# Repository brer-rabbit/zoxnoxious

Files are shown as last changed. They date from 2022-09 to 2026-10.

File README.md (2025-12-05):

# Zoxnoxious Analog Synthesizer #

"Beyond Obnoxious"

Zoxnoxious is a hardware analog music synthesizer with a software interface.  The intent is to provide a platform for card/module development ("card" may be a better term than "module", as the latter is a well established term in the modular synth world).  Cards interface via a Raspberry Pi to a host controller over USB, and the host controller runs VCV Rack which provides control signals.

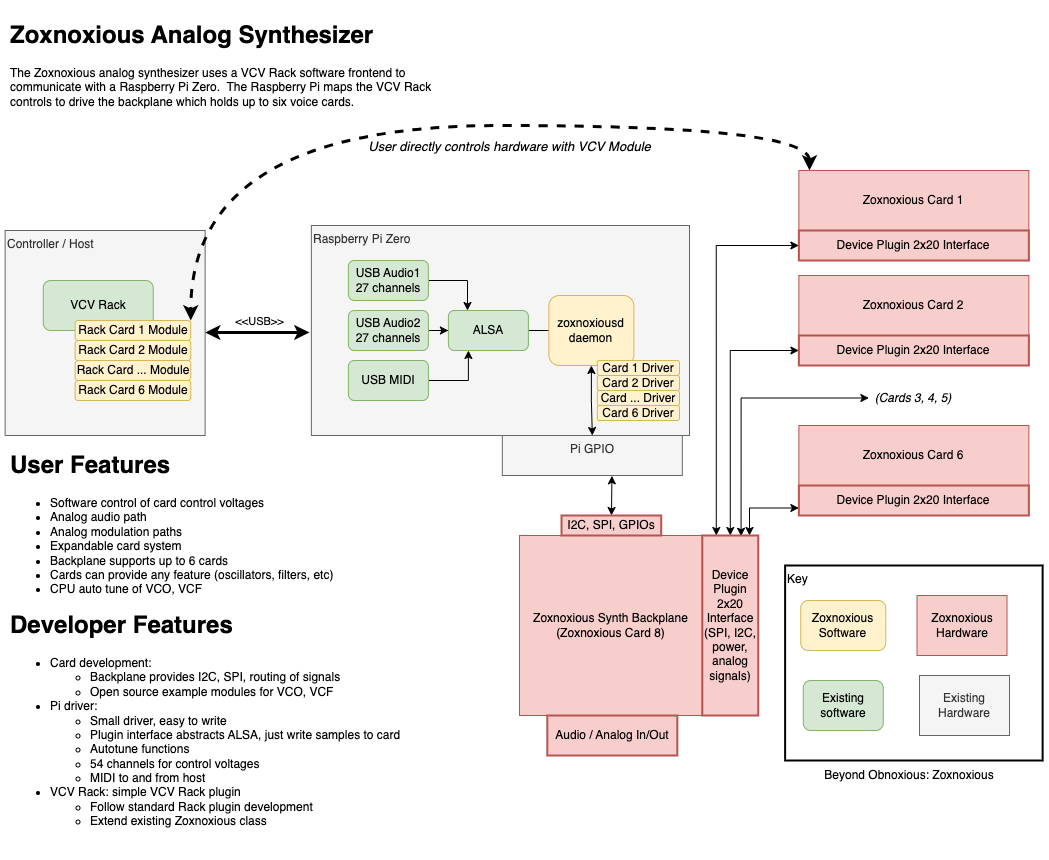
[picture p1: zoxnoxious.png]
Zonoxious Block Diagram


# Z-Cards #

Z-Cards are the voice cards that plug into the Zoxnoxious backplane.  Each card receives digital signals such as I2C and SPI along with analog signals from other Z-Cards.  Then each Z-Card drives a defined set of pins with its own analog output.

The Z-Cards are agnostic to the microcontroller; the interface being I2C and SPI most any microcontroller can be used.  While the overall Zoxnoxious project focuses on a Raspberry Pi implementation a different project can pickup the voice cards and do something different.  These cards are ripe for re-use in developing an analog synth with a microcontroller if you want to do your own thing and not use a Raspberry Pi like I have done in this project.

All Z-Cards are in the [kicad](kicad) directory.

Cards developed to date include:

* AS3340 VCO
* AS3372 Signal Processor (VCF, VCA)
* SSI2130/AS3394 Dual VCO + VCF Synth Voice
* Pole Dancer multimode filter with morphing/crossfade

The backplane design allows for up to 8 cards to be addressed with itself counting as one.  One control address goes unused as the backplane board design only has 6 physical slots.

# Raspberry Pi Host #

A Raspberry Pi Zero 2 attaches to the Zoxnoxious backplane.  To a host computer, the Pi appears as USB Audio and USB MIDI devices.  Incoming USB Audio and MIDI are dispatched to a card's driver, which may choose to send SPI or I2C messages to the card.

The application the Pi runs is contained entirely in the [raspberry_pi](raspberry_pi) directory.

# Zoxnoxious plugins for VCV Rack #

The user interacts with the synth through a VCV Rack plugin.  Zoxnoxious VCV Rack plugins map the Rack modules to audio channels and MIDI events that are sent via USB to the synthesizer.

These are all contained in the [vcv_rack](vcv_rack) directory.

# Deep Dive Videos

Deep dive 1: Project background and user interface
YouTube Zoxnoxious Deep Dive Video (https://www.youtube.com/watch?v=LsGcW3EjFYo)

Deep dive 2: Raspberry Pi and Gadget mode
YouTube Zoxnoxious Deep Dive Video (https://www.youtube.com/watch?v=pGoO3mSk7ao)

Deep dive 3: Hardware detail and autotune
YouTube Zoxnoxious Deep Dive Video (https://www.youtube.com/watch?v=C-MREijqNOM)

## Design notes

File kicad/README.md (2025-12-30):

# Zoxnoxious KiCad Files

The directories below contain KiCad files for the Zoxnoxious synthesizer.  This includes files for both schematics, PCB layout, and assembly.  Some boards also have a datasheet.

# Voice cards

* [Z2203](z2203/): Yamaha FM-based voice card with YM2203 chip
* [Pole Dancer](poledancer/): pole mixing filter utilizing an SSI2140 and SSI2190
* [Z3340](z3340/): Oscillator based around an AS3340 with four sync modes that can be combined
* [Z3372](z3372/): Lowpass filter with AS3372 filter chip.  Stereo panning, filter and resonance modulation.
* [Z5524](z5524/): dual VCO voice card.  SSI2130 oscillator for TZFM, AS3394 for second VCO and filter.  Powerful.

# Backplane

The [backplane](vca_backplane/) hosts six voice cards and a Raspberry Pi Zero2.

# Frontpanel

[Frontpanel](frontpanel/) for project.

# Template for development

The [zoxnoxiouscard](zoxnoxiouscard/) directory has a template to run from for creating voice cards.  Includes DAC, GPIO expander, and layout for the same.

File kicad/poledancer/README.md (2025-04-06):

# Pole Dancer Multimode Pole Mixing Filter

The Pole Dancer may be the most versatile analog synthesizer filter.  Built around an SSI2140 four pole filter and an SSI2190 mixer provides the pole mixing.  A number of filter modes are possible using the filter mixing.  The real fun is morphing between filter modes, which can be done with manipulating the '2190 mixer.

Multiple resonance compensation modes, in addition to uncompensated, give a wide range of character.

# Block Diagram

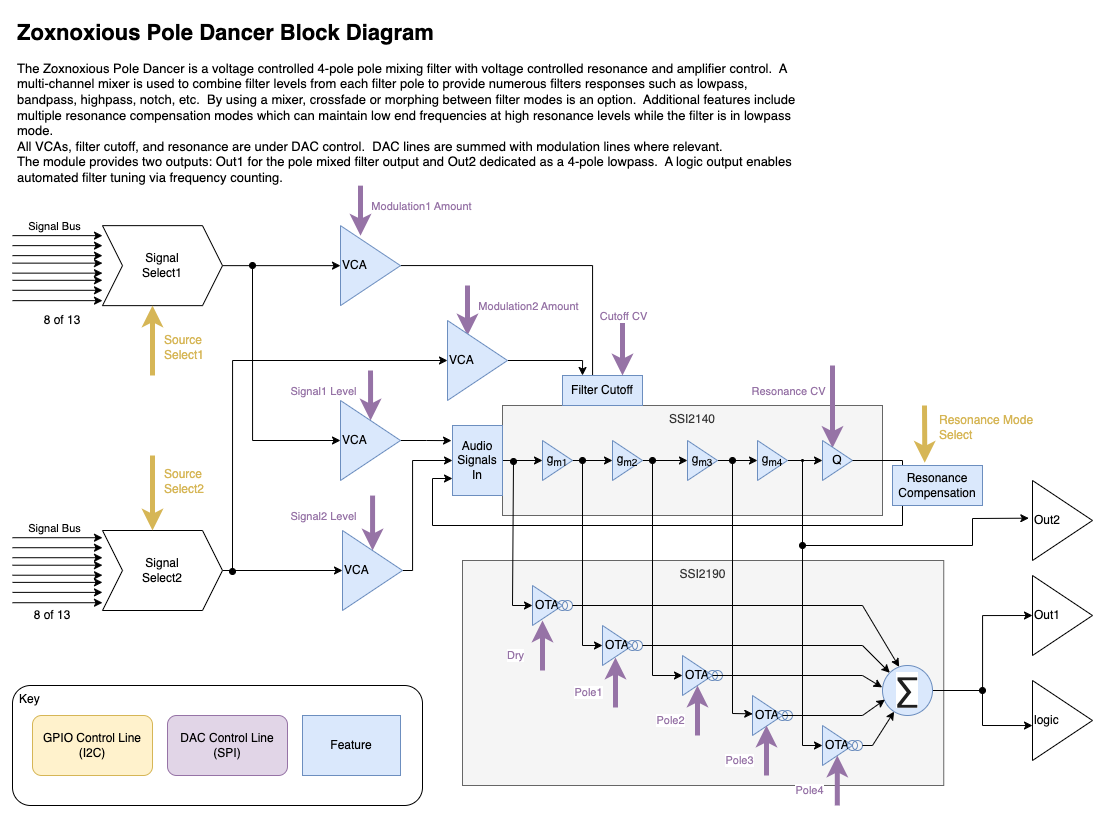
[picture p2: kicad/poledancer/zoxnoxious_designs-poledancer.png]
Pole Dancer Block Diagram


# Resources

Datasheet TBD

[KiCanvas](https://kicanvas.org/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)

# Demo

YouTube Demo

YouTube Z3340 Demo (https://www.youtube.com/watch?v=yQdGTCUl1eU)

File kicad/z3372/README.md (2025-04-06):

# Z3372 Voltage Controlled Filter & Noise Source

The Z3372 Analog Signal Processor utilized Alfa Rpar's AS3372 VCF/VCA.  It also contains a white noise source which can be run through the filter.  Some interseting modulation options are present, along with a stereo output.

# Block Diagram

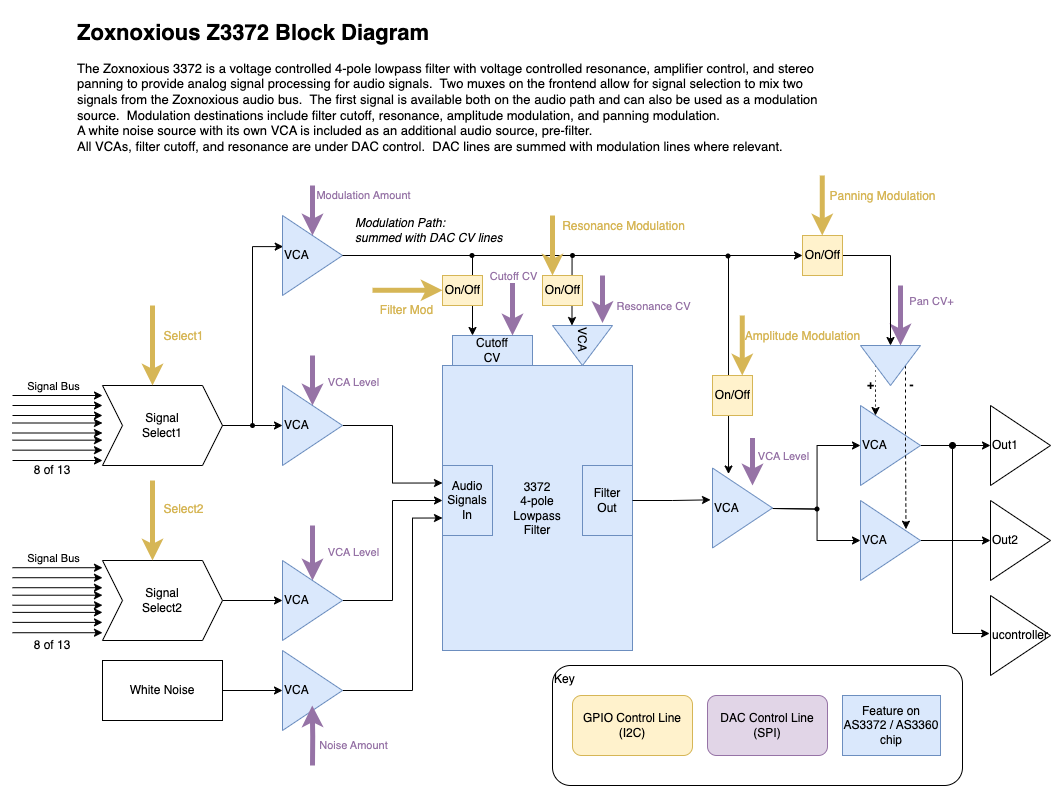
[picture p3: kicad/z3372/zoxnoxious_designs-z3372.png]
Z3372 Block Diagram


# Resources

[Datasheet](datasheet_z3372.pdf)

[KiCanvas](https://kicanvas.org/?github=https%3A%2F%2Fgithub.com%2Fbrer-rabbit%2Fzoxnoxious%2Ftree%2Fmain%2Fkicad%2Fz3372)

# Demo

(old!) YouTube Demo

YouTube Z3373 Demo (https://www.youtube.com/watch?v=ua1Tva17EMw)

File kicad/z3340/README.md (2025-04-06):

# Z3340 Voltage Controlled Oscillator

The Z3340 VCO is based around Alfa Rpar's AS3340 clone of the Curtis chip.  This design, like other Zoxnoxious designs, interfaces with the Zoxnoxious signal bus.

# Block Diagram

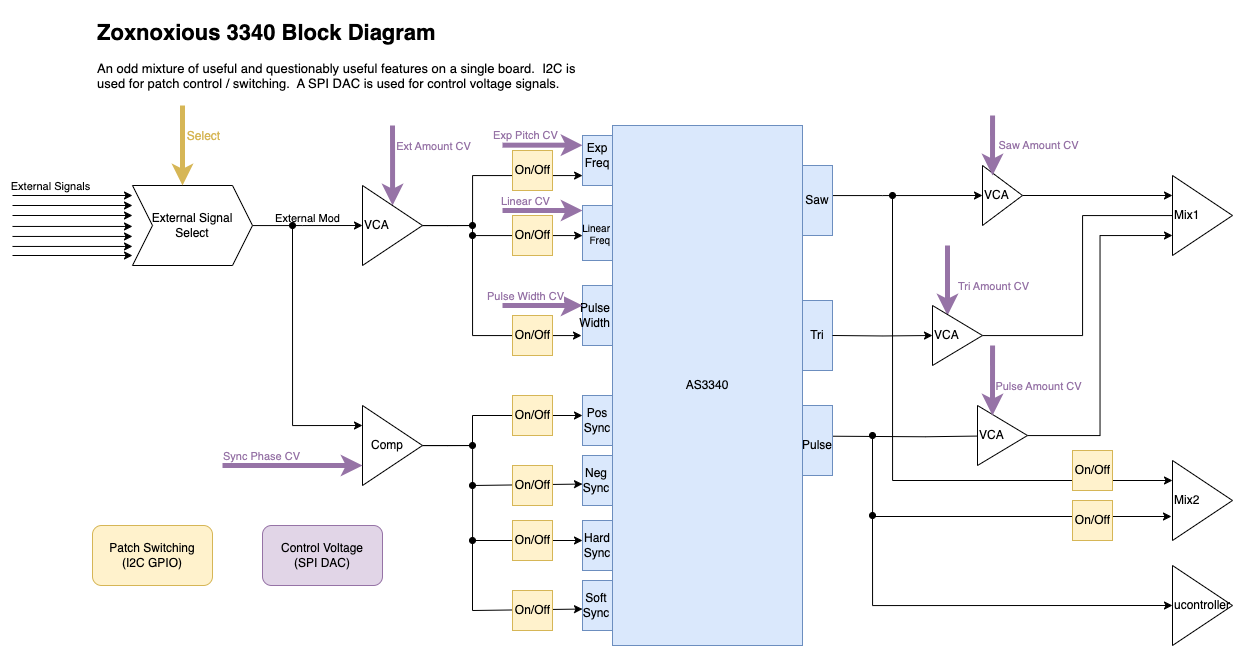
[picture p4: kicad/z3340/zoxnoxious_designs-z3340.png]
Z3340 Block Diagram


# Resources

[Datasheet](datasheet_3340.pdf)

[Kicanvas](https://kicanvas.org/?github=https%3A%2F%2Fgithub.com%2Fbrer-rabbit%2Fzoxnoxious%2Ftree%2Fmain%2Fkicad%2Fz3340)

# Demo

YouTube Demo

YouTube Z3340 Demo (https://www.youtube.com/watch?v=VoswYPXtnXY)

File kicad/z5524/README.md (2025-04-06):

# Z5524 Dual VCO Synth Voice

The Z5524 is a full dual VCO synth voice.  The first VCO is based around an SSI2130 and features thru zero frequency modulation (TZFM).  The second VCO is from the AS3394 synth-on-a-chip.  Both VCOs run through the AS3394's VCF and VCA.

Some unique options with this setup such as combining soft sync with hard subsync, modulating the AS3394's waveselect, and some interesting options for the TZFM modulator from the AS3394 VCO.

# Block Diagram

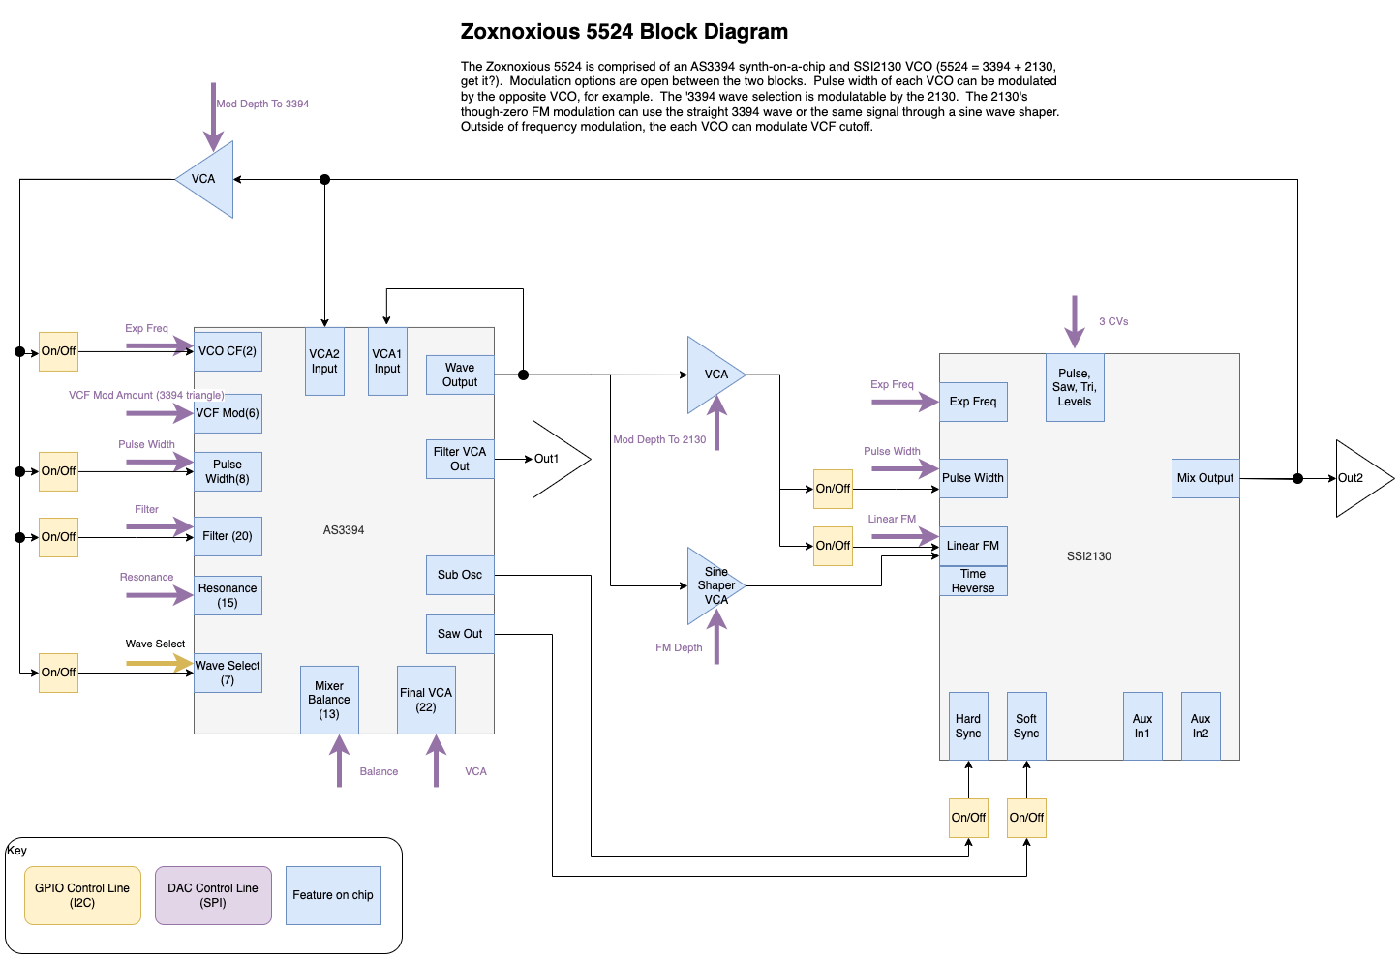
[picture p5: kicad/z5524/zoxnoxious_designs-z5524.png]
Z5524 Block Diagram


# Resources

Datasheet TBD

[KiCanvas](https://kicanvas.org/?github=https%3A%2F%2Fgithub.com%2Fbrer-rabbit%2Fzoxnoxious%2Ftree%2Fmain%2Fkicad%2Fz5524)

# Demo

YouTube Demo

YouTube Z5524 Demo (https://www.youtube.com/watch?v=vYZjghBTEKc)

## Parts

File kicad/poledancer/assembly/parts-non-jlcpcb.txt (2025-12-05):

"Conn_01x01","J1","Connector_PinHeader_2.54mm:PinHeader_1x01_P2.54mm_Vertical",""
"Conn_01x02","J2","Connector_PinHeader_2.54mm:PinHeader_1x02_P2.54mm_Vertical",""
"Conn_02x20_Odd_Even","J3","Connector_PinHeader_2.54mm:PinHeader_2x20_P2.54mm_Horizontal",""
"5k","RV1,RV2","Potentiometer_THT:Potentiometer_Bourns_3296W_Vertical",""
"TestPoint","TP1,TP2,TP3,TP4,TP5,TP6,TP7,TP8,TP9,TP10,TP11,TP12,TP13,TP14,TP15","TestPoint:TestPoint_Pad_2.0x2.0mm",""
"SSI2190","U2","Package_SO:SSOP-24_3.9x8.7mm_P0.635mm",""
"AS3364","U3","Package_SO:SOIC-16_3.9x9.9mm_P1.27mm",""
"SSI2140","U5","Package_SO:SSOP-20_4.4x6.5mm_P0.65mm",""
"1000p","C14,C16,C17,C18","Capacitor_SMD:C_0805_2012Metric",""

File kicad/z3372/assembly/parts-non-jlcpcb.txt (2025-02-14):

"2u2","C34,C38","Capacitor_THT:C_Rect_L7.2mm_W5.5mm_P5.00mm_FKS2_FKP2_MKS2_MKP2",""
"Conn_01x01","J1","Connector_PinHeader_2.54mm:PinHeader_1x01_P2.54mm_Vertical",""
"Conn_02x20_Odd_Even","J2","Connector_PinHeader_2.54mm:PinHeader_2x20_P2.54mm_Horizontal",""
"Conn_01x02","J3","Connector_PinHeader_2.54mm:PinHeader_1x02_P2.54mm_Vertical",""
"TestPoint","TP1,TP2,TP3,TP4,TP5,TP6,TP7,TP8,TP9,TP10,TP11","TestPoint:TestPoint_Pad_2.0x2.0mm",""
"AS3360-Audio","U1","Package_SO:SOIC-14_3.9x8.7mm_P1.27mm",""
"AS3372","U3","Package_SO:SOIC-24W_7.5x15.4mm_P1.27mm",""
"L79L05_TO92","U9","Package_TO_SOT_THT:TO-92_Inline_Wide",""

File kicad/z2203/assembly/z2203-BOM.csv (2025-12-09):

Comment | Designator | Footprint | LCSC
0.1u | C1,C2,C3,C4,C5,C7,C8,C9,C10 | Capacitor_SMD:C_0603_1608Metric | C14663
10u | C6 | Capacitor_SMD:C_0805_2012Metric | C15850
LED | D1,D2 | LED_SMD:LED_0603_1608Metric | C2286
4k7 | R1,R11 | Resistor_SMD:R_0603_1608Metric | C23162
5k1 | R10 | Resistor_SMD:R_0603_1608Metric | C23186
47k | R2,R4,R5,R7,R8,R9 | Resistor_SMD:R_0603_1608Metric | C25819
51 | R3,R6 | Resistor_SMD:R_0603_1608Metric | C23197
74HC00 | U3 | Package_SO:SOIC-14_3.9x8.7mm_P1.27mm | C10090
74HC595 | U4,U7 | Package_SO:TSSOP-16_4.4x5mm_P0.65mm | C273642
TL074 | U5 | Package_SO:TSSOP-14_4.4x5mm_P0.65mm | C96507
M24C02-WMN | U6 | Package_SO:SOIC-8_3.9x4.9mm_P1.27mm | C7562
SX3M3.57 | X1 | Oscillator:Oscillator_SMD_Abracon_ASE-4Pin_3.2x2.5mm | C41361373

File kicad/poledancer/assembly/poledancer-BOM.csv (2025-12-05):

Comment | Designator | Footprint | LCPCB Part #
4n7 | C13 | Capacitor_SMD:C_0603_1608Metric | C53987
2u2 | C21 | Capacitor_SMD:C_0603_1608Metric | C23630
22n | C23,C39,C40,C41 | Capacitor_SMD:C_0603_1608Metric | C21122
0.1u | C1,C2,C3,C4,C5,C8,C10,C11,C12,C15,C19,C20,C24,C26,C28,C29,C31,C32,C33,C35,C37,C38,C42,C43,C45 | Capacitor_SMD:C_0603_1608Metric | C14663
22p | C30 | Capacitor_SMD:C_0603_1608Metric | C1653
100p | C36 | Capacitor_SMD:C_0603_1608Metric | C14858
4u7 | C9,C44 | Capacitor_SMD:C_0603_1608Metric | C19666
47n | C6,C7,C22,C25,C27,C34 | Capacitor_SMD:C_0603_1608Metric | C1622
1N4148W | D1 | Diode_SMD:D_SOD-123 | C81598
LED | D2 | LED_SMD:LED_0603_1608Metric | C2286
MMBT3904 | Q1 | Package_TO_SOT_SMD:SOT-23 | C20526
20k | R1,R2,R18,R19,R24,R28,R33,R41,R56,R61,R67 | Resistor_SMD:R_0603_1608Metric | C4184
6k2 | R13,R14,R16,R17,R40,R48,R50,R51,R53,R55,R57 | Resistor_SMD:R_0603_1608Metric | C4260
3k9 | R15,R54 | Resistor_SMD:R_0603_1608Metric | C23018
15k | R23,R43,R70 | Resistor_SMD:R_0603_1608Metric | C22809
100 | R29 | Resistor_SMD:R_0603_1608Metric | C22775
220 | R3,R5,R7,R8,R20,R21,R22,R26,R27,R30,R31,R32 | Resistor_SMD:R_0603_1608Metric | C22962
12k | R38 | Resistor_SMD:R_0603_1608Metric | C22790
1k | R44 | Resistor_SMD:R_0603_1608Metric | C21190
3k | R52,R72 | Resistor_SMD:R_0603_1608Metric | C4211
100k | R4,R25,R58,R60,R63,R64 | Resistor_SMD:R_0603_1608Metric | C25803
5k1 | R59 | Resistor_SMD:R_0603_1608Metric | C23186
200 | R6,R35,R46,R47 | Resistor_SMD:R_0603_1608Metric | C8218
51 | R62,R65 | Resistor_SMD:R_0603_1608Metric | C23197
150k | R66 | Resistor_SMD:R_0603_1608Metric | C22807
33k | R68 | Resistor_SMD:R_0603_1608Metric | C4216
24k | R69 | Resistor_SMD:R_0603_1608Metric | C23352
82k | R73,R79,R80,R81 | Resistor_SMD:R_0603_1608Metric | C23254
18k | R12,R74,R76,R77,R78 | Resistor_SMD:R_0603_1608Metric | C25810
10k | R9,R10,R11,R34,R36,R37,R39,R42,R45,R49,R71,R75,R83 | Resistor_SMD:R_0603_1608Metric | C25804
4k7 | R82 | Resistor_SMD:R_0603_1608Metric | C23162
TL074 | U1,U4,U10 | Package_SO:TSSOP-14_4.4x5mm_P0.65mm | C96507
M24C02-WMN | U12 | Package_SO:SOIC-8_3.9x4.9mm_P1.27mm | C7562
PCA9555D | U13 | Package_SO:TSSOP-24_4.4x7.8mm_P0.65mm | C83265
AD5328 | U6,U14 | Package_SO:TSSOP-16_4.4x5mm_P0.65mm | C29162
DG442xY | U7 | Package_SO:SOIC-16_3.9x9.9mm_P1.27mm | C2673321
LM4040AIM3-2.5 | U8 | Package_TO_SOT_SMD:SOT-23 | C111866
PS508 | U9,U11 | Package_SO:SOIC-16_3.9x9.9mm_P1.27mm | C2673104

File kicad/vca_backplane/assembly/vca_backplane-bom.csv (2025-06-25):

Comment | Designator | Footprint | LCSC Part #
4.7u | C1 | Capacitor_SMD:C_0805_2012Metric | C1779
4.7n | C11 | Capacitor_SMD:C_0603_1608Metric | C53987
100p | C24,C25 | Capacitor_SMD:C_0603_1608Metric | C14858
0.1u | C2,C3,C4,C5,C6,C7,C8,C9,C10,C13,C14,C15,C16,C17,C18,C20,C21,C22,C23,C26,C27 | Capacitor_SMD:C_0603_1608Metric | C14663
LED | D1 | LED_SMD:LED_0603_1608Metric | C2286
DMG2305UX | Q1 | project_footprints:SOT-23-DMG2305UX | C150470
DMMT5401 | Q2 | Package_TO_SOT_SMD:SOT-23-6 | C154733
BSS138 | Q3,Q4 | Package_TO_SOT_SMD:SOT-23 | C82045
51 | R13 | Resistor_SMD:R_0603_1608Metric | C23197
4k7 | R18 | Resistor_SMD:R_0603_1608Metric | C23162
100 | R27,R28 | Resistor_SMD:R_0603_1608Metric | C22775
47k | R1,R4,R5,R9,R10,R12,R14,R17,R19,R21,R22,R23,R24,R25,R26 | Resistor_SMD:R_0603_1608Metric | C25819
10k | R2,R3,R6,R15,R16 | Resistor_SMD:R_0603_1608Metric | C25804
3k3 | R7,R8 | Resistor_SMD:R_0603_1608Metric | C22978
DG442xY | U1,U9,U12 | Package_SO:SOIC-16_3.9x9.9mm_P1.27mm | C2673321
74HCT138 | U10,U11 | Package_SO:TSSOP-16_4.4x5mm_P0.65mm | C8115
NE5532 | U13 | Package_SO:SOIC-8_3.9x4.9mm_P1.27mm | C7426
TL072 | U2 | Package_SO:SOIC-8_3.9x4.9mm_P1.27mm | C6961
MCP4822 | U3 | Package_SO:SOIC-8_3.9x4.9mm_P1.27mm | C16040
M24C02-WMN | U4 | Package_SO:SOIC-8_3.9x4.9mm_P1.27mm | C7562
74HCT245 | U6 | Package_SO:TSSOP-20_4.4x6.5mm_P0.65mm | C5980
74LVC245 | U7 | Package_SO:TSSOP-20_4.4x6.5mm_P0.65mm | C6082
PCA9555PW | U8 | Package_SO:TSSOP-24_4.4x7.8mm_P0.65mm | C83265

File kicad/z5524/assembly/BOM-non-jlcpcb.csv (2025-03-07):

Item | Qty | Reference(s) | Value | LibPart | Footprint | Datasheet | DNP | Digikey | Kemet | LCSC | Mouser | Rubycon | Sim.Device | Sim.Pins | TDK
10 | 2 | C33, C45 | 4u7 | Device:C_Polarized | Capacitor_THT:CP_Radial_D4.0mm_P2.00mm | ~ |  | 1189-4115-ND |  |  |  | 35MS54R7MEFC4X5
13 | 3 | C44, C50, C53 | 33n | Device:C | Capacitor_SMD:C_0805_2012Metric | ~ |  | 445-7523-1-ND |  |  |  |  |  |  | C2012C0G1H333J125AA
16 | 2 | C59, C63 | 1u | Device:C_Polarized | Capacitor_Tantalum_SMD:CP_EIA-3216-10_Kemet-I | ~ |  |  | T491A105K016AT |  | 80-T491A105K016
17 | 1 | C60 | 2n | Device:C | Capacitor_SMD:C_1206_3216Metric | ~ |  | C1206X202FBGAC7800
22 | 1 | J1 | Conn_01x01 | Connector_Generic:Conn_01x01 | Connector_PinHeader_2.54mm:PinHeader_1x01_P2.54mm_Vertical | ~
23 | 1 | J2 | Conn_02x20_Odd_Even | Connector_Generic:Conn_02x20_Odd_Even | Connector_PinHeader_2.54mm:PinHeader_2x20_P2.54mm_Horizontal | ~
24 | 1 | J3 | Conn_01x02 | Connector_Generic:Conn_01x02 | Connector_PinHeader_2.54mm:PinHeader_1x02_P2.54mm_Vertical | ~
59 | 2 | RV1, RV2 | 5k | Device:R_Potentiometer | Potentiometer_THT:Potentiometer_Bourns_3296W_Vertical | ~
60 | 11 | TP1, TP2, TP3, TP4, TP5, TP6, TP7, TP8, TP9, TP10, TP11 | TestPoint | Connector:TestPoint | TestPoint:TestPoint_Pad_1.5x1.5mm | ~
62 | 1 | U2 | SSI2130_no_pad | z5524:SSI2130_no_pad | project_footprints:QFN-32-1EP_4x4mm_P0.4mm_EP2.65x2.65mm_Handsolder_NoPad | https://www.soundsemiconductor.com/downloads/ssi2130datasheet.pdf
64 | 2 | U4, U18 | AD5328 | z5524:AD5328 | Package_SO:TSSOP-16_4.4x5mm_P0.65mm | https://www.analog.com/en/products/ad5308.html |  |  |  | C29162
65 | 1 | U6 | AS3364 | z5524:AS3364 | Package_SO:SOIC-16_3.9x9.9mm_P1.27mm | https://cabintechglobal.com/pdf/ALFA_RPAR_AS3364.pdf
68 | 1 | U9 | LM337L_TO92 | Regulator_Linear:LM337L_TO92 | Package_TO_SOT_THT:TO-92_Inline_Wide | http://www.ti.com/lit/ds/symlink/lm337l.pdf
71 | 1 | U15 | AS3394 | z5524:AS3394 | Package_SO:SOIC-24W_7.5x15.4mm_P1.27mm

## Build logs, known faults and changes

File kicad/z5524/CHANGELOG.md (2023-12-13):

# Changelog

	## V0.3 12/12/2023
	### Changes
	- All VCAs lowered RC filters to few hundred hertz
	- Pulse width modulation on both VCOs use summing amps, not passive
	- Remove extraneous opamps
	- Wave select modulation increased
	- Wave select bias points changed
	- 3394 VCO output increased amplification
	- 3394 VCO frequency range increased
	- 3394 VCF range adjused
	- Frequency Modulation amount greatly increased
	- 2130 Levels reduced to match 3394

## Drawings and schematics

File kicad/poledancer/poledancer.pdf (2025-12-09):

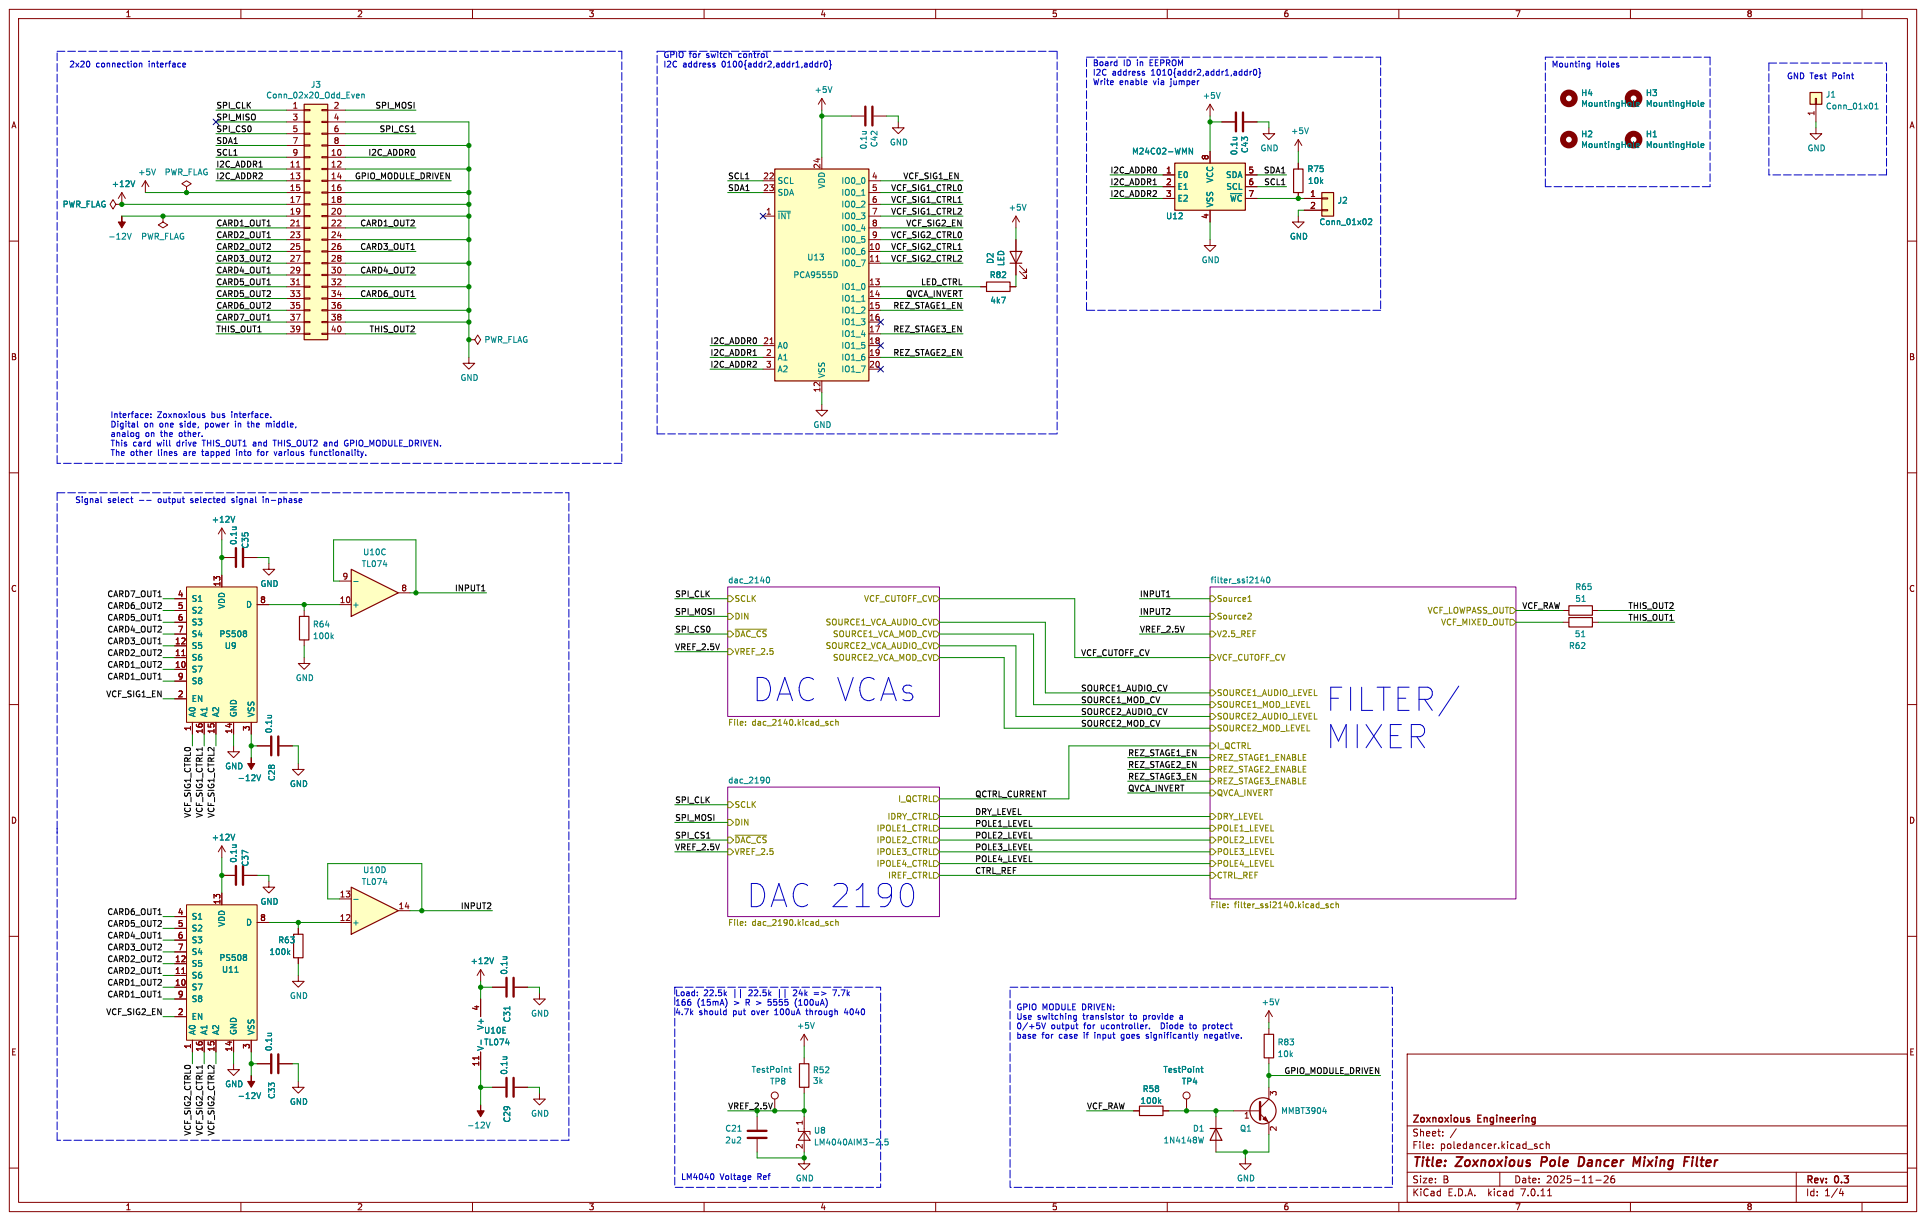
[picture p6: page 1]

GND Test Point GPIO for switch control I2C address 0100{addr2,addr1,addr0}
Mounting Holes FILTER/

Board ID in EEPROM
I2C address 1010{addr2,addr1,addr0} Write enable via jumper

4 SDA 5 SCL 6 ~{WC}7 VCC

1 S7 10 S6 11 S5 12 VDD 13 GND 14 A2 15 A1 16 EN 2 VSS

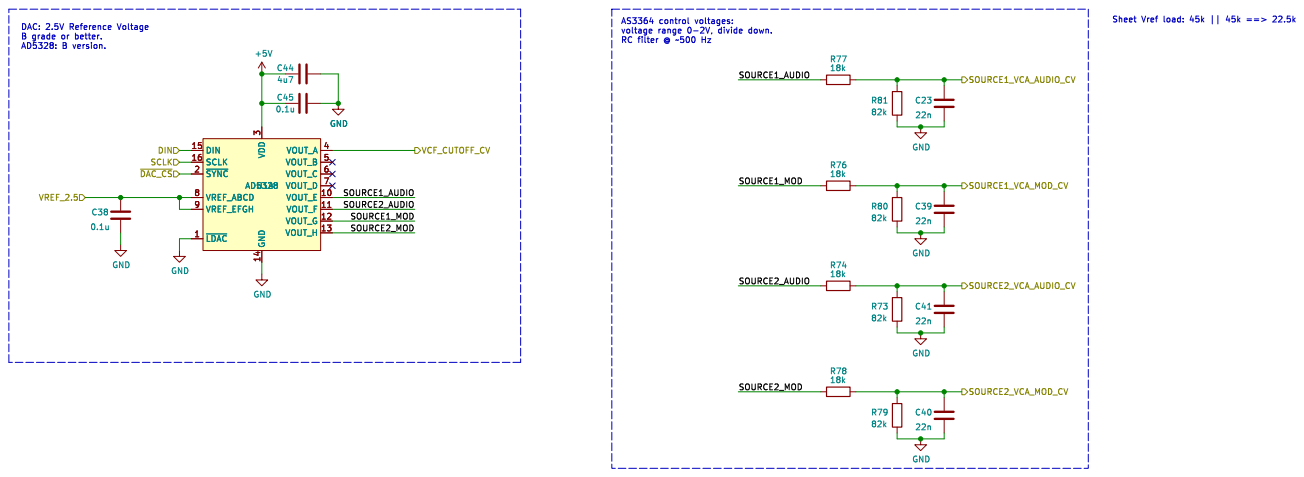
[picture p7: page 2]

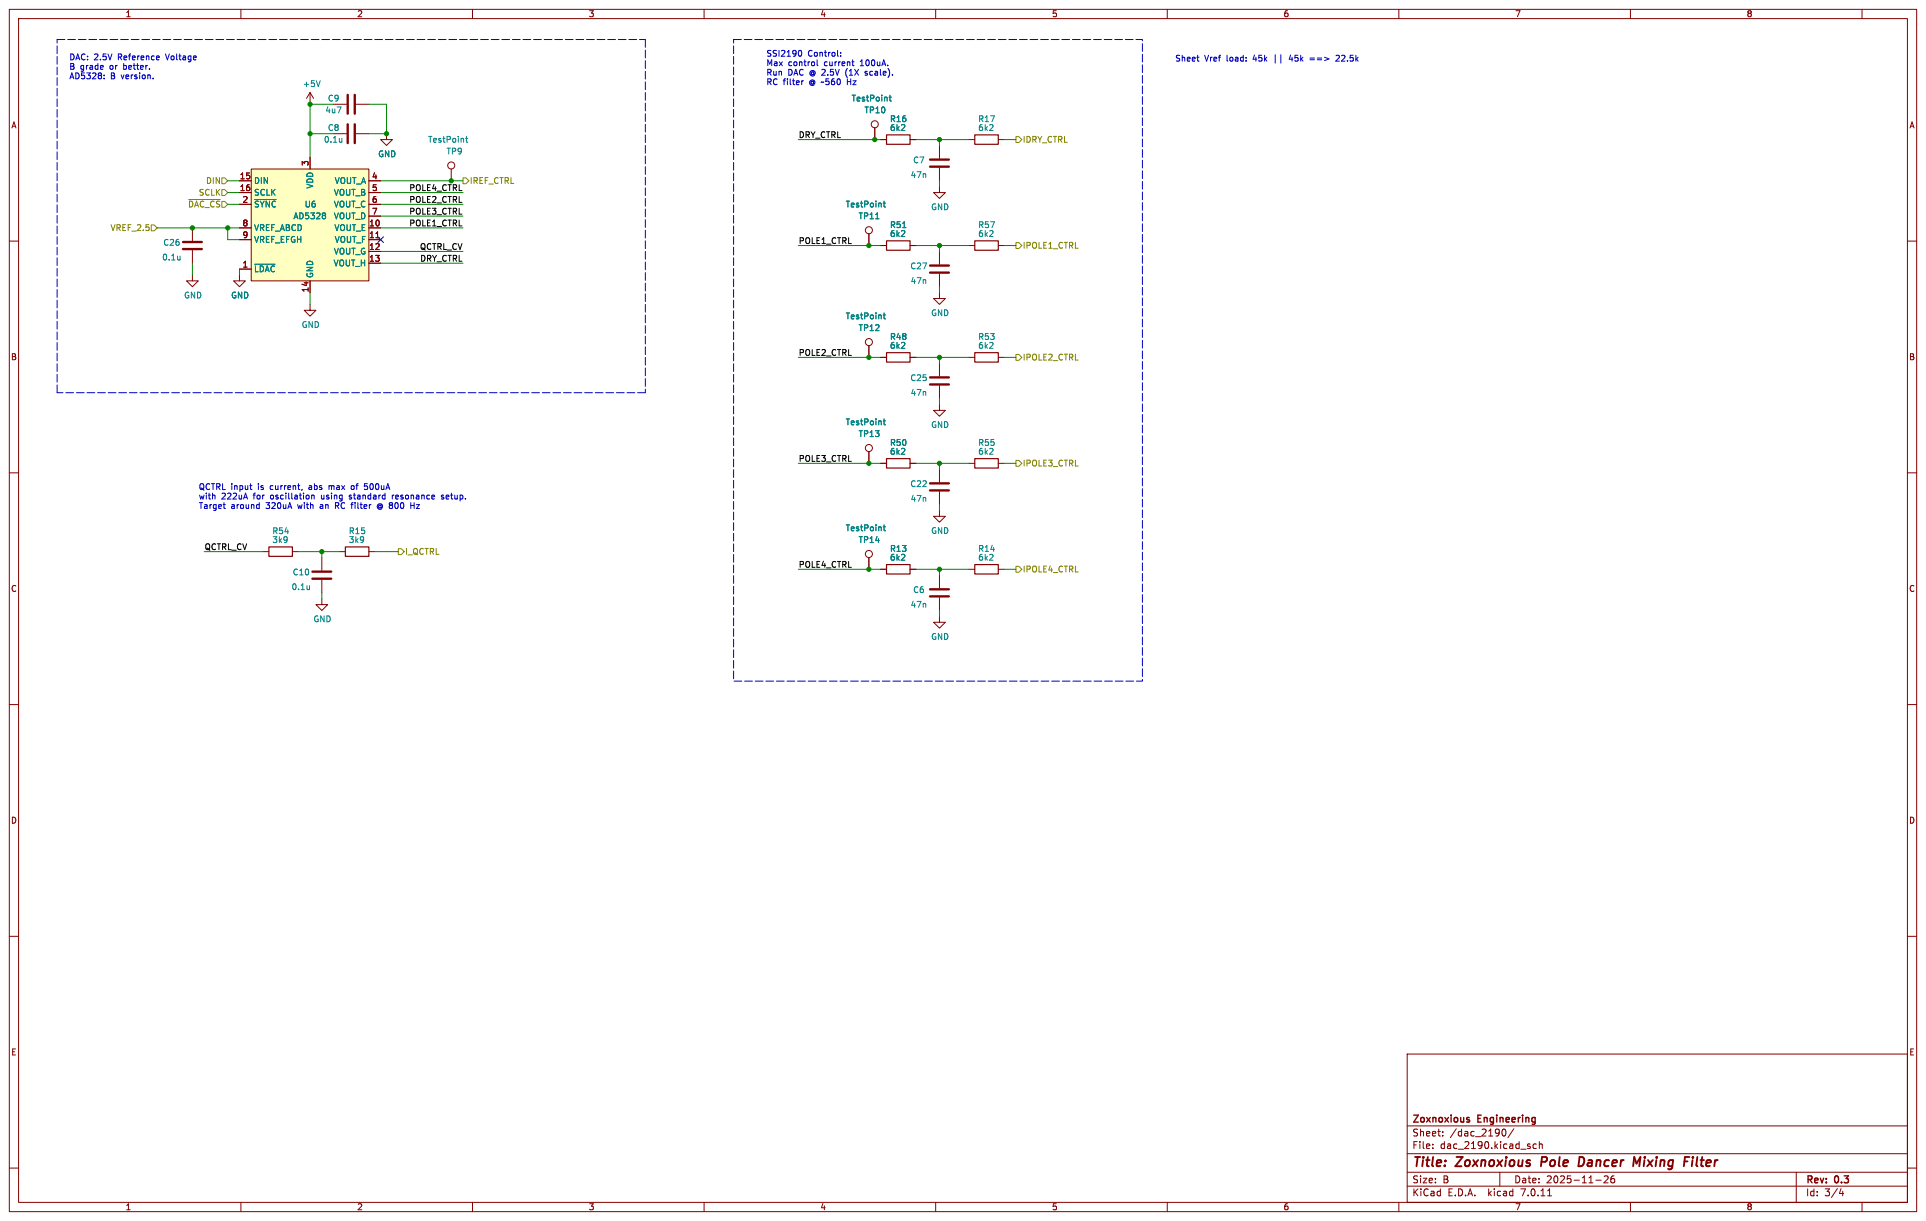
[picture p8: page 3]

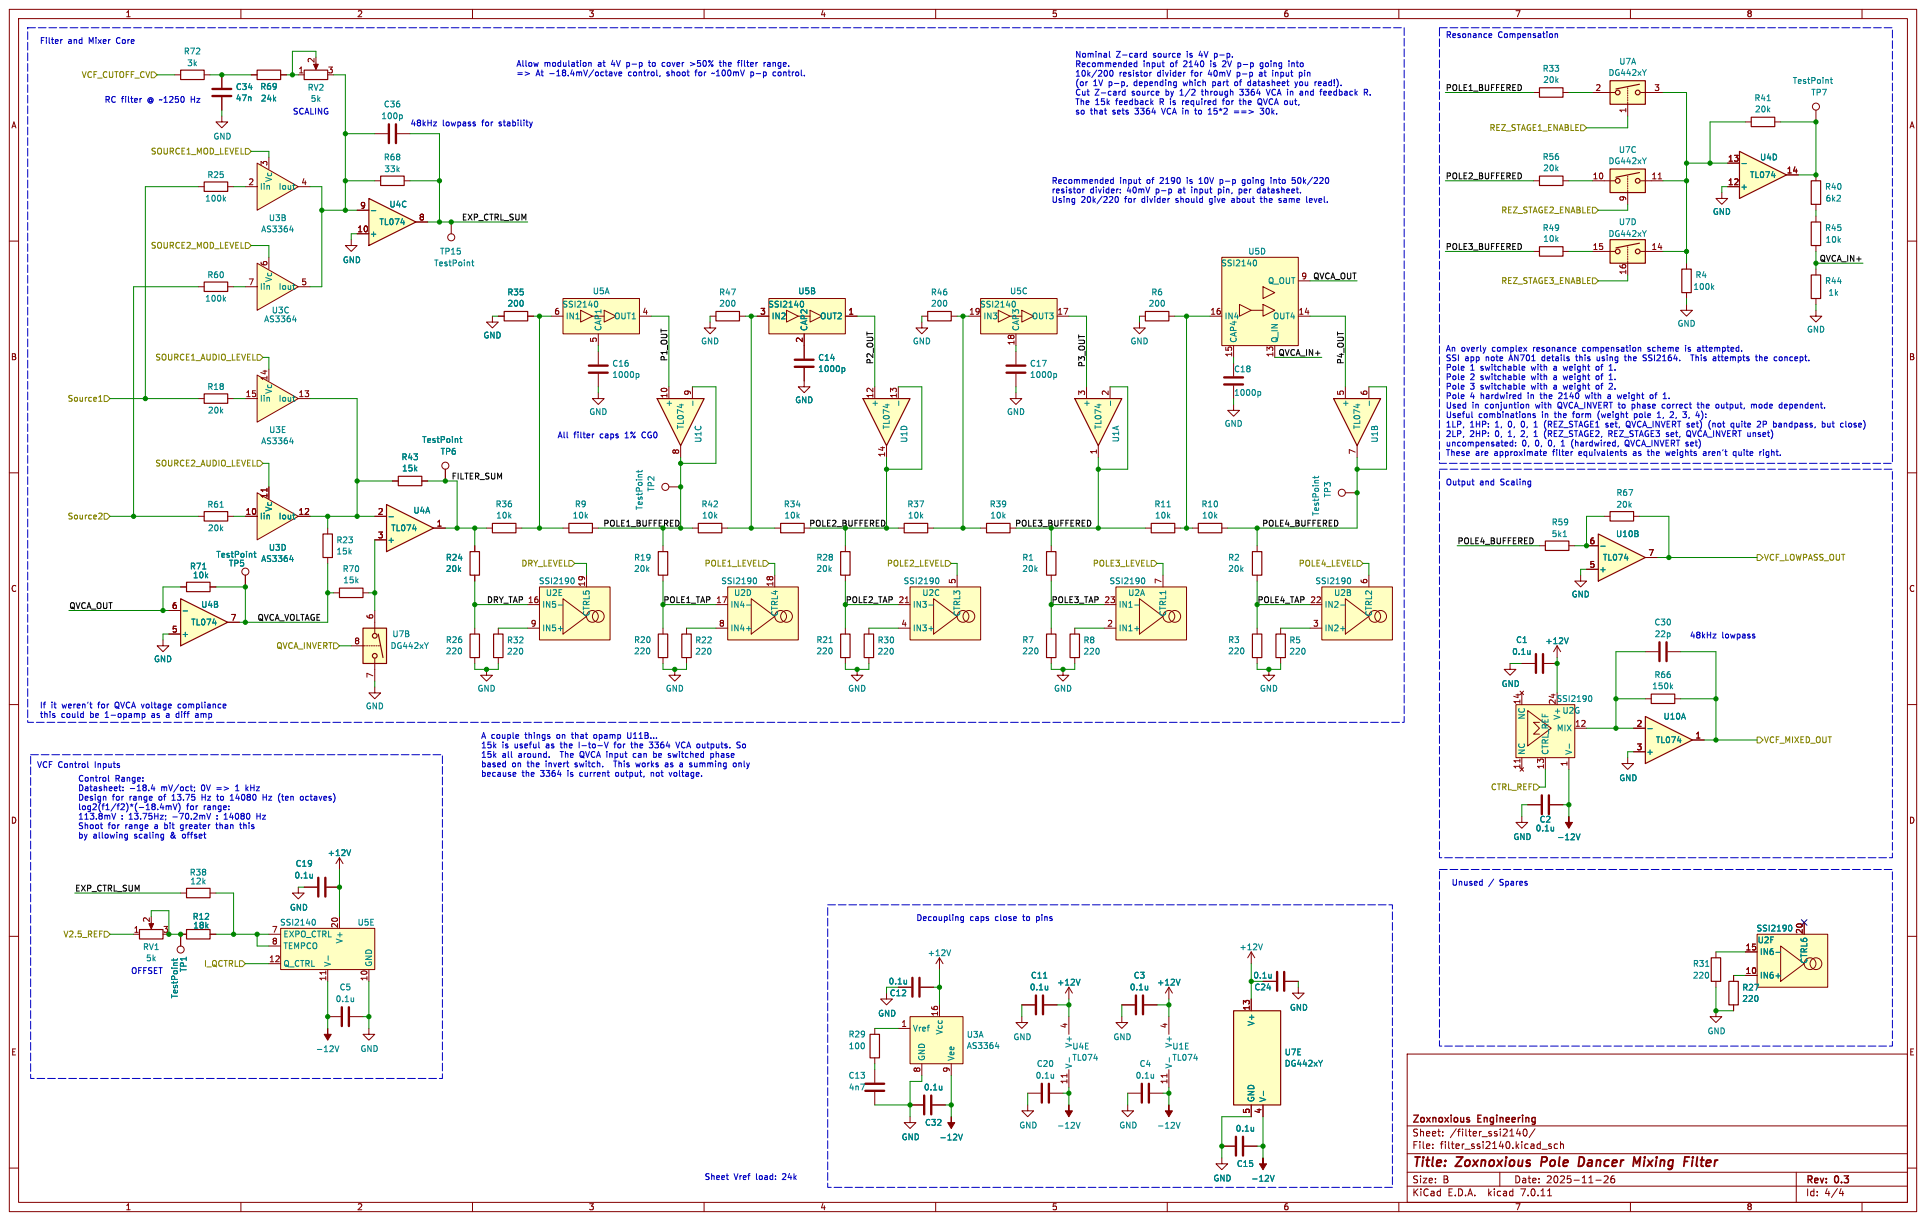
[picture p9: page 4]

Filter and Mixer Core

Output and Scaling OFFSET

If it weren't for QVCA voltage compliance

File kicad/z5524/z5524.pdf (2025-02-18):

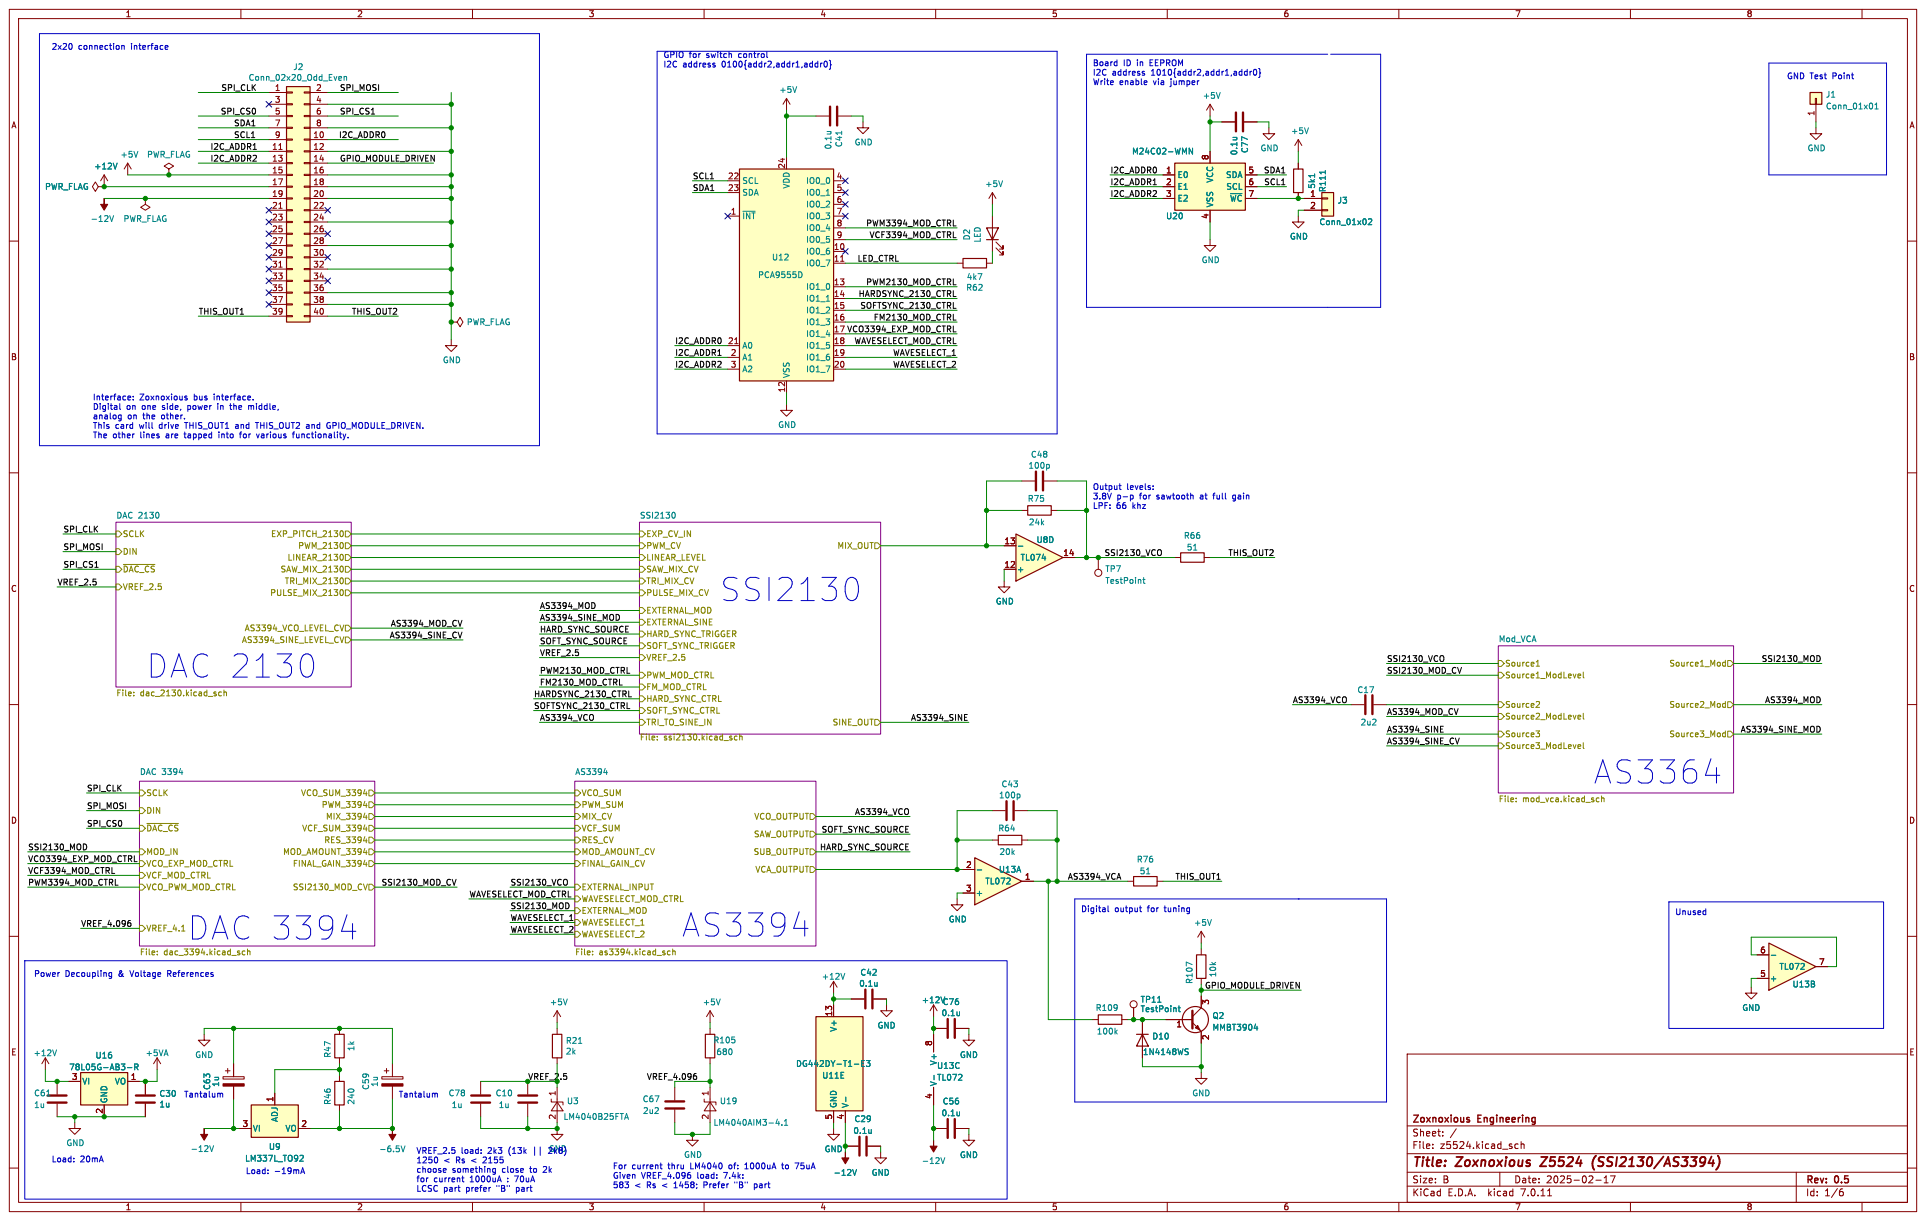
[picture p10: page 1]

GPIO for switch control I2C address 0100{addr2,addr1,addr0}

Board ID in EEPROM
I2C address 1010{addr2,addr1,addr0} Write enable via jumper

4 SDA 5 SCL 6 ~{WC}7 VCC

Digital output for tuning

for current 1000uA : 70uA
LCSC part prefer "B" part

For current thru LM4040 of: 1000uA to 75uA Given VREF_4.096 load: 7.4k: 583 < Rs < 1458; Prefer "B" part

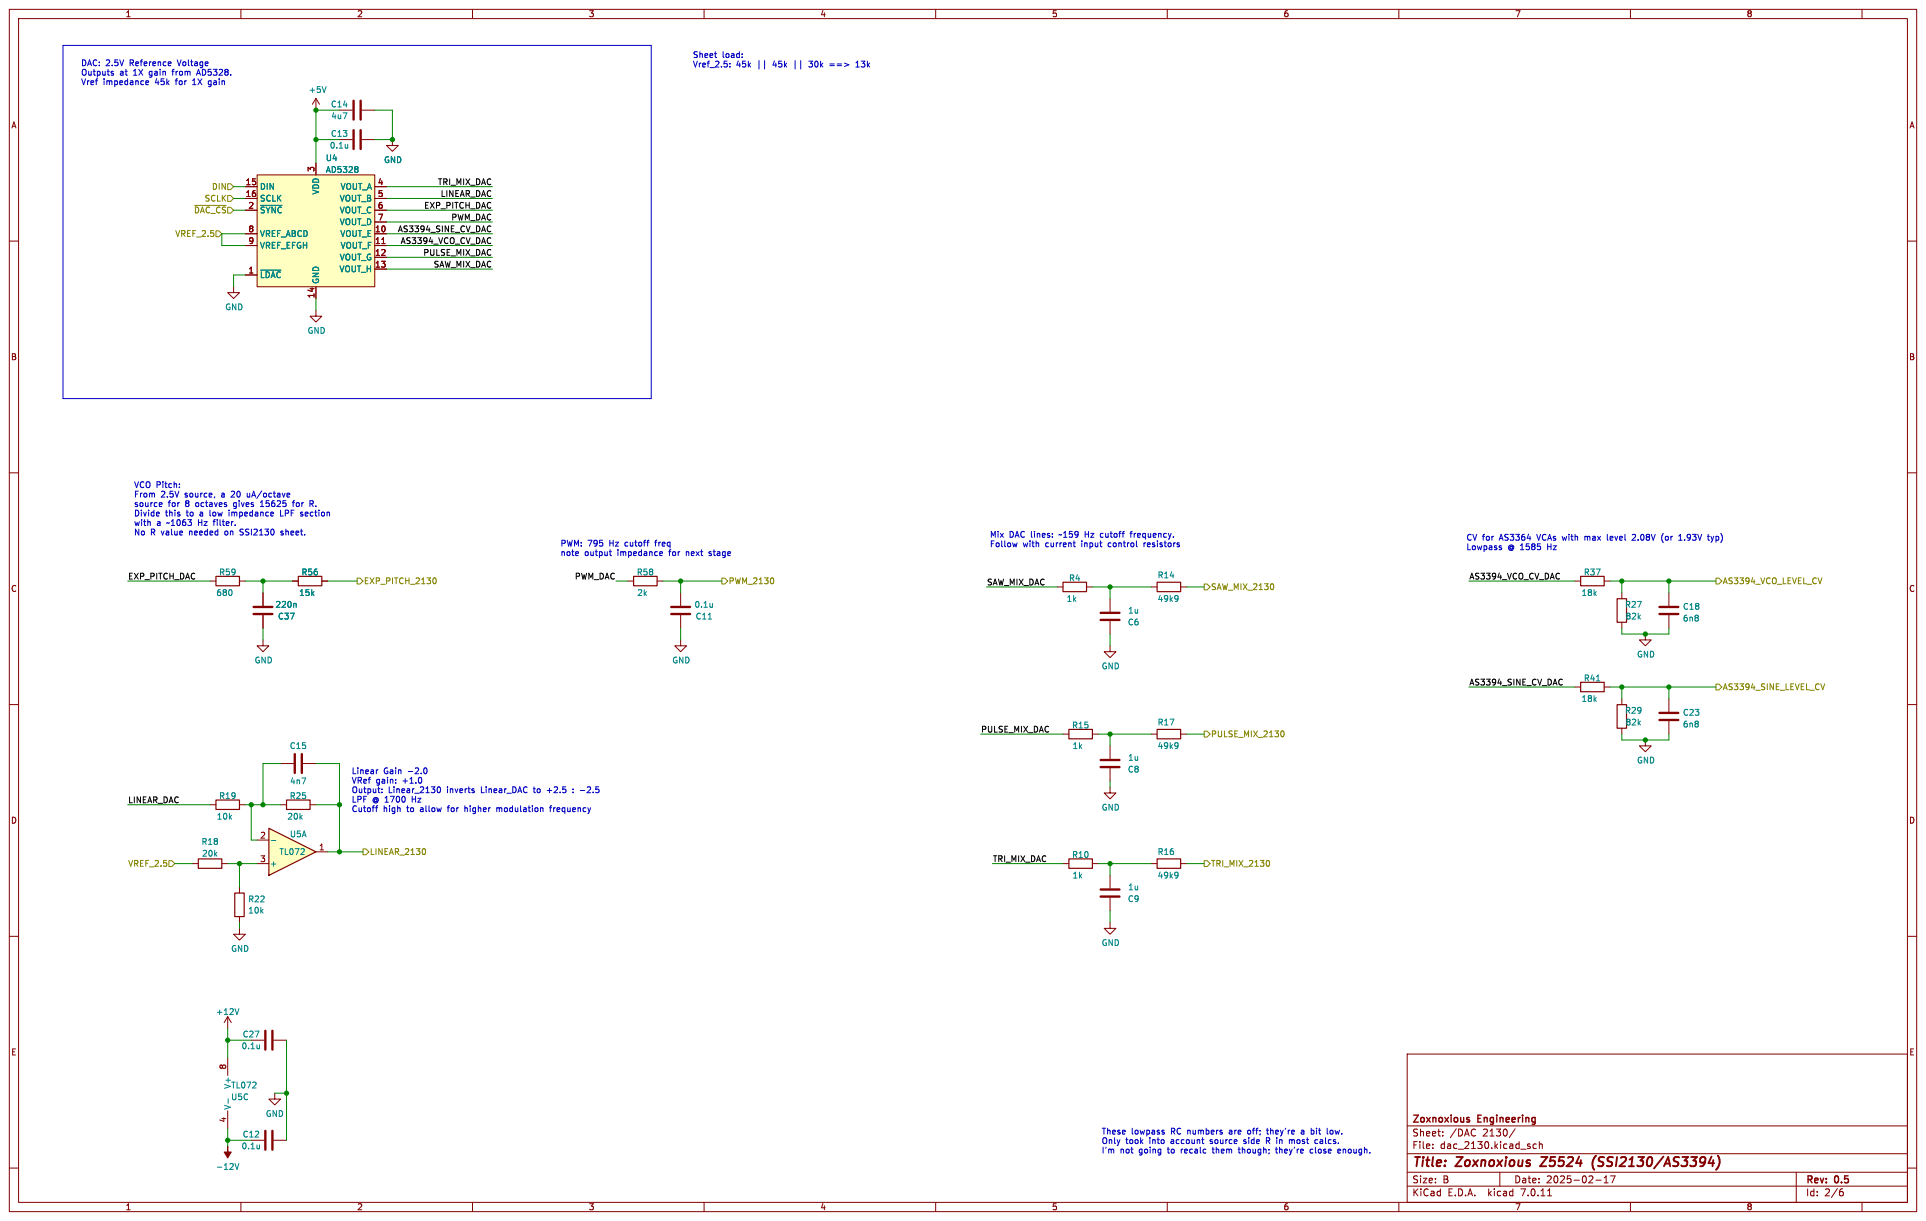
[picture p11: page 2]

These lowpass RC numbers are off; they're a bit low. Only took into account source side R in most calcs.

I'm not going to recalc them though; they're close enough.

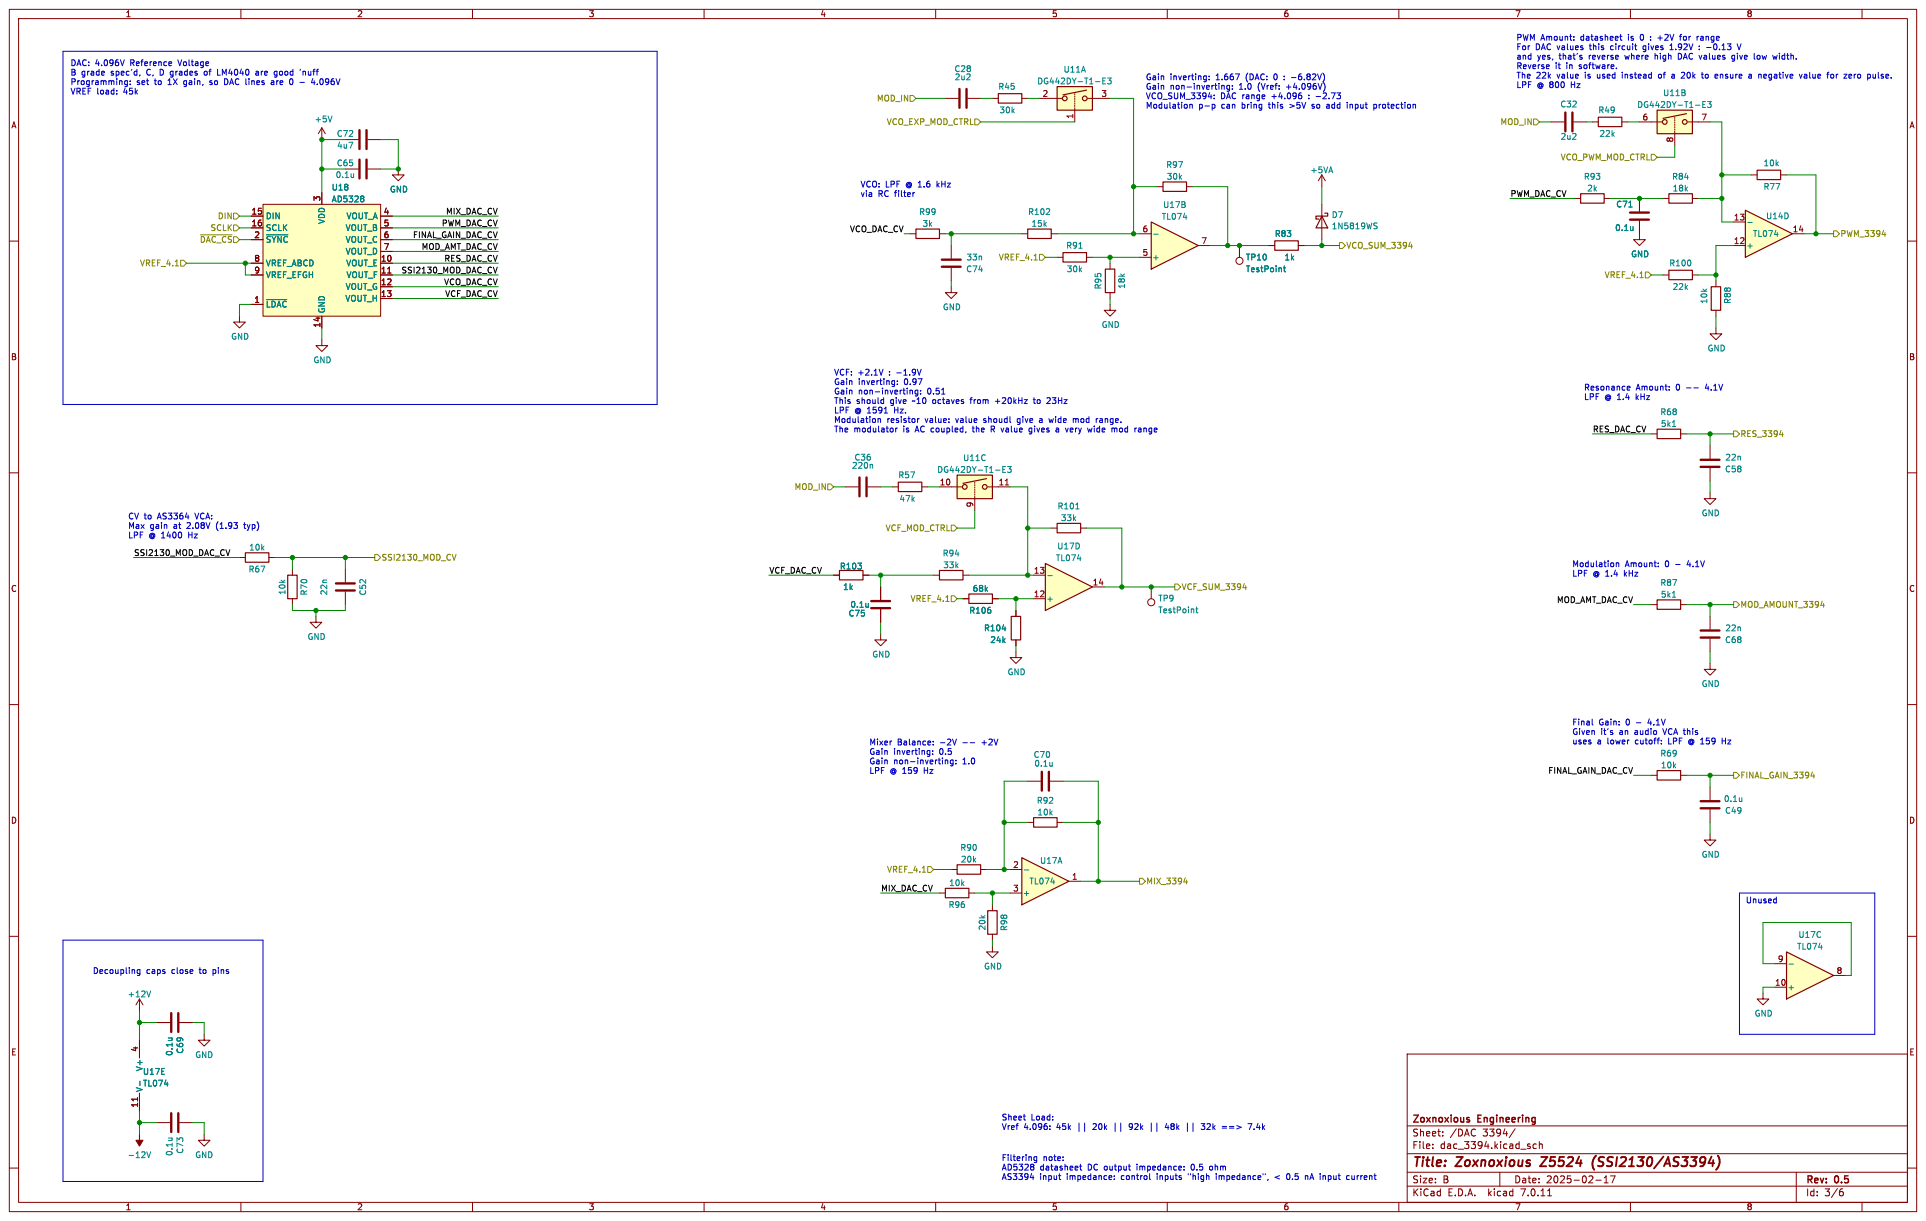
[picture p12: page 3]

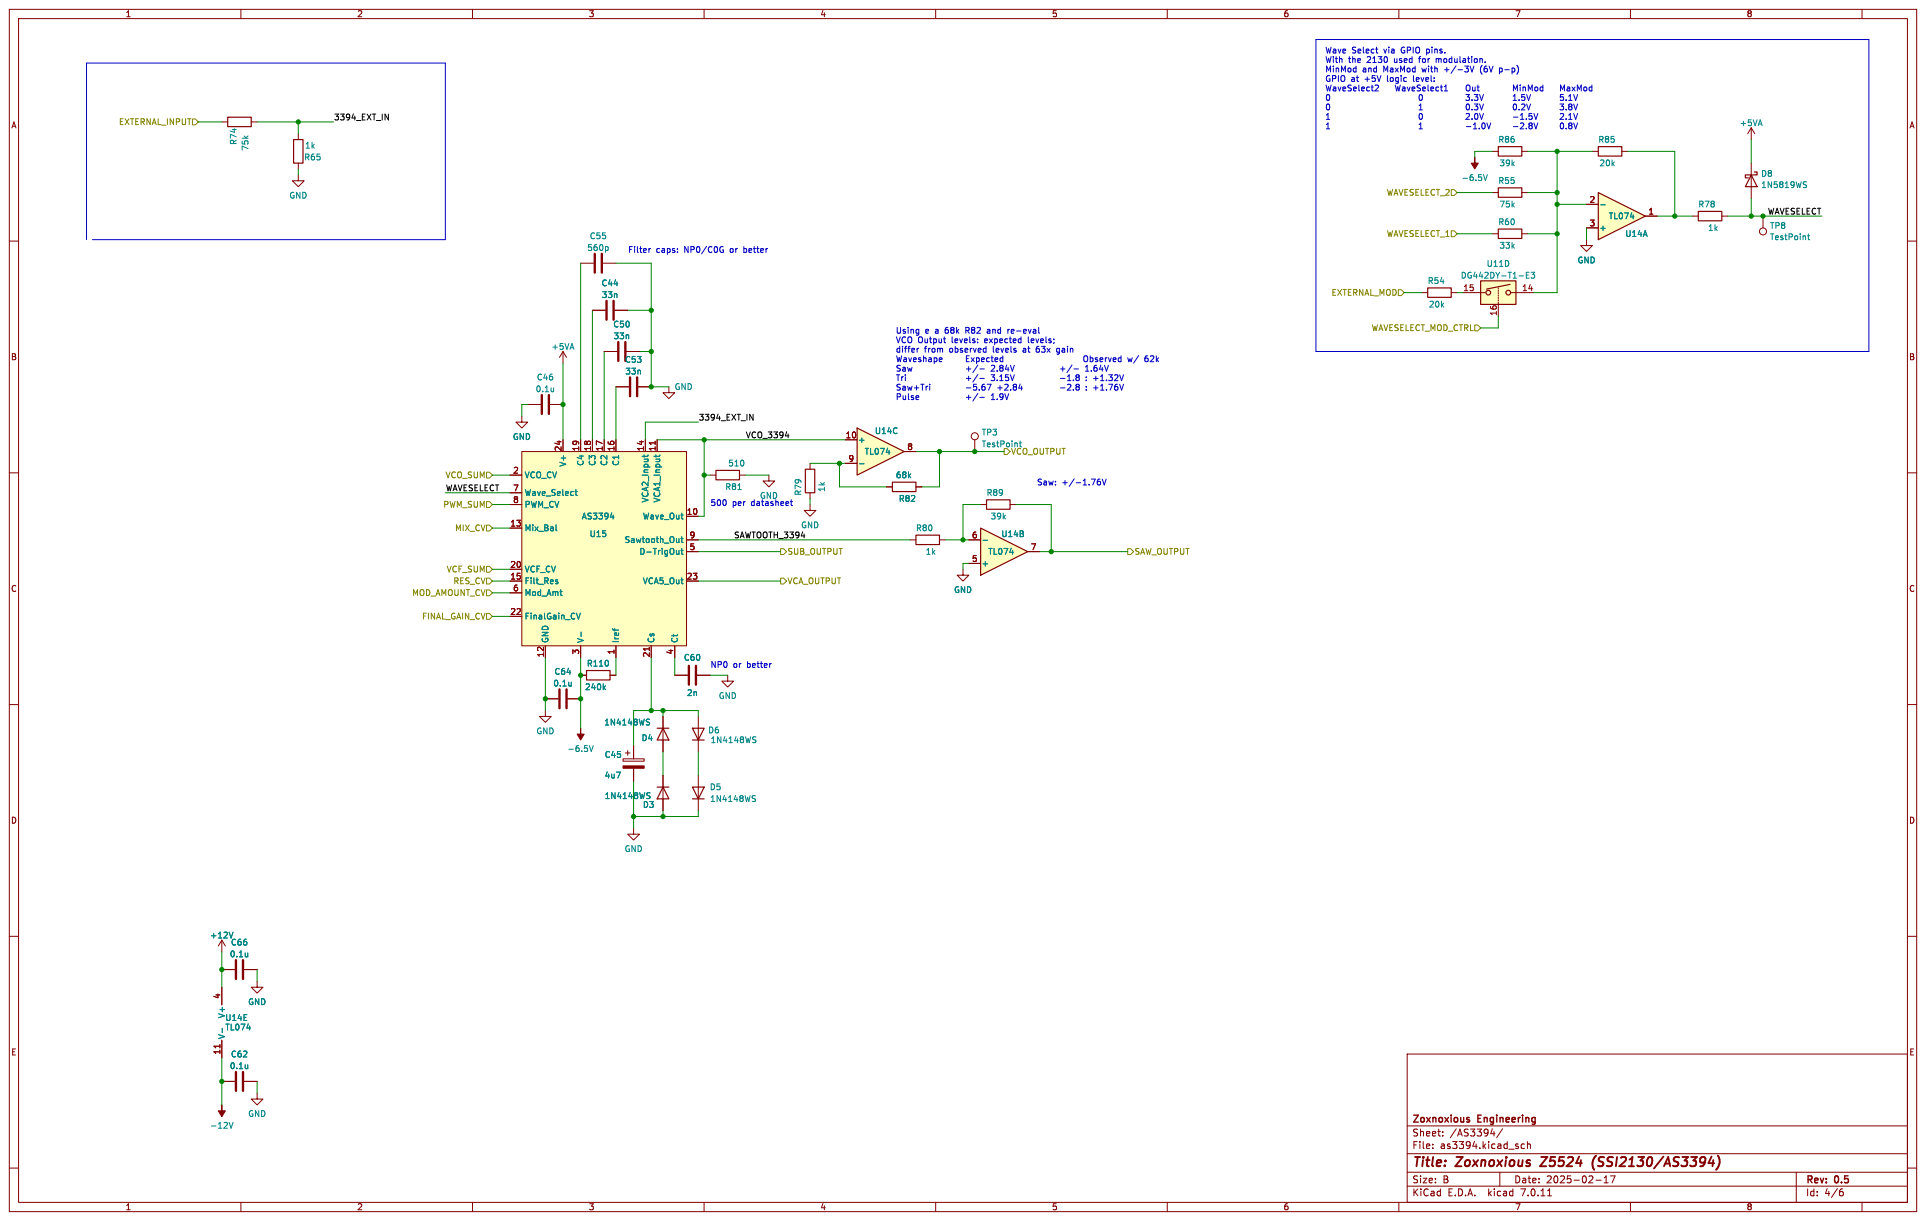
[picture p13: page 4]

1 1 -1.0V -2.8V 0.8V Using e a 68k R82 and re-eval VCO Output levels: expected levels; differ from observed levels at 63x gain
0.1u GND

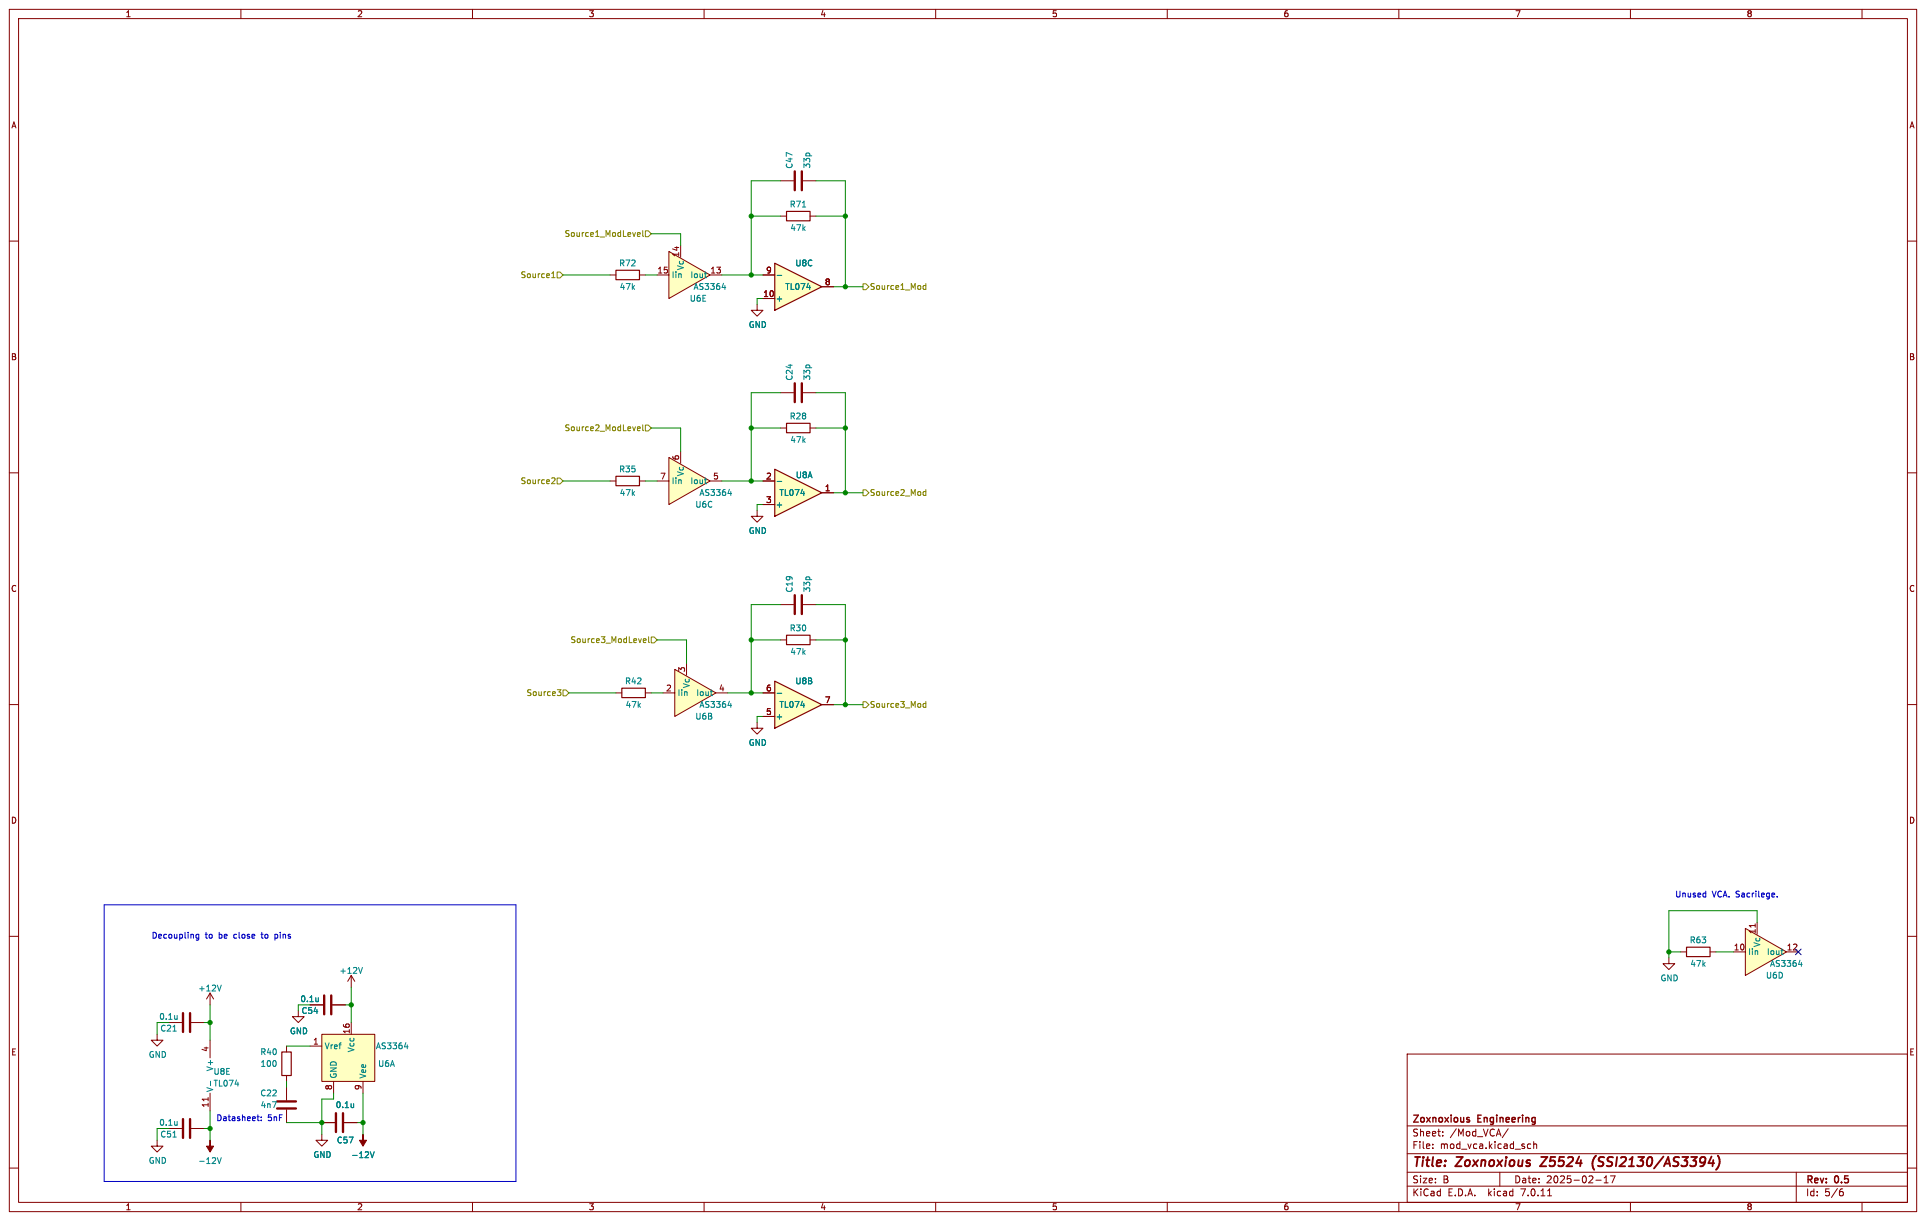
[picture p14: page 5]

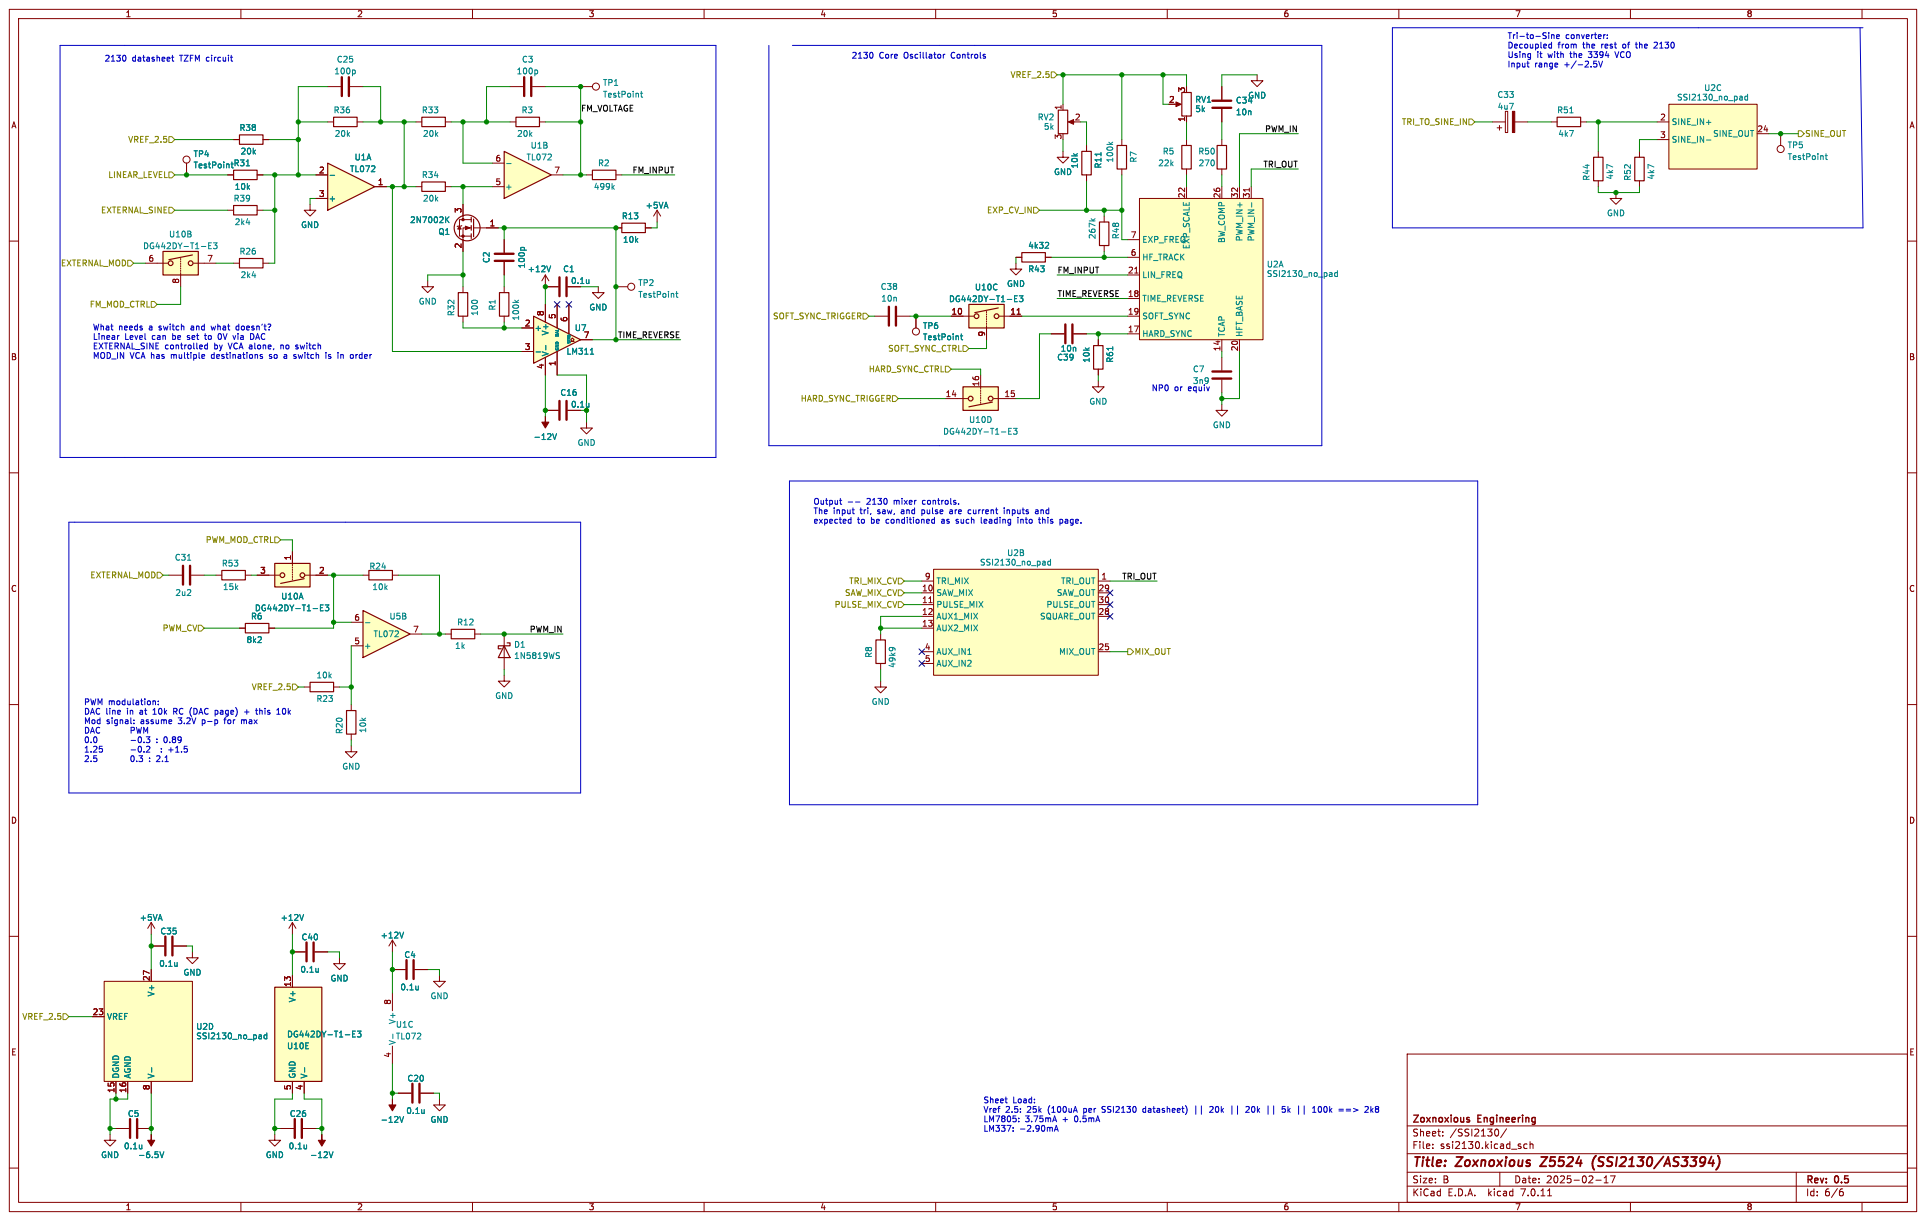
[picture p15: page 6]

Input range +/-2.5V NP0 or equiv

What needs a switch and what doesn't?
Linear Level can be set to 0V via DAC

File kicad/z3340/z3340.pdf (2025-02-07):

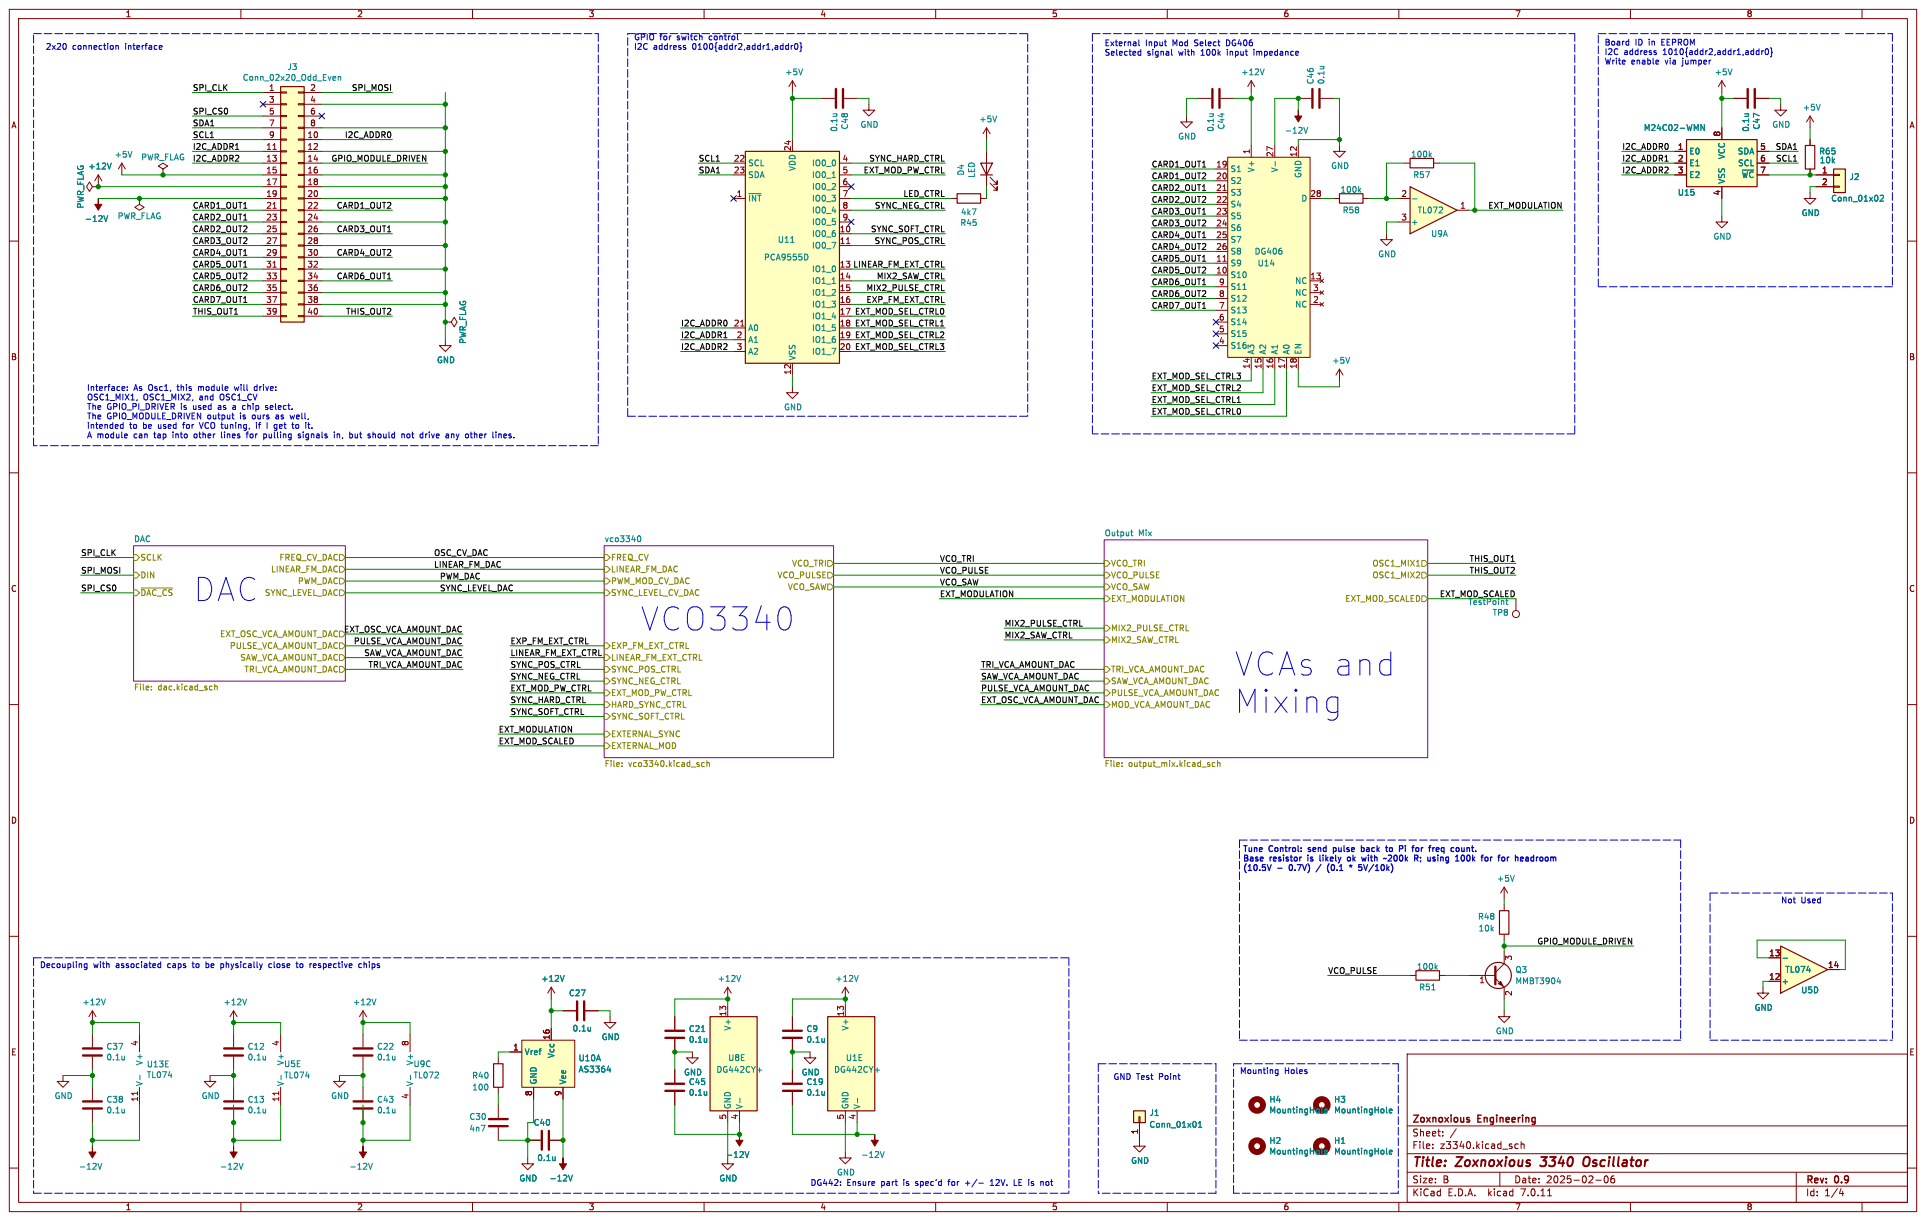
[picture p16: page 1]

Board ID in EEPROM
I2C address 1010{addr2,addr1,addr0} Write enable via jumper

1 S10 10 S9 11 GND 12 NC 13 A3 14 A2 15 A1 16 A0 17 EN 18 S1 19 NC 2 S2 20 S3 21 S4 22 S5 23 S6 24 S7 25 S8 26 V- 27 D

The GPIO_PI_DRIVER is used as a chip select. The GPIO_MODULE_DRIVEN output is ours as well,

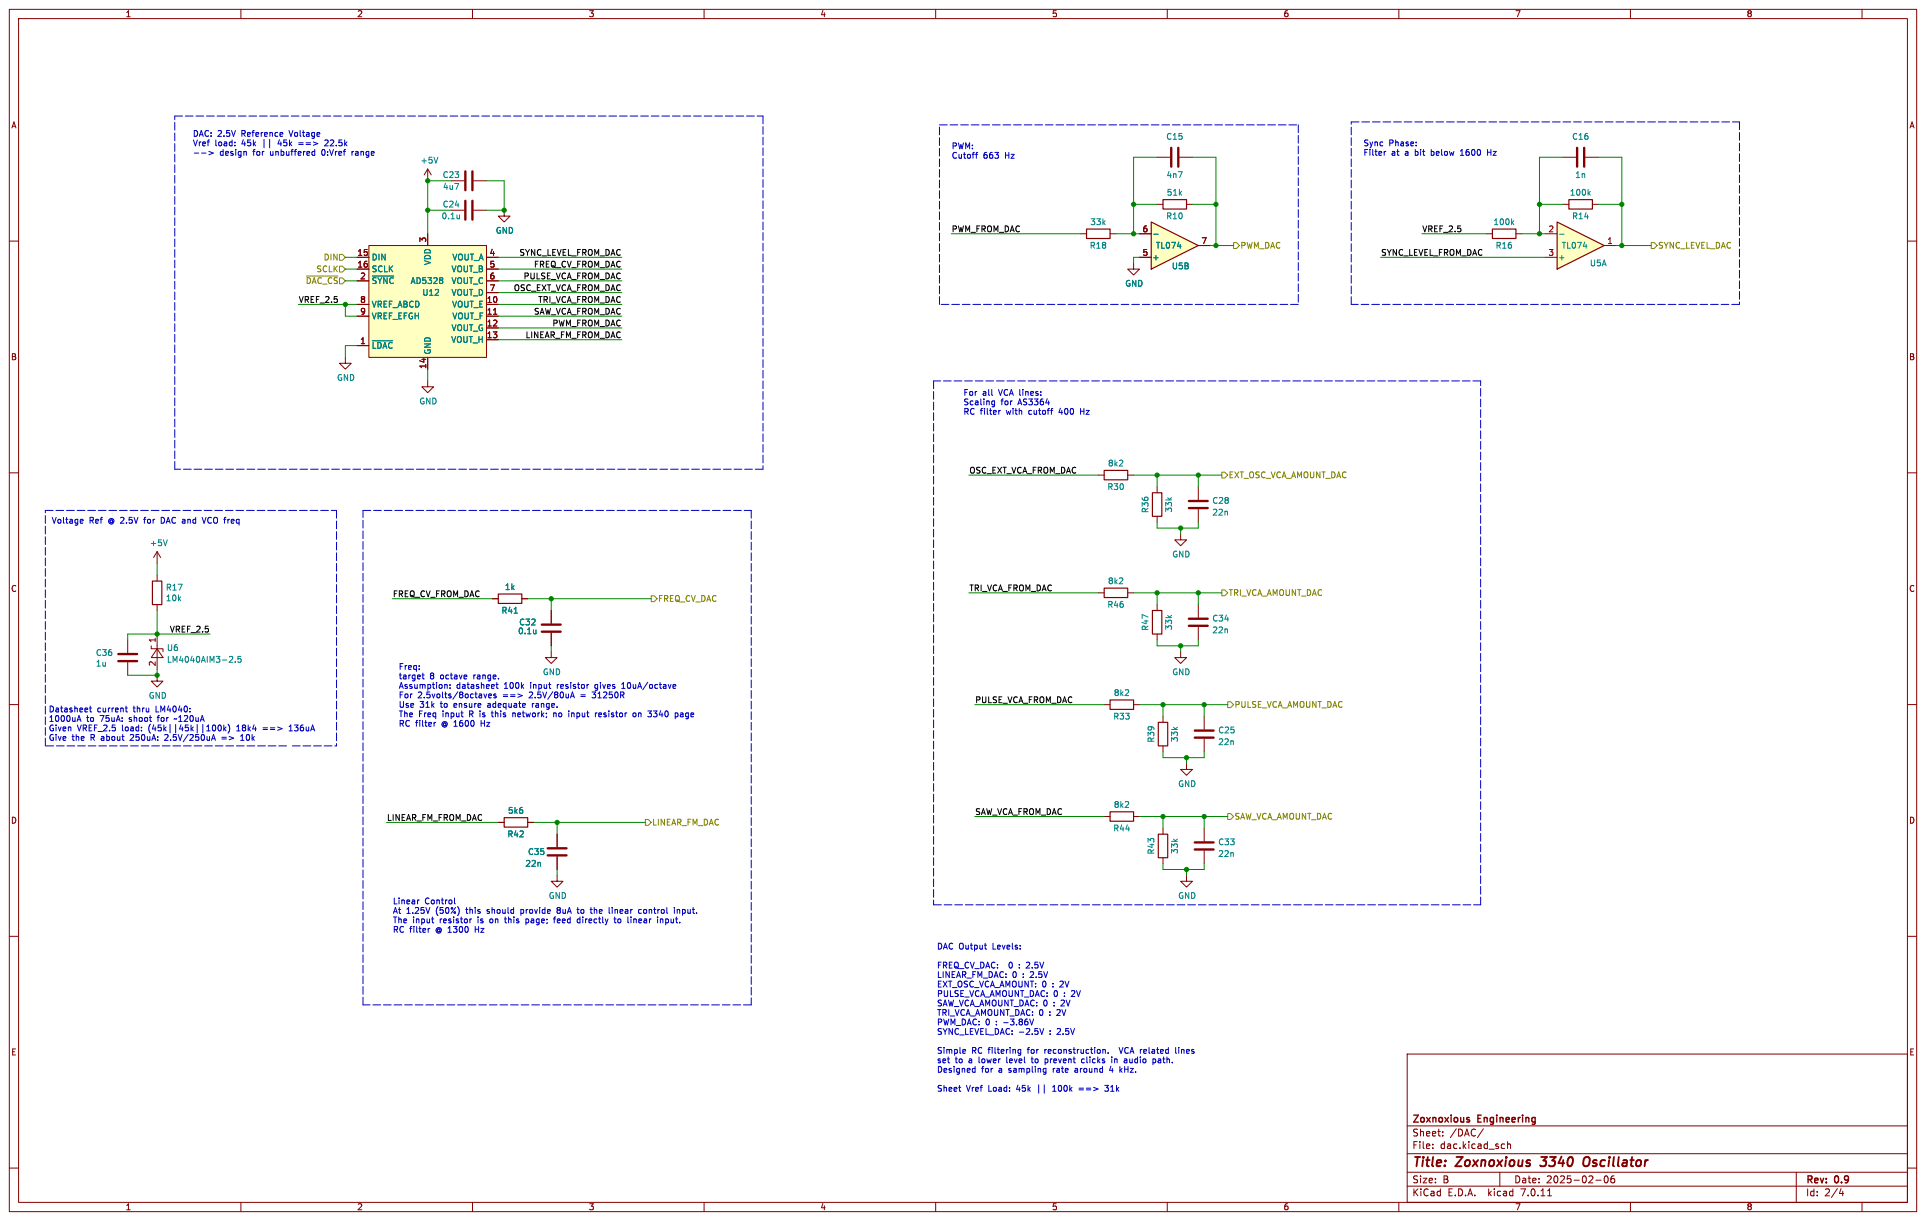
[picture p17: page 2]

PWM: Cutoff 663 Hz Voltage Ref @ 2.5V for DAC and VCO freq

set to a lower level to prevent clicks in audio path.


Linear FM
Input set to 8uA at DAC sheet output w/ DAC at 1.25V

Voltage Ref @ 2.5V for DAC and VCO freq


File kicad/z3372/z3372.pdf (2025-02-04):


Board ID in EEPROM
I2C address 1010{addr2,addr1,addr0} Write enable via jumper

4 SDA 5 SCL 6 ~{WC}7 VCC

1 S7 10 S6 11 S5 12 VDD 13 GND 14 A2 15 A1 16 EN 2 VSS


Pan VCA: 340 Hz cutoff VCA4: 360 Hz filter

Control Voltage level outputs from sheet: VCF CV: 0 : 5V

Sig1 VCA CV: 0 : 5V
Sig2 VCA CV: 0 : 5V
VCA4: 0 : -5V (note negative) VCA Mod Level CV: 0 : 1.9V


Resonance modulation:
invert with gain of 1.0

Input to 3372 should be no more

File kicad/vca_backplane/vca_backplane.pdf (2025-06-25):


4 SDA 5 SCL 6 ~{WC}7 VCC

Id: 1/10 Title: Zoxnoxious Backplane and VCA


Id: 2/10 Title: Zoxnoxious Backplane and VCA


Id: 3/10 Title: Zoxnoxious Backplane and VCA


Id: 4/10 Title: Zoxnoxious Backplane and VCA


1 ~{CS} 2 SCK 3 SDI 4 ~{LDAC} 5 VB 6 Vss 7 VA 8 U3 MCP4822 +12V GND

1 ~{CS} 2 SCK 3 SDI 4 ~{LDAC} 5 VB 6 Vss 7 VA 8 RV1

Id: 5/10 Title: Zoxnoxious Backplane and VCA


Id: 6/10 Title: Zoxnoxious Backplane and VCA


Id: 7/10 Title: Zoxnoxious Backplane and VCA


Id: 8/10 Title: Zoxnoxious Backplane and VCA


Id: 9/10 Title: Zoxnoxious Backplane and VCA


Id: 10/10 Title: Zoxnoxious Backplane and VCA

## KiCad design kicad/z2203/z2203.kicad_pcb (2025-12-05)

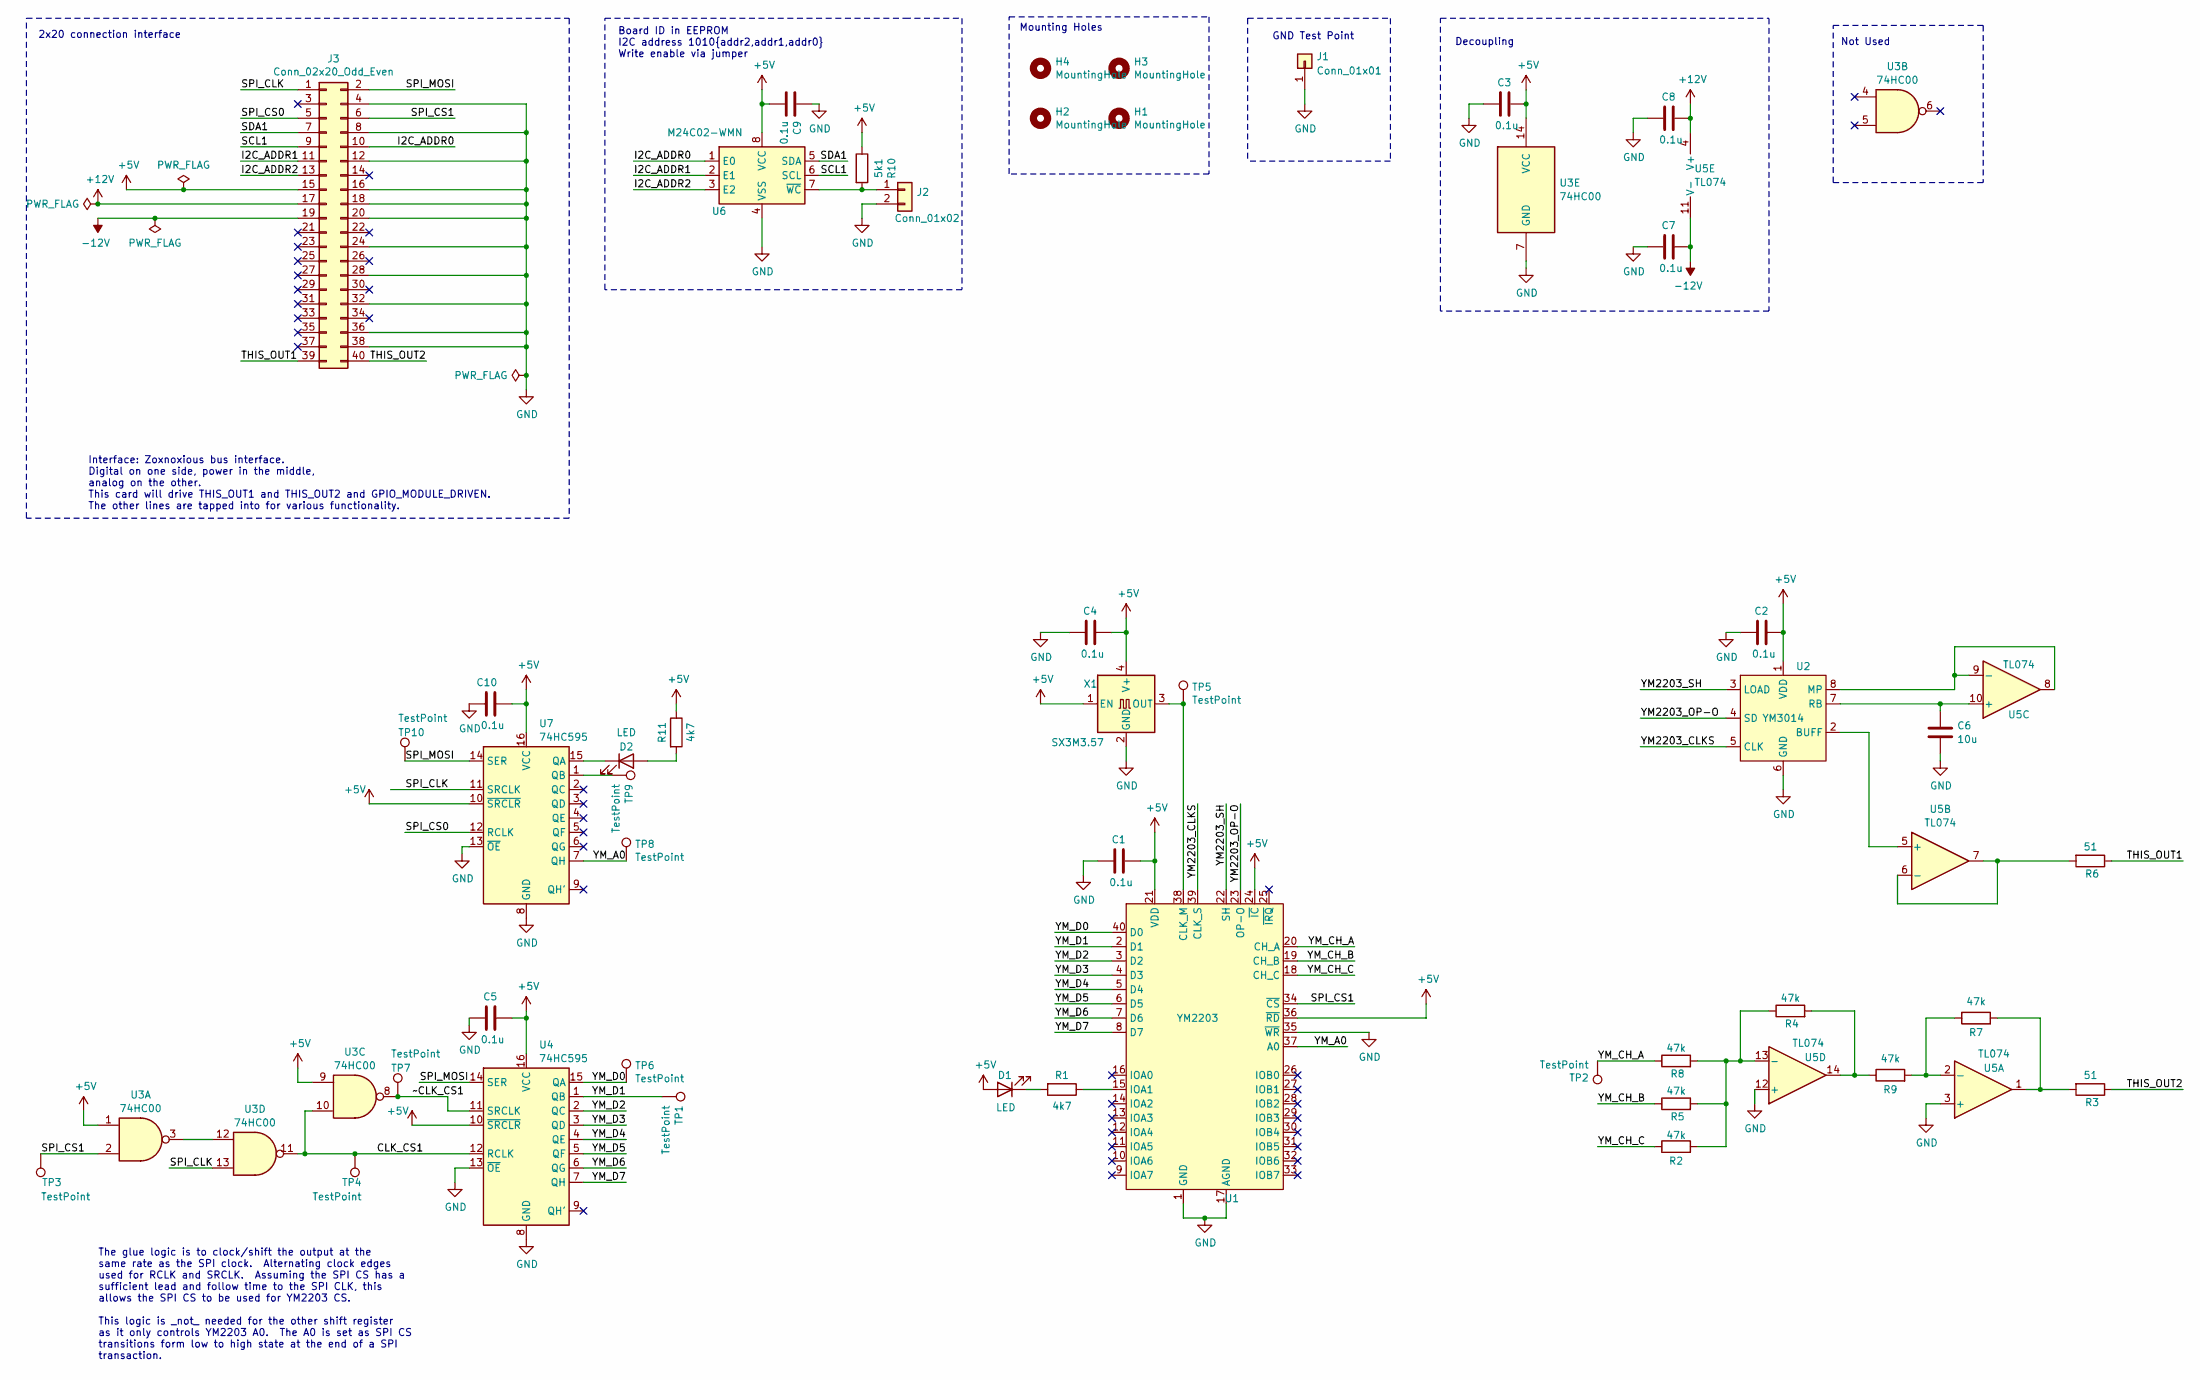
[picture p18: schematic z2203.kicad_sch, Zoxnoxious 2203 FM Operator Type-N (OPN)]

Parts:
C1, C2, C3, C4, C5, C7, C8, C9, C10: 0.1u; C_0603_1608Metric; LCSC C14663
C6: 10u; C_0805_2012Metric; LCSC C15850
D1, D2: LED; LED_0603_1608Metric; LCSC C2286
H1, H2, H3, H4: MountingHole; MountingHole_3.2mm_M3
J1: Conn_01x01; PinHeader_1x01_P2.54mm_Vertical
J2: Conn_01x02; PinHeader_1x02_P2.54mm_Vertical
J3: Conn_02x20_Odd_Even; PinHeader_2x20_P2.54mm_Horizontal
R1, R11: 4k7; R_0603_1608Metric; LCSC C23162
R2, R4, R5, R7, R8, R9: 47k; R_0603_1608Metric; LCSC C25819
R3, R6: 51; R_0603_1608Metric; LCSC C23197
R10: 5k1; R_0603_1608Metric; LCSC C23186
TP1, TP2, TP3, TP4, TP5, TP6, TP7, TP8, TP9, TP10: TestPoint; TestPoint_Pad_2.0x2.0mm; Digikey 952-2664-2-ND
U1: YM2203; DIP-40_W15.24mm
U2: YM3014; DIP-8_W7.62mm
U3: 74HC00; SOIC-14_3.9x8.7mm_P1.27mm; LCSC C10090
U4, U7: 74HC595; TSSOP-16_4.4x5mm_P0.65mm; LCSC C273642
U5: TL074; TSSOP-14_4.4x5mm_P0.65mm; LCSC C96507
U6: M24C02-WMN; SOIC-8_3.9x4.9mm_P1.27mm; LCSC C7562
X1: SX3M3.57; Oscillator_SMD_Abracon_ASE-4Pin_3.2x2.5mm; LCSC C41361373

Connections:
+5V: C1.2, C2.2, C3.2, C4.2, C5.2, C9.2, C10.2, D1.2 (A), J3.15, R10.1, R11.1, U1.21 (VDD), U1.24 (~IC), U1.36 (~RD), U2.1 (VDD), U3.1, U3.9, U3.14 (VCC), U4.10 (~SRCLR), U4.16 (VCC), U6.8 (VCC), U7.10 (~SRCLR), U7.16 (VCC), X1.1 (EN), X1.4 (V+)
+12V: C8.2, J3.17, U5.4 (V+)
-12V: C7.2, J3.19, U5.11 (V-)
/CLK_CS1: TP4.1, U3.10, U3.11, U4.12 (RCLK)
/I2C_ADDR0: J3.10, U6.1 (E0)
/I2C_ADDR1: J3.11, U6.2 (E1)
/I2C_ADDR2: J3.13, U6.3 (E2)
/SCL1: J3.9, U6.6 (SCL)
/SDA1: J3.7, U6.5 (SDA)
/SPI_CLK: J3.1, U3.13, U7.11 (SRCLK)
/SPI_CS0: J3.5, U7.12 (RCLK)
/SPI_CS1: J3.6, TP3.1, U1.34 (~CS), U3.2
/SPI_MOSI: J3.2, TP10.1, U4.14 (SER), U7.14 (SER)
/THIS_OUT1: J3.39, R6.1
/THIS_OUT2: J3.40, R3.1
/YM2203_CLKS: U1.39 (CLK_S), U2.5 (CLK)
/YM2203_OP-O: U1.23 (OP-O), U2.4 (SD)
/YM2203_SH: U1.22 (SH), U2.3 (LOAD)
/YM_A0: TP8.1, U1.37 (A0), U7.7 (QH)
/YM_CH_A: R8.1, TP2.1, U1.20 (CH_A)
/YM_CH_B: R5.1, U1.19 (CH_B)
/YM_CH_C: R2.1, U1.18 (CH_C)
/YM_D0: TP6.1, U1.40 (D0), U4.15 (QA)
/YM_D1: TP1.1, U1.2 (D1), U4.1 (QB)
/YM_D2: U1.3 (D2), U4.2 (QC)
/YM_D3: U1.4 (D3), U4.3 (QD)
/YM_D4: U1.5 (D4), U4.4 (QE)
/YM_D5: U1.6 (D5), U4.5 (QF)
/YM_D6: U1.7 (D6), U4.6 (QG)
/YM_D7: U1.8 (D7), U4.7 (QH)
/~CLK_CS1: TP7.1, U3.8, U4.11 (SRCLK)
GND: C1.1, C2.1, C3.1, C4.1, C5.1, C6.2, C7.1, C8.1, C9.1, C10.1, J1.1, J2.2, J3.4, J3.8, J3.12, J3.16, J3.18, J3.20, J3.24, J3.28, J3.32, J3.36, J3.38, U1.1 (GND), U1.17 (AGND), U1.35 (~WR), U2.6 (GND), U3.7 (GND), U4.8 (GND), U4.13 (~OE), U5.3 (+), U5.12 (+), U6.4 (VSS), U7.8 (GND), U7.13 (~OE), X1.2 (GND)
unnamed: D1.1 (K), R1.2
unnamed: D2.2 (A), R11.2
unnamed: D2.1 (K), U7.15 (QA)
unnamed: J2.1, R10.2, U6.7 (~WC)
unnamed: R3.2, R7.2, U5.1
unnamed: R4.2, R9.1, U5.14
unnamed: TP5.1, U1.38 (CLK_M), X1.3 (OUT)
unnamed: R1.1, U1.15 (IOA1)
unnamed: U2.2 (BUFF), U5.5 (+)
unnamed: U2.8 (MP), U5.8, U5.9 (-)
unnamed: C6.1, U2.7 (RB), U5.10 (+)
unnamed: U3.3, U3.12
unnamed: R7.1, R9.2, U5.2 (-)
unnamed: R6.2, U5.6 (-), U5.7
unnamed: R2.2, R4.1, R5.2, R8.2, U5.13 (-)
unnamed: TP9.1, U7.1 (QB)

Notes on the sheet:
The glue logic is to clock/shift the output at the same rate as the SPI clock. Alternating clock edges used for RCLK and SRCLK. Assuming the SPI CS has a sufficient lead and follow time to the SPI CLK, this allows the SPI CS to be used for YM2203 CS. This logic is _not_ needed for the other shift r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
2x20 connection interface
Decoupling
Mounting Holes
GND Test Point
Board ID in EEPROM I2C address 1010{addr2,addr1,addr0} Write enable via jumper
Not Used
Interface: Zoxnoxious bus interface. Digital on one side, power in the middle, analog on the other. This card will drive THIS_OUT1 and THIS_OUT2 and GPIO_MODULE_DRIVEN. The other lines are tapped into for various functionality.

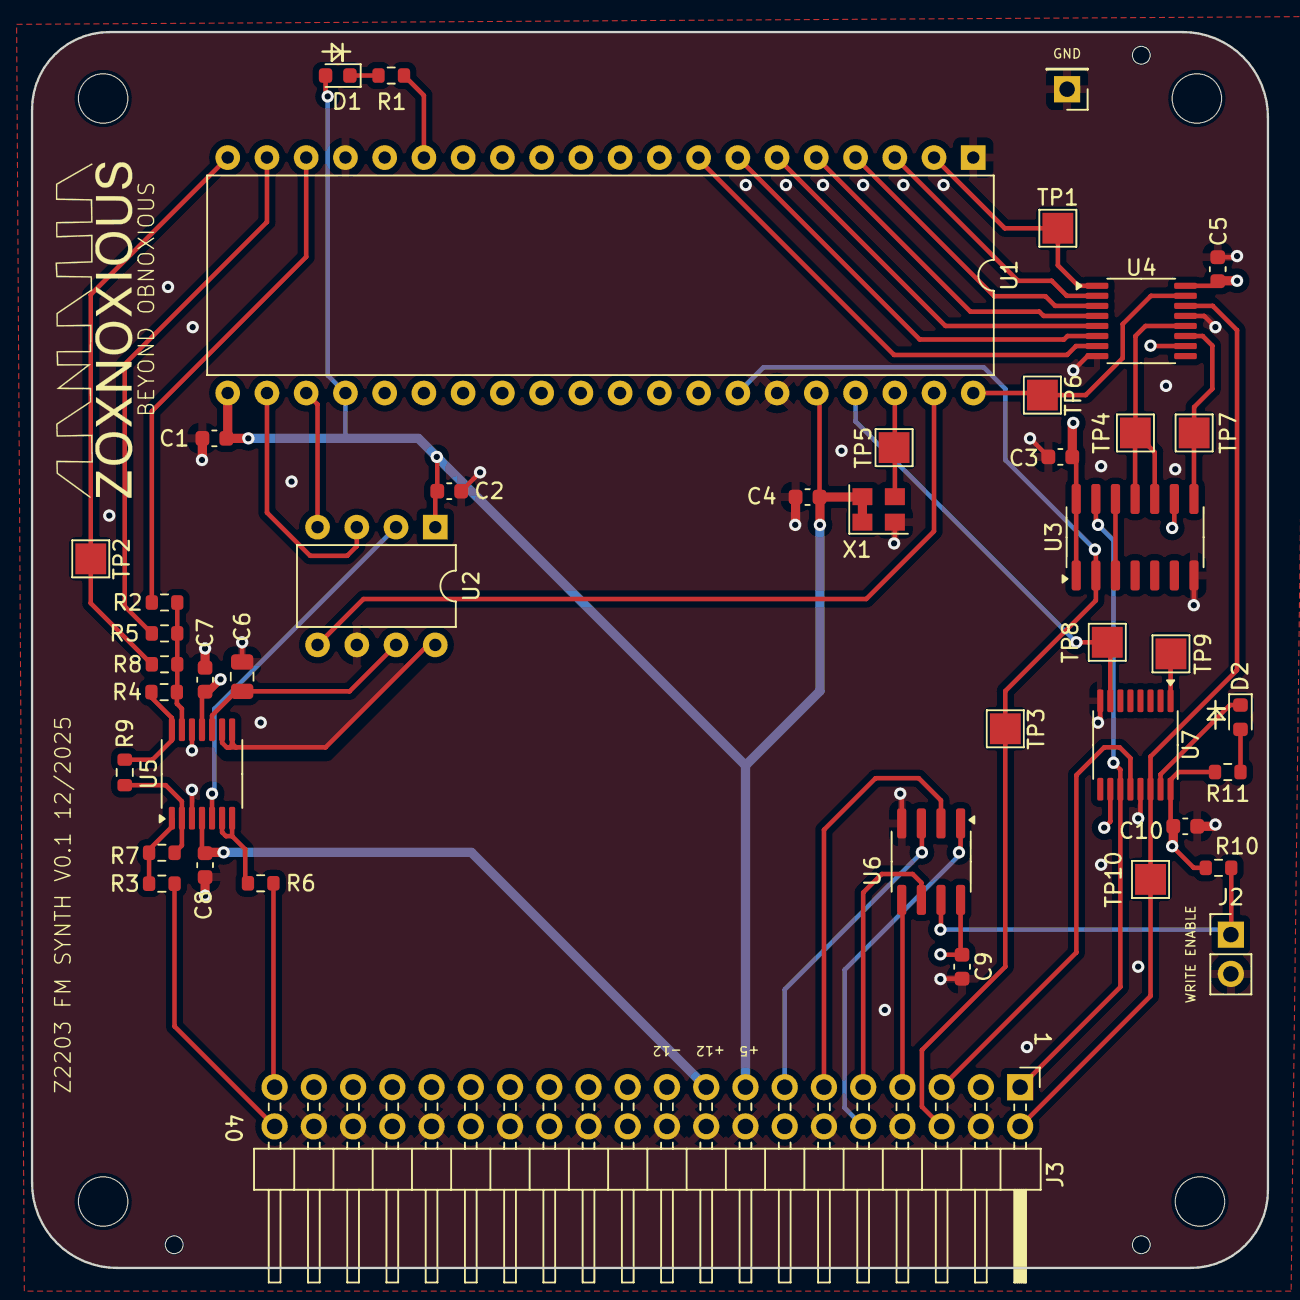
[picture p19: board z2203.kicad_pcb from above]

Board: 4 copper layers, 80.0 x 80.0 mm, 48 parts (0 on the bottom side), 48 nets.

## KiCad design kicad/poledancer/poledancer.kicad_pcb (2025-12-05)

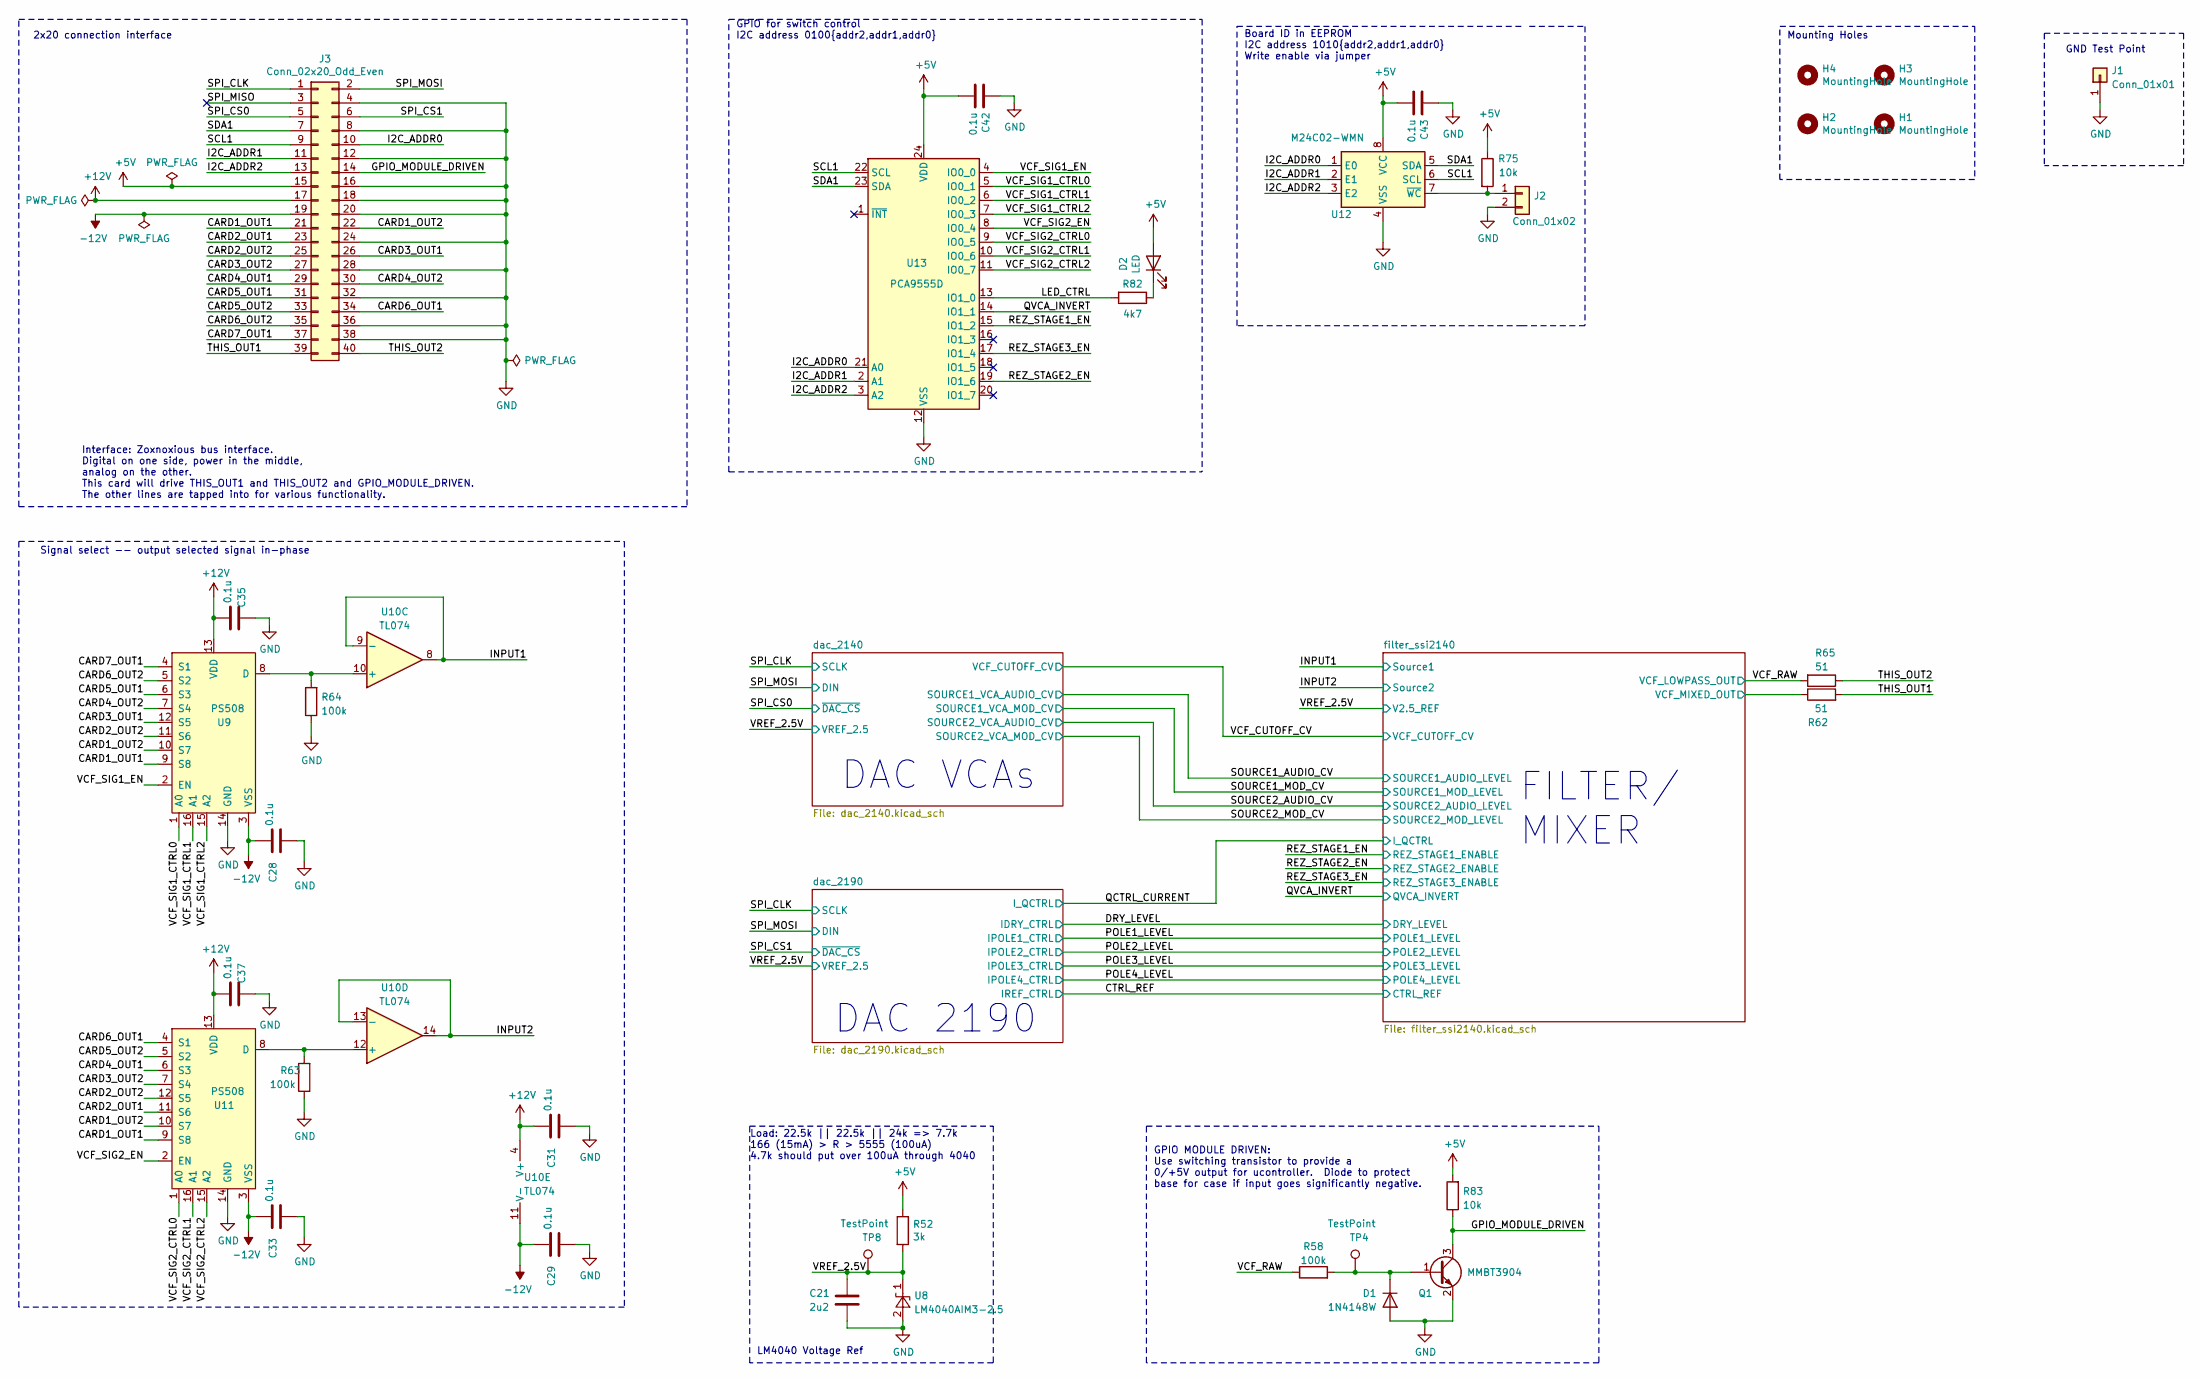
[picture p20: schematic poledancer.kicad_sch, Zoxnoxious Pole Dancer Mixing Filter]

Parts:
C21: 2u2; C_0603_1608Metric; LCSC C23630
C28, C29, C31, C33, C35, C37, C42, C43: 0.1u; C_0603_1608Metric; LCSC C14663
D1: 1N4148W; D_SOD-123; LCSC C81598
D2: LED; LED_0603_1608Metric; LCSC C2286
H1, H2, H3, H4: MountingHole; MountingHole_3.2mm_M3
J1: Conn_01x01; PinHeader_1x01_P2.54mm_Vertical
J2: Conn_01x02; PinHeader_1x02_P2.54mm_Vertical
J3: Conn_02x20_Odd_Even; PinHeader_2x20_P2.54mm_Horizontal
Q1: MMBT3904; SOT-23; LCSC C20526
R52: 3k; R_0603_1608Metric; LCSC C4211
R58, R63, R64: 100k; R_0603_1608Metric; LCSC C25803
R62, R65: 51; R_0603_1608Metric; LCSC C23197
R75, R83: 10k; R_0603_1608Metric; LCSC C25804
R82: 4k7; R_0603_1608Metric; LCSC C23162
TP4, TP8: TestPoint; TestPoint_Pad_2.0x2.0mm
U8: LM4040AIM3-2.5; SOT-23; LCSC C111866
U9, U11: PS508; SOIC-16_3.9x9.9mm_P1.27mm; LCSC C2673104
U10: TL074; TSSOP-14_4.4x5mm_P0.65mm; LCSC C96507
U12: M24C02-WMN; SOIC-8_3.9x4.9mm_P1.27mm; LCSC C7562
U13: PCA9555D; TSSOP-24_4.4x7.8mm_P0.65mm; LCSC C83265

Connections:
+5V: C42.2, C43.2, D2.2 (A), J3.15, R52.1, R75.1, R83.2, U12.8 (VCC), U13.24 (VDD); also elsewhere on the board
+12V: C31.2, C35.2, C37.2, J3.17, U9.13 (VDD), U10.4 (V+), U11.13 (VDD); also elsewhere on the board
-12V: C28.2, C29.2, C33.2, J3.19, U9.3 (VSS), U10.11 (V-), U11.3 (VSS); also elsewhere on the board
/CARD1_OUT1: J3.21, U9.9 (S8), U11.9 (S8)
/CARD1_OUT2: J3.22, U9.10 (S7), U11.10 (S7)
/CARD2_OUT1: J3.23, U11.11 (S6)
/CARD2_OUT2: J3.25, U9.11 (S6), U11.12 (S5)
/CARD3_OUT1: J3.26, U9.12 (S5)
/CARD3_OUT2: J3.27, U11.7 (S4)
/CARD4_OUT1: J3.29, U11.6 (S3)
/CARD4_OUT2: J3.30, U9.7 (S4)
/CARD5_OUT1: J3.31, U9.6 (S3)
/CARD5_OUT2: J3.33, U11.5 (S2)
/CARD6_OUT1: J3.34, U11.4 (S1)
/CARD6_OUT2: J3.35, U9.5 (S2)
/CARD7_OUT1: J3.37, U9.4 (S1)
/GPIO_MODULE_DRIVEN: J3.14, Q1.3 (C), R83.1
/I2C_ADDR0: J3.10, U12.1 (E0), U13.21 (A0)
/I2C_ADDR1: J3.11, U12.2 (E1), U13.2 (A1)
/I2C_ADDR2: J3.13, U12.3 (E2), U13.3 (A2)
/INPUT1: U10.8, U10.9 (-); also elsewhere on the board
/INPUT2: U10.13 (-), U10.14; also elsewhere on the board
/LED_CTRL: R82.2, U13.13 (IO1_0)
/QVCA_INVERT: U13.14 (IO1_1); also elsewhere on the board
/REZ_STAGE1_EN: U13.15 (IO1_2); also elsewhere on the board
/REZ_STAGE2_EN: U13.19 (IO1_6); also elsewhere on the board
/REZ_STAGE3_EN: U13.17 (IO1_4); also elsewhere on the board
/SCL1: J3.9, U12.6 (SCL), U13.22 (SCL)
/SDA1: J3.7, U12.5 (SDA), U13.23 (SDA)
/SPI_CLK: J3.1; also elsewhere on the board
/SPI_CS0: J3.5; also elsewhere on the board
/SPI_CS1: J3.6; also elsewhere on the board
/SPI_MISO: J3.3
/SPI_MOSI: J3.2; also elsewhere on the board
/THIS_OUT1: J3.39, R62.2
/THIS_OUT2: J3.40, R65.1
/VCF_RAW: R58.1, R65.2; also elsewhere on the board
/VCF_SIG1_CTRL0: U9.1 (A0), U13.5 (IO0_1)
/VCF_SIG1_CTRL1: U9.16 (A1), U13.6 (IO0_2)
/VCF_SIG1_CTRL2: U9.15 (A2), U13.7 (IO0_3)
/VCF_SIG1_EN: U9.2 (EN), U13.4 (IO0_0)
/VCF_SIG2_CTRL0: U11.1 (A0), U13.9 (IO0_5)
/VCF_SIG2_CTRL1: U11.16 (A1), U13.10 (IO0_6)
/VCF_SIG2_CTRL2: U11.15 (A2), U13.11 (IO0_7)
/VCF_SIG2_EN: U11.2 (EN), U13.8 (IO0_4)
/VREF_2.5V: C21.1, R52.2, TP8.1, U8.1 (K); also elsewhere on the board
/filter_ssi2140/VCF_MIXED_OUT: R62.1; also elsewhere on the board
GND: C21.2, C28.1, C29.1, C31.1, C33.1, C35.1, C37.1, C42.1, C43.1, D1.2 (A), J1.1, J2.2, J3.4, J3.8, J3.12, J3.16, J3.18, J3.20, J3.24, J3.28, J3.32, J3.36, J3.38, Q1.2 (E), R63.1, R64.1, U8.2 (A), U9.14 (GND), U11.14 (GND), U12.4 (VSS), U13.12 (VSS); also elsewhere on the board
unnamed: D1.1 (K), Q1.1 (B), R58.2, TP4.1
unnamed: D2.1 (K), R82.1
unnamed: J2.1, R75.2, U12.7 (~WC)
unnamed: R64.2, U9.8 (D), U10.10 (+)
unnamed: R63.2, U10.12 (+), U11.8 (D)

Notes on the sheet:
Load: 22.5k || 22.5k || 24k => 7.7k 166 (15mA) > R > 5555 (100uA) 4.7k should put over 100uA through 4040
Signal select -- output selected signal in-phase
GPIO MODULE DRIVEN: Use switching transistor to provide a 0/+5V output for ucontroller. Diode to protect base for case if input goes significantly negative.
2x20 connection interface
FILTER/ MIXER
GPIO for switch control I2C address 0100{addr2,addr1,addr0}
Mounting Holes
DAC 2190
GND Test Point
Board ID in EEPROM I2C address 1010{addr2,addr1,addr0} Write enable via jumper
Interface: Zoxnoxious bus interface. Digital on one side, power in the middle, analog on the other. This card will drive THIS_OUT1 and THIS_OUT2 and GPIO_MODULE_DRIVEN. The other lines are tapped into for various functionality.
LM4040 Voltage Ref
DAC VCAs

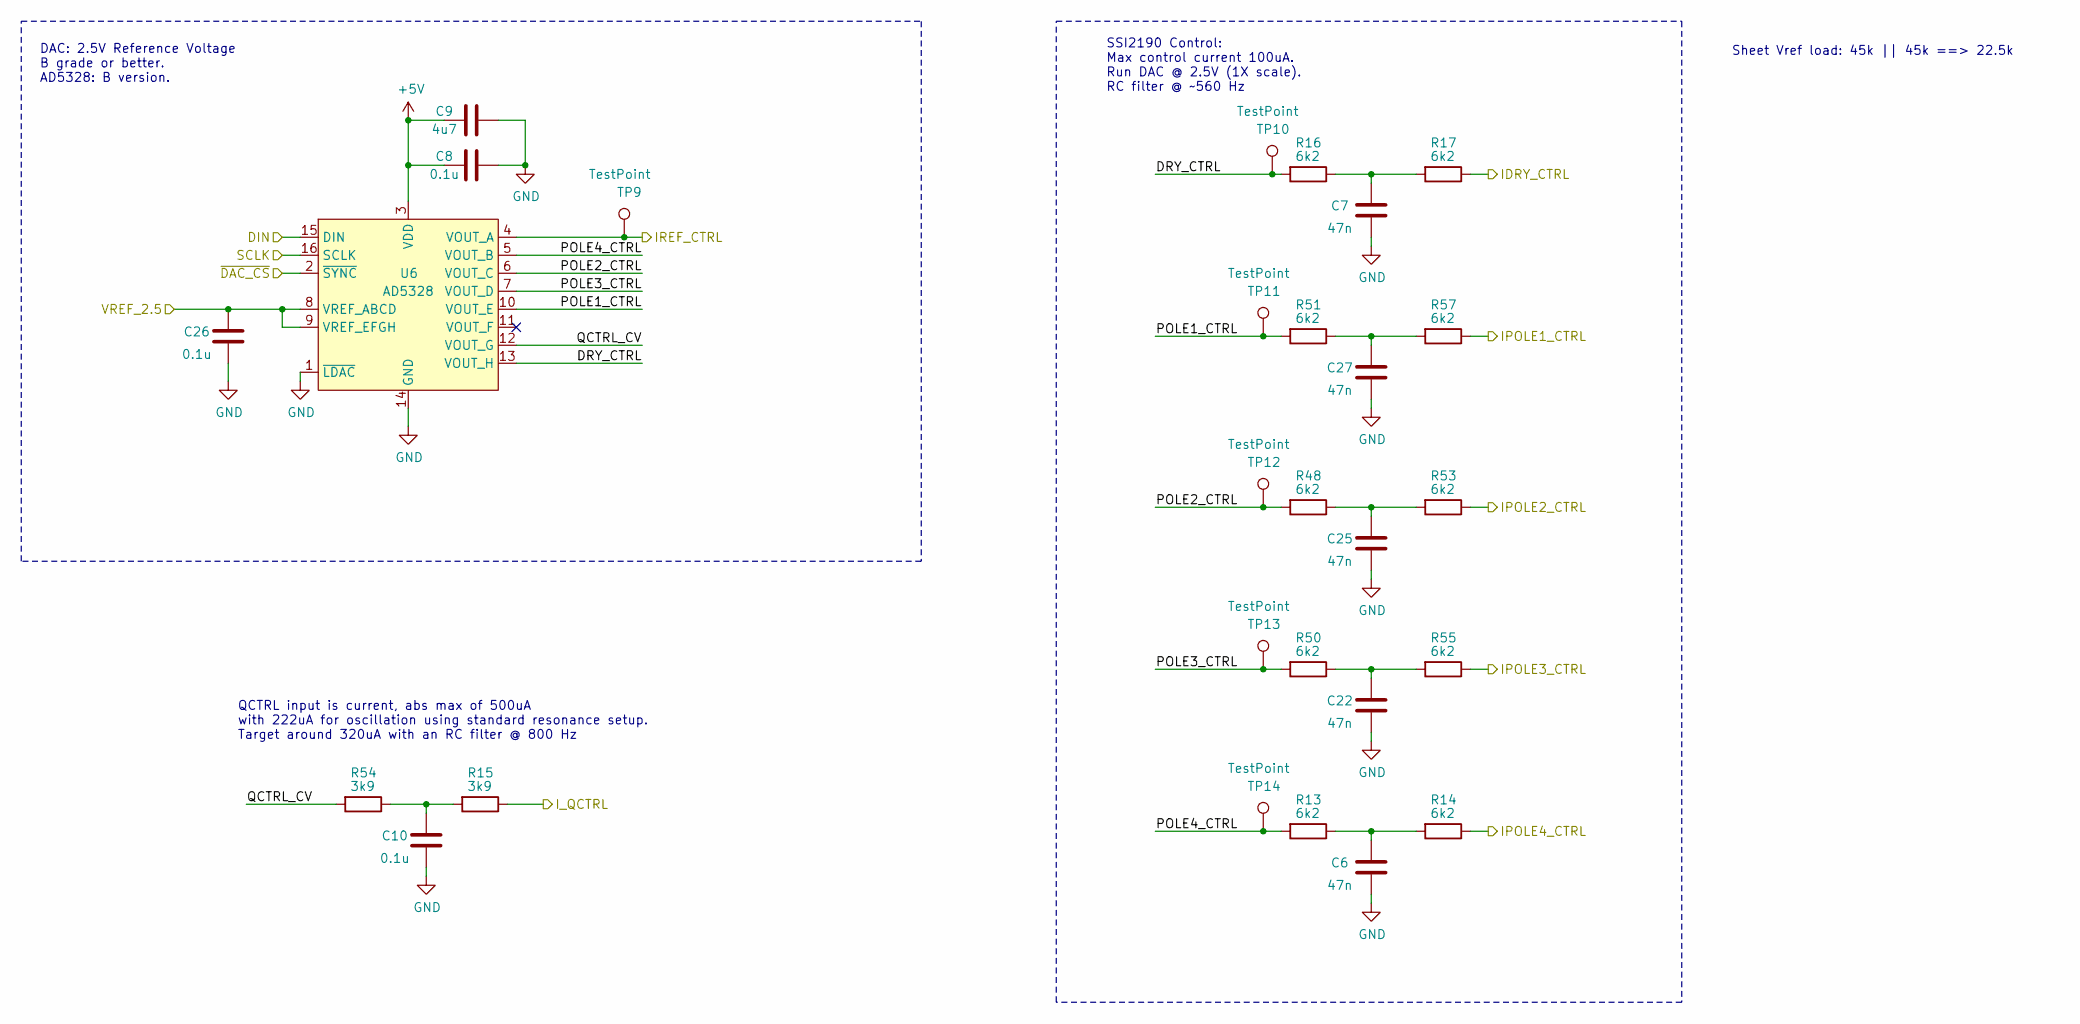
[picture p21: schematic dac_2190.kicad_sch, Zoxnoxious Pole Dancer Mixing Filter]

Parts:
C6, C7, C22, C25, C27: 47n; C_0603_1608Metric; LCSC C1622
C8, C10, C26: 0.1u; C_0603_1608Metric; LCSC C14663
C9: 4u7; C_0603_1608Metric; LCSC C19666
R13, R14, R16, R17, R48, R50, R51, R53, R55, R57: 6k2; R_0603_1608Metric; LCSC C4260
R15, R54: 3k9; R_0603_1608Metric; LCSC C23018
TP9, TP10, TP11, TP12, TP13, TP14: TestPoint; TestPoint_Pad_2.0x2.0mm
U6: AD5328; TSSOP-16_4.4x5mm_P0.65mm; LCSC C29162

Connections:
+5V: C8.1, C9.1, U6.3 (VDD); also elsewhere on the board
/CTRL_REF: TP9.1, U6.4 (VOUT_A); also elsewhere on the board
/DRY_LEVEL: R17.1; also elsewhere on the board
/POLE1_LEVEL: R57.1; also elsewhere on the board
/POLE2_LEVEL: R53.1; also elsewhere on the board
/POLE3_LEVEL: R55.1; also elsewhere on the board
/POLE4_LEVEL: R14.1; also elsewhere on the board
/QCTRL_CURRENT: R15.1; also elsewhere on the board
/SPI_CLK: U6.16 (SCLK); also elsewhere on the board
/SPI_CS1: U6.2 (~SYNC); also elsewhere on the board
/SPI_MOSI: U6.15 (DIN); also elsewhere on the board
/VREF_2.5V: C26.1, U6.8 (VREF_ABCD), U6.9 (VREF_EFGH); also elsewhere on the board
/dac_2190/DRY_CTRL: R16.2, TP10.1, U6.13 (VOUT_H)
/dac_2190/POLE1_CTRL: R51.2, TP11.1, U6.10 (VOUT_E)
/dac_2190/POLE2_CTRL: R48.2, TP12.1, U6.6 (VOUT_C)
/dac_2190/POLE3_CTRL: R50.2, TP13.1, U6.7 (VOUT_D)
/dac_2190/POLE4_CTRL: R13.2, TP14.1, U6.5 (VOUT_B)
/dac_2190/QCTRL_CV: R54.2, U6.12 (VOUT_G)
GND: C6.2, C7.2, C8.2, C9.2, C10.2, C22.2, C25.2, C26.2, C27.2, U6.1 (~LDAC), U6.14 (GND); also elsewhere on the board
unnamed: C6.1, R13.1, R14.2
unnamed: C7.1, R16.1, R17.2
unnamed: C10.1, R15.2, R54.1
unnamed: C22.1, R50.1, R55.2
unnamed: C25.1, R48.1, R53.2
unnamed: C27.1, R51.1, R57.2

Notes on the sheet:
QCTRL input is current, abs max of 500uA with 222uA for oscillation using standard resonance setup. Target around 320uA with an RC filter @ 800 Hz
SSI2190 Control: Max control current 100uA. Run DAC @ 2.5V (1X scale). RC filter @ ~560 Hz
Sheet Vref load: 45k || 45k ==> 22.5k
DAC: 2.5V Reference Voltage B grade or better. AD5328: B version.

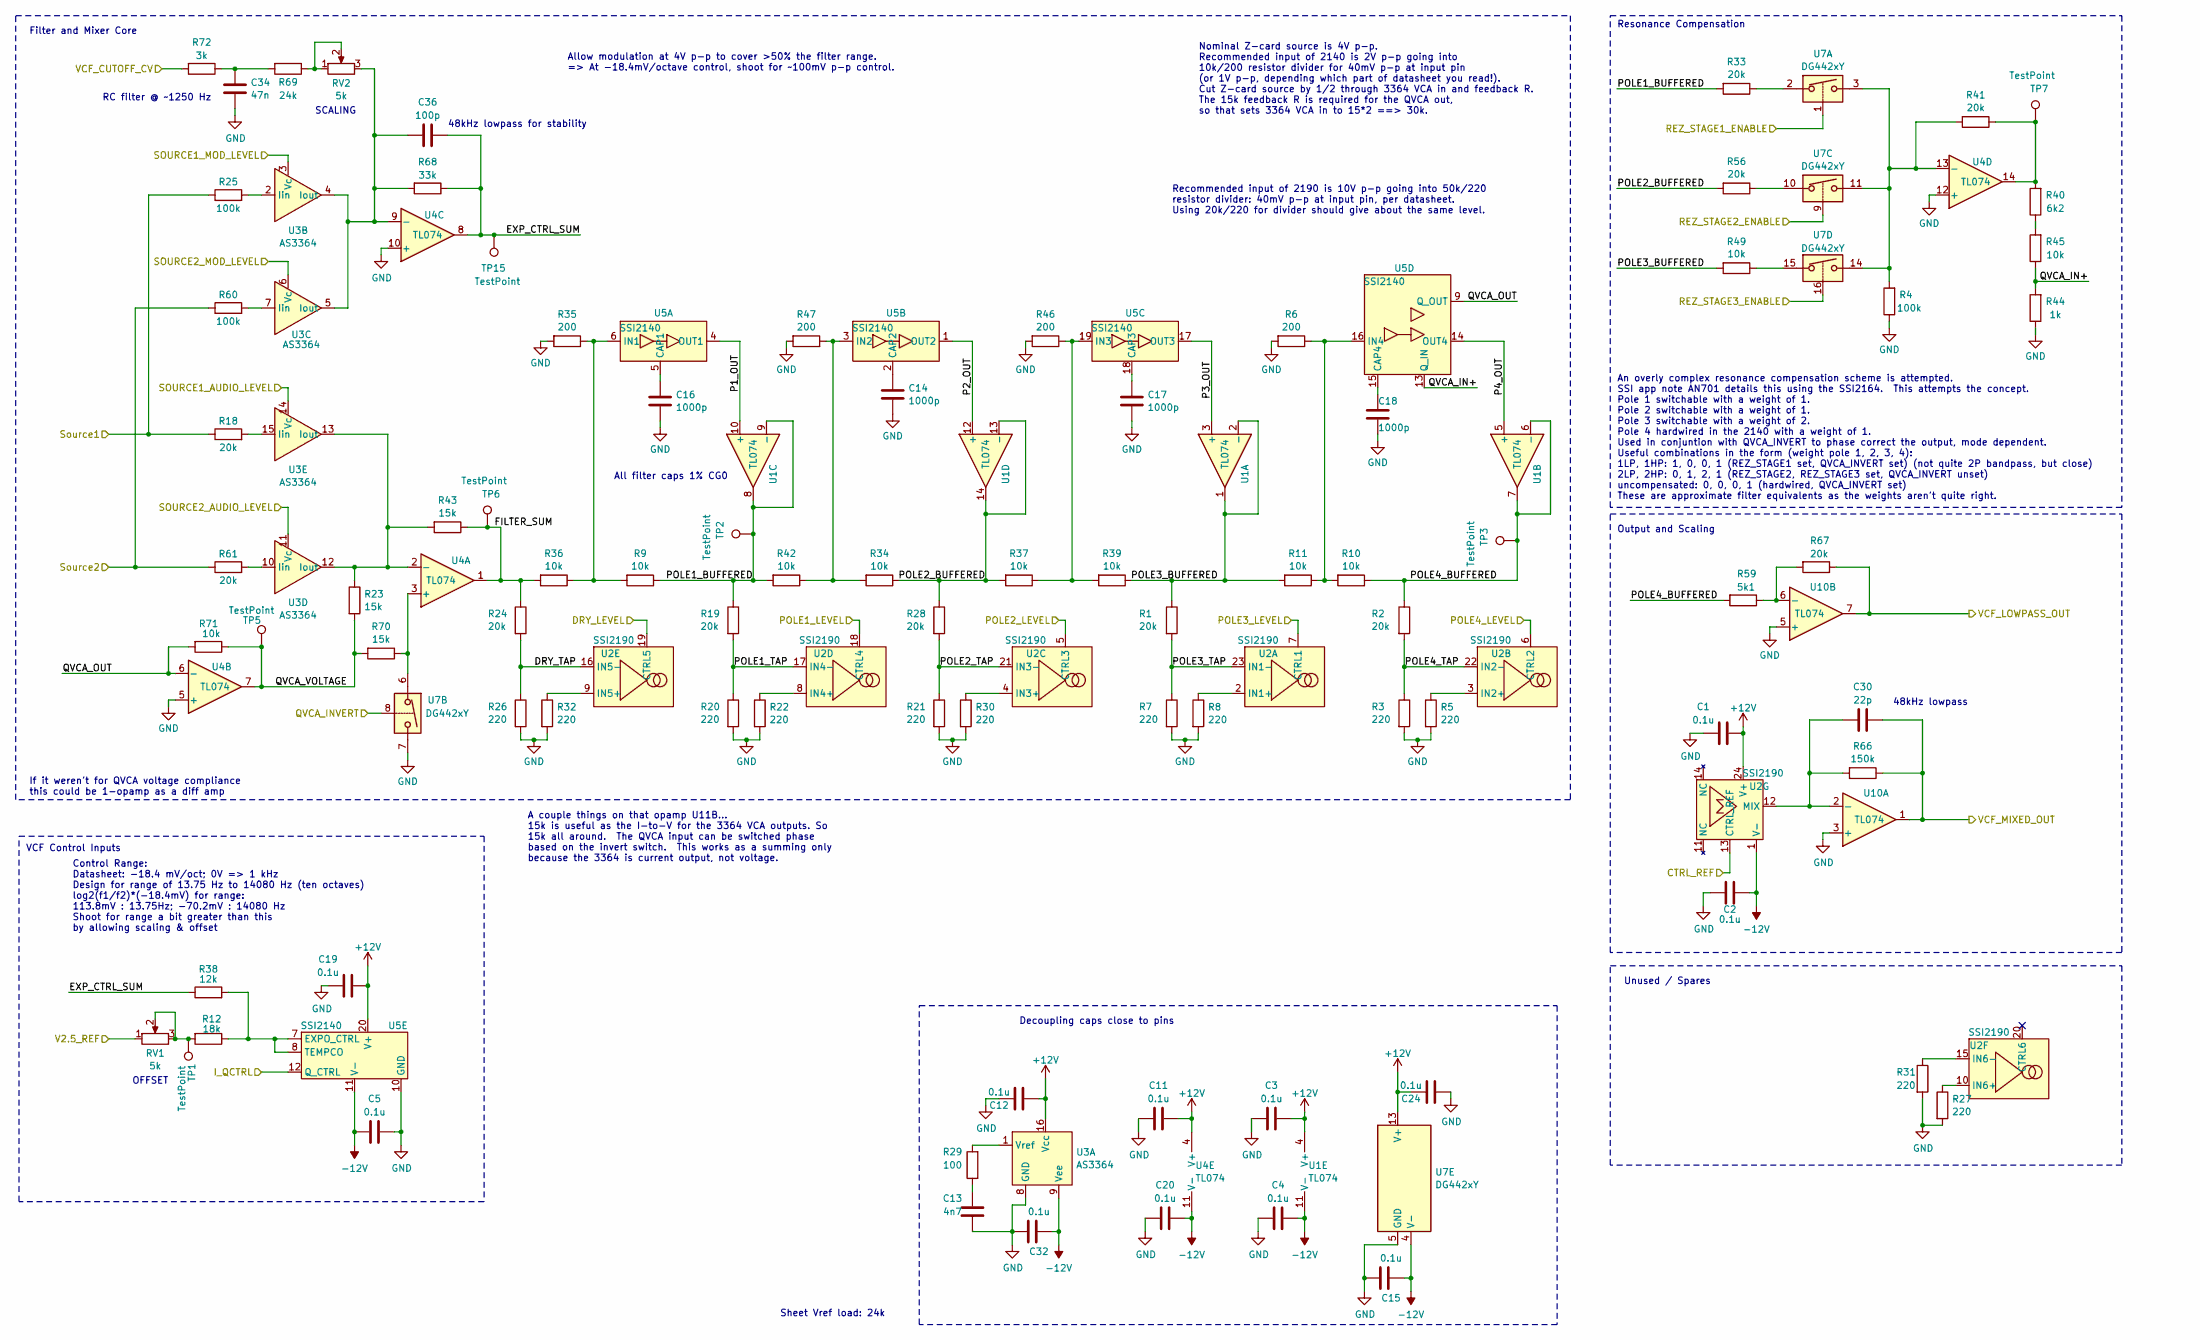
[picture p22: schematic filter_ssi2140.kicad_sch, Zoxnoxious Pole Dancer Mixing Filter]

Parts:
C1, C2, C3, C4, C5, C11, C12, C15, C19, C20, C24, C32: 0.1u; C_0603_1608Metric; LCSC C14663
C13: 4n7; C_0603_1608Metric; LCSC C53987
C14, C16, C17, C18: 1000p; C_0805_2012Metric; Digikey 478-KGM21BCG1H102FTCT-ND
C30: 22p; C_0603_1608Metric; LCSC C1653
C34: 47n; C_0603_1608Metric; LCSC C1622
C36: 100p; C_0603_1608Metric; LCSC C14858
R1, R2, R18, R19, R24, R28, R33, R41, R56, R61, R67: 20k; R_0603_1608Metric; LCSC C4184
R3, R5, R7, R8, R20, R21, R22, R26, R27, R30, R31, R32: 220; R_0603_1608Metric; LCSC C22962
R4, R25, R60: 100k; R_0603_1608Metric; LCSC C25803
R6, R35, R46, R47: 200; R_0603_1608Metric; LCSC C8218
R9, R10, R11, R34, R36, R37, R39, R42, R45, R49, R71: 10k; R_0603_1608Metric; LCSC C25804
R12: 18k; R_0603_1608Metric; LCSC C25810
R23, R43, R70: 15k; R_0603_1608Metric; LCSC C22809
R29: 100; R_0603_1608Metric; LCSC C22775
R38: 12k; R_0603_1608Metric; LCSC C22790
R40: 6k2; R_0603_1608Metric; LCSC C4260
R44: 1k; R_0603_1608Metric; LCSC C21190
R59: 5k1; R_0603_1608Metric; LCSC C23186
R66: 150k; R_0603_1608Metric; LCSC C22807
R68: 33k; R_0603_1608Metric; LCSC C4216
R69: 24k; R_0603_1608Metric; LCSC C23352
R72: 3k; R_0603_1608Metric; LCSC C4211
RV1, RV2: 5k; Potentiometer_Bourns_3296W_Vertical
TP1, TP2, TP3, TP5, TP6, TP7, TP15: TestPoint; TestPoint_Pad_2.0x2.0mm
U1, U4, U10: TL074; TSSOP-14_4.4x5mm_P0.65mm; LCSC C96507
U2: SSI2190; SSOP-24_3.9x8.7mm_P0.635mm
U3: AS3364; SOIC-16_3.9x9.9mm_P1.27mm
U5: SSI2140; SSOP-20_4.4x6.5mm_P0.65mm
U7: DG442xY; SOIC-16_3.9x9.9mm_P1.27mm; LCSC C2673321

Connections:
+12V: C1.1, C3.1, C11.1, C12.1, C19.1, C24.2, U1.4 (V+), U2.24 (V+), U3.16 (Vcc), U4.4 (V+), U5.20 (V+), U7.13 (V+); also elsewhere on the board
-12V: C2.1, C4.1, C5.2, C15.1, C20.1, C32.1, U1.11 (V-), U2.1 (V-), U3.9 (Vee), U4.11 (V-), U5.11 (V-), U7.4 (V-); also elsewhere on the board
/CTRL_REF: U2.13 (CTRL_REF); also elsewhere on the board
/DRY_LEVEL: U2.19 (CTRL5); also elsewhere on the board
/INPUT1: R18.1, R25.1; also elsewhere on the board
/INPUT2: R60.1, R61.1; also elsewhere on the board
/POLE1_LEVEL: U2.18 (CTRL4); also elsewhere on the board
/POLE2_LEVEL: U2.5 (CTRL3); also elsewhere on the board
/POLE3_LEVEL: U2.7 (CTRL1); also elsewhere on the board
/POLE4_LEVEL: U2.6 (CTRL2); also elsewhere on the board
/QCTRL_CURRENT: U5.12 (Q_CTRL); also elsewhere on the board
/QVCA_INVERT: U7.8; also elsewhere on the board
/REZ_STAGE1_EN: U7.1; also elsewhere on the board
/REZ_STAGE2_EN: U7.9; also elsewhere on the board
/REZ_STAGE3_EN: U7.16; also elsewhere on the board
/SOURCE1_AUDIO_CV: U3.14 (Vc); also elsewhere on the board
/SOURCE1_MOD_CV: U3.3 (Vc); also elsewhere on the board
/SOURCE2_AUDIO_CV: U3.11 (Vc); also elsewhere on the board
/SOURCE2_MOD_CV: U3.6 (Vc); also elsewhere on the board
/VCF_CUTOFF_CV: R72.2; also elsewhere on the board
/VCF_RAW: R67.1, U10.7; also elsewhere on the board
/VREF_2.5V: RV1.1; also elsewhere on the board
/filter_ssi2140/DRY_TAP: R24.2, R26.1, U2.16 (IN5-)
/filter_ssi2140/EXP_CTRL_SUM: C36.2, R38.1, R68.1, TP15.1, U4.8
/filter_ssi2140/FILTER_SUM: R24.1, R36.2, R43.1, TP6.1, U4.1
/filter_ssi2140/P1_OUT: U1.10 (+), U5.4 (OUT1)
/filter_ssi2140/P2_OUT: U1.12 (+), U5.1 (OUT2)
/filter_ssi2140/P3_OUT: U1.3 (+), U5.17 (OUT3)
/filter_ssi2140/P4_OUT: U1.5 (+), U5.14 (OUT4)
/filter_ssi2140/POLE1_BUFFERED: R9.1, R19.1, R33.2, R42.2, TP2.1, U1.8, U1.9 (-)
/filter_ssi2140/POLE1_TAP: R19.2, R20.1, U2.17 (IN4-)
/filter_ssi2140/POLE2_BUFFERED: R28.1, R34.1, R37.2, R56.2, U1.13 (-), U1.14
/filter_ssi2140/POLE2_TAP: R21.1, R28.2, U2.21 (IN3-)
/filter_ssi2140/POLE3_BUFFERED: R1.1, R11.2, R39.1, R49.2, U1.1, U1.2 (-)
/filter_ssi2140/POLE3_TAP: R1.2, R7.1, U2.23 (IN1-)
/filter_ssi2140/POLE4_BUFFERED: R2.1, R10.1, R59.2, TP3.1, U1.6 (-), U1.7
/filter_ssi2140/POLE4_TAP: R2.2, R3.1, U2.22 (IN2-)
/filter_ssi2140/QVCA_IN+: R44.2, R45.1, U5.13 (Q_IN)
/filter_ssi2140/QVCA_OUT: R71.2, U4.6 (-), U5.9 (Q_OUT)
/filter_ssi2140/QVCA_VOLTAGE: R23.2, R70.2, R71.1, TP5.1, U4.7
/filter_ssi2140/VCF_MIXED_OUT: C30.1, R66.1, U10.1; also elsewhere on the board
GND: C1.2, C2.2, C3.2, C4.2, C5.1, C11.2, C12.2, C13.2, C14.2, C15.2, C16.2, C17.2, C18.2, C19.2, C20.2, C24.1, C32.2, C34.2, R3.2, R4.1, R5.2, R6.2, R7.2, R8.2, R20.2, R21.2, R22.2, R26.2, R27.2, R30.2, R31.2, R32.2, R35.2, R44.1, R46.2, R47.2, U3.8 (GND), U4.5 (+), U4.10 (+), U4.12 (+), U5.10 (GND), U7.5 (GND), U7.7, U10.3 (+), U10.5 (+); also elsewhere on the board
unnamed: C13.1, R29.1
unnamed: C34.1, R69.2, R72.1
unnamed: R12.2, RV1.2, RV1.3, TP1.1
unnamed: R33.1, U7.2
unnamed: R40.1, R45.2
unnamed: R40.2, R41.1, TP7.1, U4.14
unnamed: R49.1, U7.15
unnamed: R56.1, U7.10
unnamed: R69.1, RV2.1, RV2.2
unnamed: R8.1, U2.2 (IN1+)
unnamed: R5.1, U2.3 (IN2+)
unnamed: R30.1, U2.4 (IN3+)
unnamed: R22.1, U2.8 (IN4+)
unnamed: R32.1, U2.9 (IN5+)
unnamed: R27.1, U2.10 (IN6+)
unnamed: R31.1, U2.15 (IN6-)
unnamed: R29.2, U3.1 (Vref)
unnamed: R25.2, U3.2 (Iin)
unnamed: C36.1, R68.2, RV2.3, U3.4 (Iout), U3.5 (Iout), U4.9 (-)
unnamed: R60.2, U3.7 (Iin)
unnamed: R61.2, U3.10 (Iin)
unnamed: R23.1, R43.2, U3.12 (Iout), U3.13 (Iout), U4.2 (-)
unnamed: R18.2, U3.15 (Iin)
unnamed: R70.1, U4.3 (+), U7.6
unnamed: R4.2, R41.2, U4.13 (-), U7.3, U7.11, U7.14
unnamed: C16.1, U5.5 (CAP1)
unnamed: R9.2, R35.1, R36.1, U5.6 (IN1)
unnamed: C14.1, U5.2 (CAP2)
unnamed: R34.2, R42.1, R47.1, U5.3 (IN2)
unnamed: C17.1, U5.18 (CAP3)
unnamed: R37.1, R39.2, R46.1, U5.19 (IN3)
unnamed: C18.1, U5.15 (CAP4)
unnamed: R6.1, R10.2, R11.1, U5.16 (IN4)
unnamed: R12.1, R38.2, U5.7 (EXPO_CTRL), U5.8 (TEMPCO)
unnamed: C30.2, R66.2, U2.12 (MIX), U10.2 (-)
unnamed: R59.1, R67.2, U10.6 (-)

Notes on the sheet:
Nominal Z-card source is 4V p-p. Recommended input of 2140 is 2V p-p going into 10k/200 resistor divider for 40mV p-p at input pin (or 1V p-p, depending which part of datasheet you read!). Cut Z-card source by 1/2 through 3364 VCA in and feedback R. The 15k feedback R is required for the QVCA out, 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
Allow modulation at 4V p-p to cover >50% the filter range. => At -18.4mV/octave control, shoot for ~100mV p-p control.
OFFSET
Decoupling caps close to pins
RC filter @ ~1250 Hz
Sheet Vref load: 24k
An overly complex resonance compensation scheme is attempted. SSI app note AN701 details this using the SSI2164. This attempts the concept. Pole 1 switchable with a weight of 1. Pole 2 switchable with a weight of 1. Pole 3 switchable with a weight of 2. Pole 4 hardwired in the 2140 with a weight of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
VCF Control Inputs
Output and Scaling
48kHz lowpass for stability
Unused / Spares
Recommended input of 2190 is 10V p-p going into 50k/220 resistor divider: 40mV p-p at input pin, per datasheet. Using 20k/220 for divider should give about the same level.
Control Range: Datasheet: -18.4 mV/oct; 0V => 1 kHz Design for range of 13.75 Hz to 14080 Hz (ten octaves) log2(f1/f2)*(-18.4mV) for range: 113.8mV : 13.75Hz; -70.2mV : 14080 Hz Shoot for range a bit greater than this by allowing scaling & offset
If it weren't for QVCA voltage compliance this could be 1-opamp as a diff amp
All filter caps 1% CG0
Filter and Mixer Core
48kHz lowpass
SCALING
A couple things on that opamp U11B... 15k is useful as the I-to-V for the 3364 VCA outputs. So 15k all around. The QVCA input can be switched phase based on the invert switch. This works as a summing only because the 3364 is current output, not voltage.
Resonance Compensation

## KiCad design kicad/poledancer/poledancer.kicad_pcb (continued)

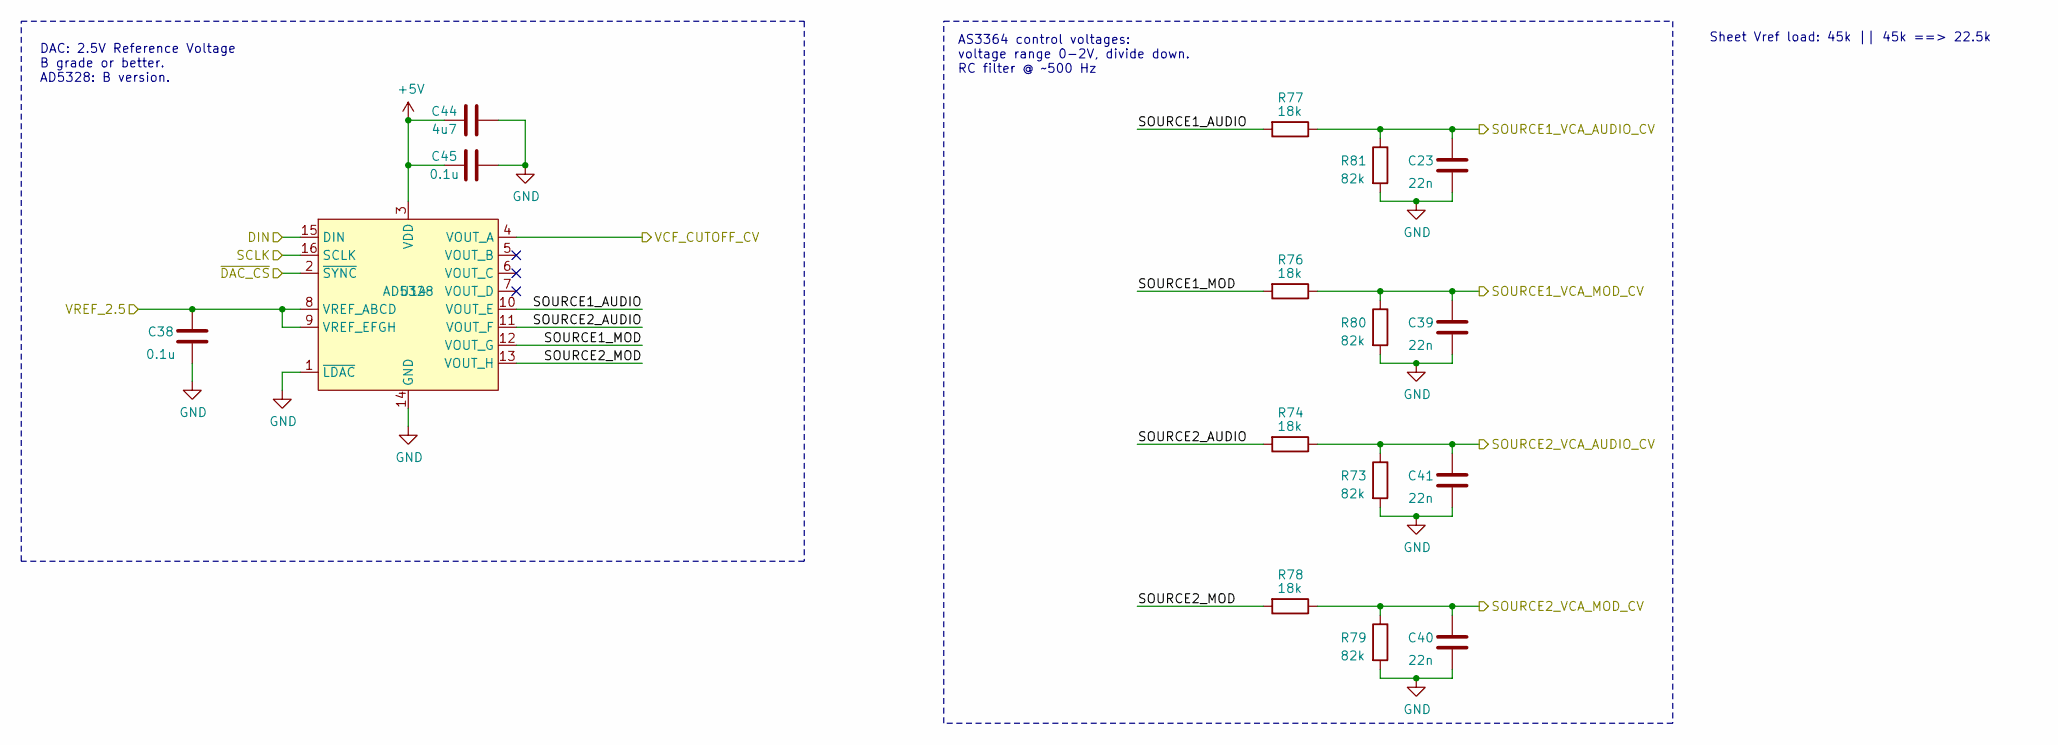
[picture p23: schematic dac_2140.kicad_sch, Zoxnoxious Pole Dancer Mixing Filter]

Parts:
C23, C39, C40, C41: 22n; C_0603_1608Metric; LCSC C21122
C38, C45: 0.1u; C_0603_1608Metric; LCSC C14663
C44: 4u7; C_0603_1608Metric; LCSC C19666
R73, R79, R80, R81: 82k; R_0603_1608Metric; LCSC C23254
R74, R76, R77, R78: 18k; R_0603_1608Metric; LCSC C25810
U14: AD5328; TSSOP-16_4.4x5mm_P0.65mm; LCSC C29162

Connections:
+5V: C44.1, C45.1, U14.3 (VDD); also elsewhere on the board
/SOURCE1_AUDIO_CV: C23.1, R77.1, R81.1; also elsewhere on the board
/SOURCE1_MOD_CV: C39.1, R76.1, R80.1; also elsewhere on the board
/SOURCE2_AUDIO_CV: C41.1, R73.1, R74.1; also elsewhere on the board
/SOURCE2_MOD_CV: C40.1, R78.1, R79.1; also elsewhere on the board
/SPI_CLK: U14.16 (SCLK); also elsewhere on the board
/SPI_CS0: U14.2 (~SYNC); also elsewhere on the board
/SPI_MOSI: U14.15 (DIN); also elsewhere on the board
/VCF_CUTOFF_CV: U14.4 (VOUT_A); also elsewhere on the board
/VREF_2.5V: C38.1, U14.8 (VREF_ABCD), U14.9 (VREF_EFGH); also elsewhere on the board
/dac_2140/SOURCE1_AUDIO: R77.2, U14.10 (VOUT_E)
/dac_2140/SOURCE1_MOD: R76.2, U14.12 (VOUT_G)
/dac_2140/SOURCE2_AUDIO: R74.2, U14.11 (VOUT_F)
/dac_2140/SOURCE2_MOD: R78.2, U14.13 (VOUT_H)
GND: C23.2, C38.2, C39.2, C40.2, C41.2, C44.2, C45.2, R73.2, R79.2, R80.2, R81.2, U14.1 (~LDAC), U14.14 (GND); also elsewhere on the board

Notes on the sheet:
AS3364 control voltages: voltage range 0-2V, divide down. RC filter @ ~500 Hz
DAC: 2.5V Reference Voltage B grade or better. AD5328: B version.
Sheet Vref load: 45k || 45k ==> 22.5k

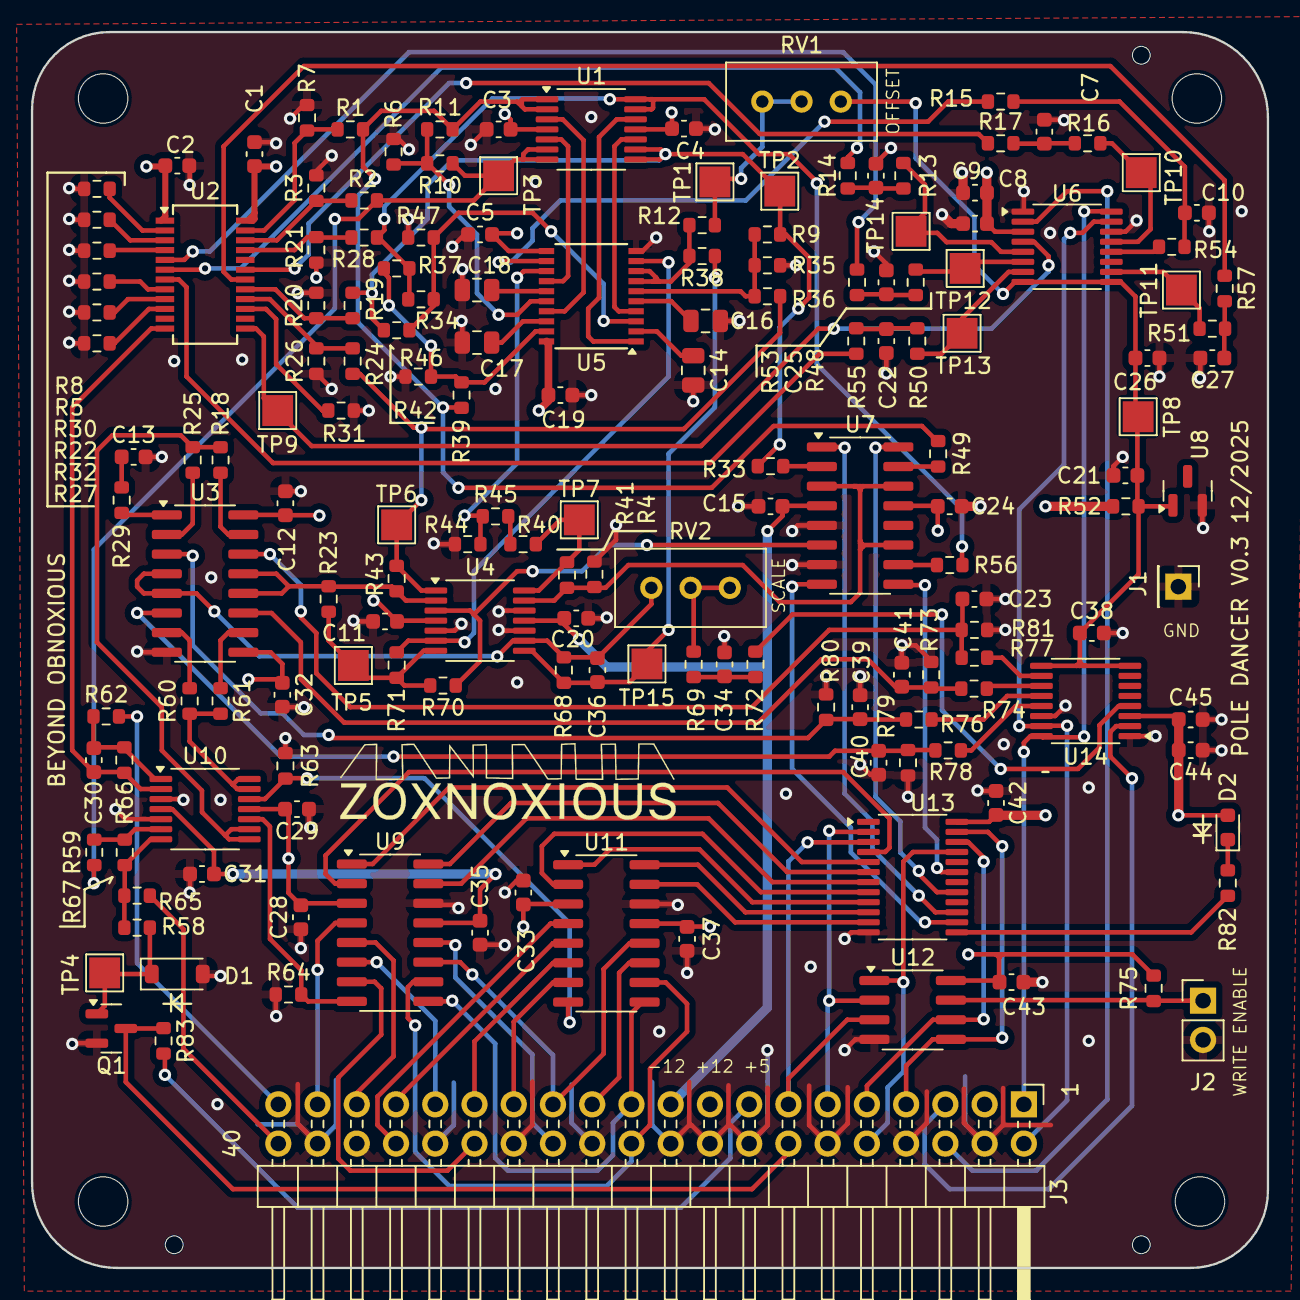
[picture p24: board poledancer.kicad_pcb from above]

Board: 4 copper layers, 80.0 x 80.0 mm, 169 parts (0 on the bottom side), 134 nets.

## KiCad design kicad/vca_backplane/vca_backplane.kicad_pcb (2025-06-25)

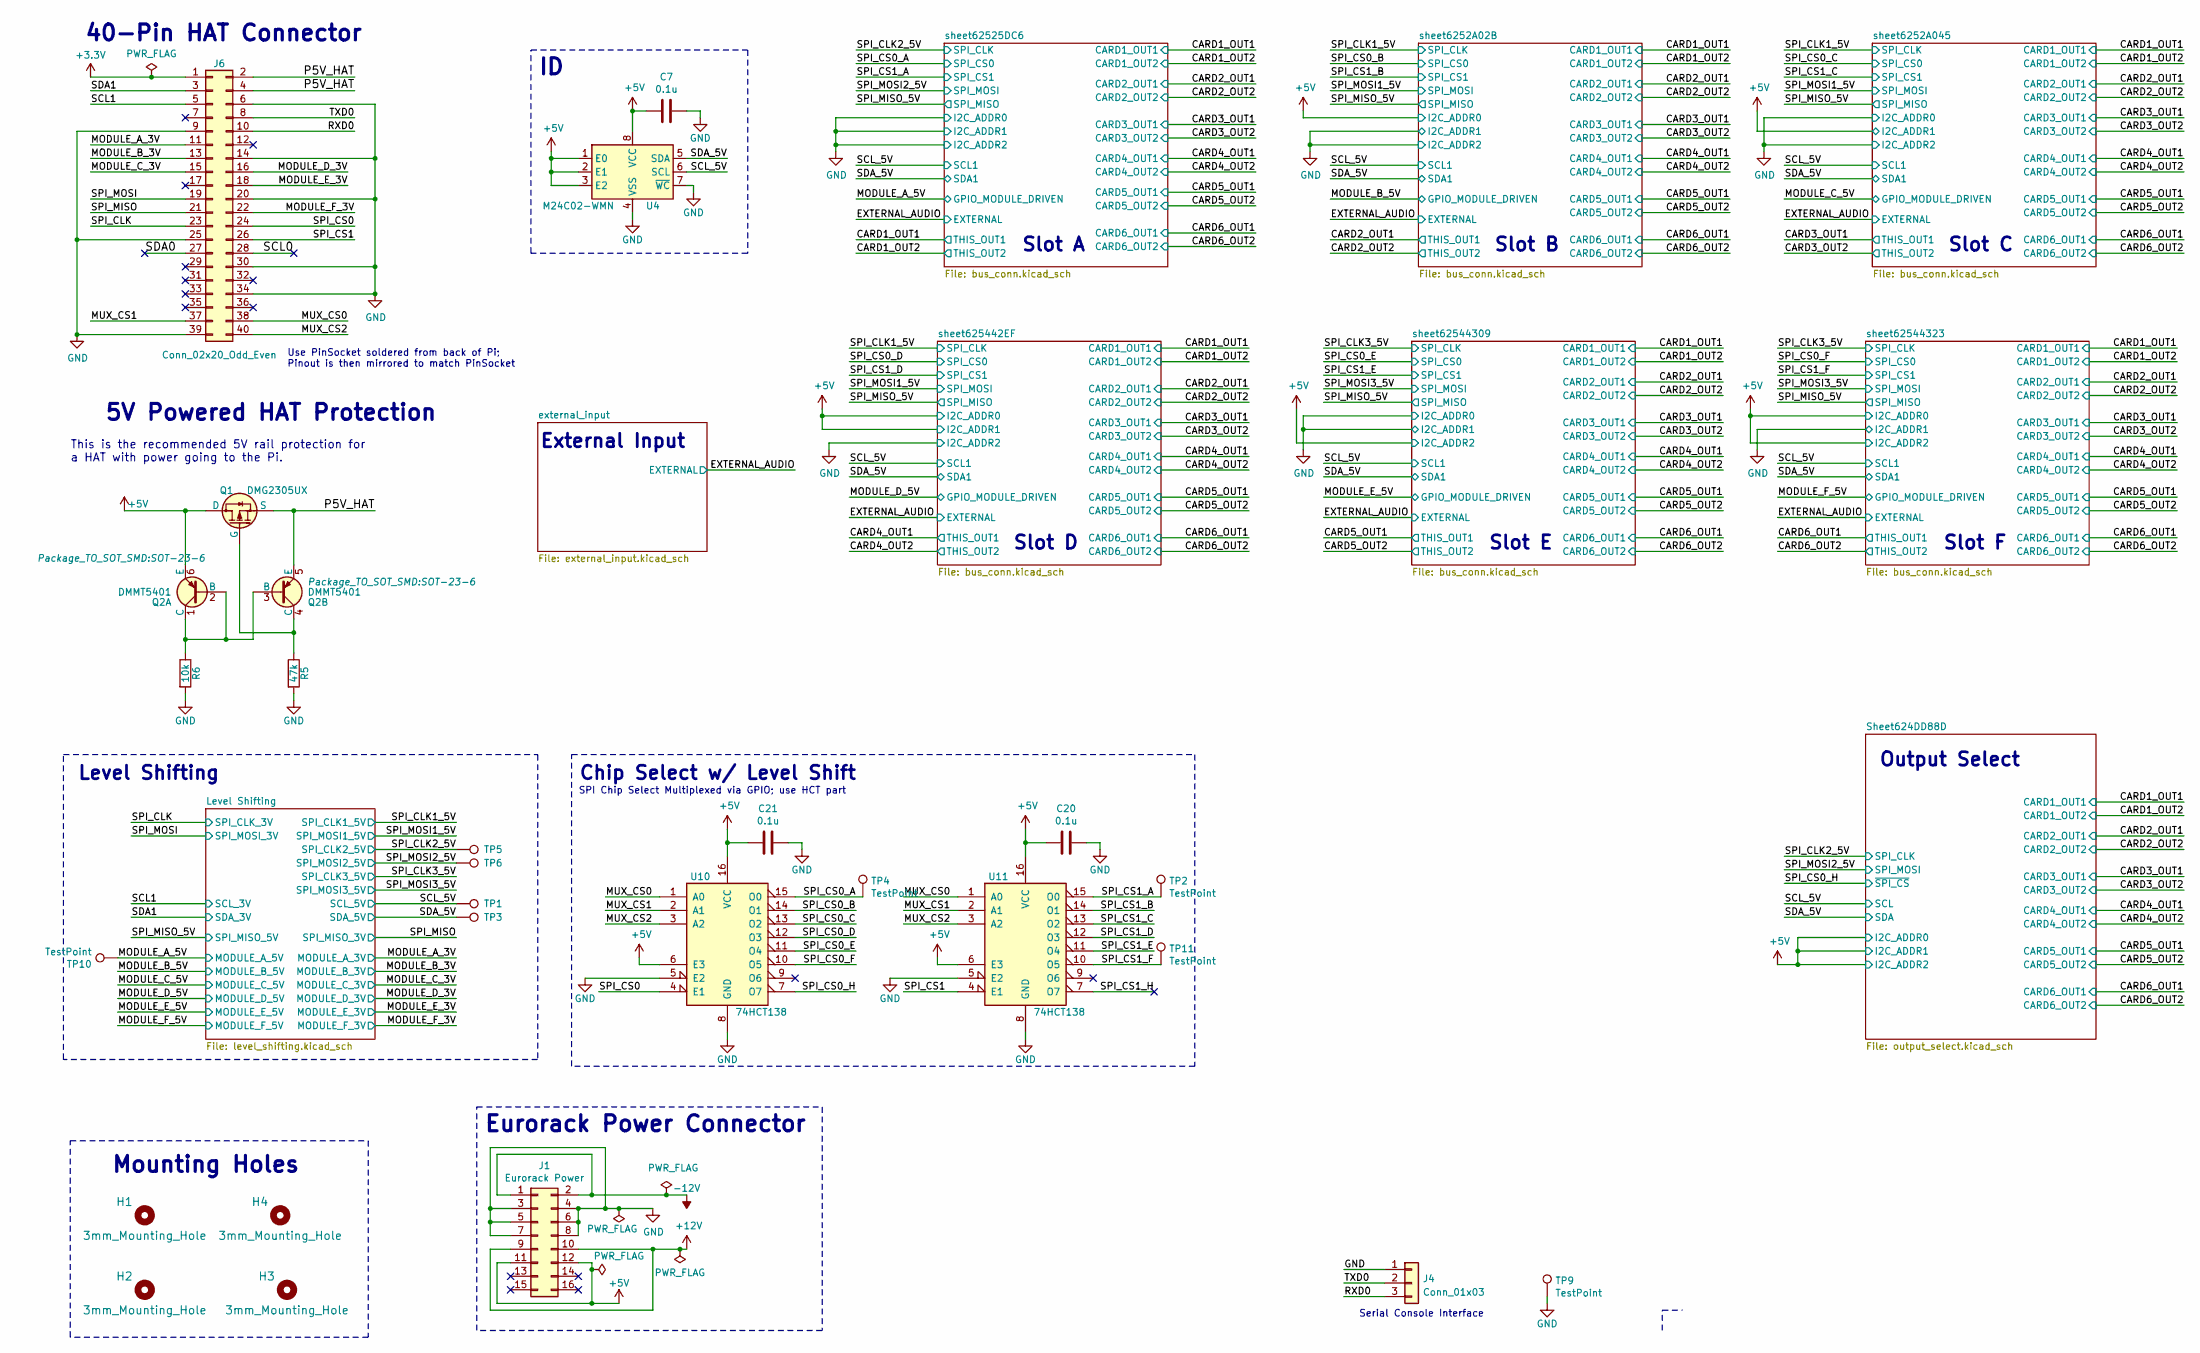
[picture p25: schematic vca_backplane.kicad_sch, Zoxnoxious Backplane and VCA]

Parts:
C7, C20, C21: 0.1u; C_0603_1608Metric; LCSC C14663
H1, H2, H3, H4: 3mm_Mounting_Hole; MountingHole_3.2mm_M3_Pad
J1: Eurorack Power; PinHeader_2x08_P2.54mm_ShroudedKey; Digikey S9171-ND
J4: Conn_01x03; PinHeader_1x03_P2.54mm_Vertical
J6: Conn_02x20_Odd_Even; PinHeader_2x20_P2.54mm_Vertical; Digikey S9200-ND
Q1: DMG2305UX; SOT-23-DMG2305UX; LCSC C150470
Q2: DMMT5401; SOT-23-6; LCSC C154733
R5: 47k; R_0603_1608Metric; LCSC C25819
R6: 10k; R_0603_1608Metric; LCSC C25804
TP1, TP2, TP3, TP4, TP5, TP6, TP10, TP11: TestPoint; TestPoint_Pad_2.0x2.0mm; Digikey 952-2664-2-ND
TP9: TestPoint; PinHeader_1x01_P2.54mm_Vertical; Digikey 952-2664-2-ND
U4: M24C02-WMN; SOIC-8_3.9x4.9mm_P1.27mm; LCSC C7562
U10, U11: 74HCT138; TSSOP-16_4.4x5mm_P0.65mm; LCSC C8115

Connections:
+3.3V: J6.1; also elsewhere on the board
+5V: C7.2, C20.2, C21.2, J1.11, J1.12, Q1.3 (D), Q2.6 (E), U4.1 (E0), U4.2 (E1), U4.3 (E2), U4.8 (VCC), U10.6 (E3), U10.16 (VCC), U11.6 (E3), U11.16 (VCC); also elsewhere on the board
+12V: J1.9, J1.10; also elsewhere on the board
-12V: J1.1, J1.2; also elsewhere on the board
/MODULE_A_3V: J6.11; also elsewhere on the board
/MODULE_A_5V: TP10.1; also elsewhere on the board
/MODULE_B_3V: J6.13; also elsewhere on the board
/MODULE_C_3V: J6.15; also elsewhere on the board
/MODULE_D_3V: J6.16; also elsewhere on the board
/MODULE_E_3V: J6.18; also elsewhere on the board
/MODULE_F_3V: J6.22; also elsewhere on the board
/MUX_CS0: J6.38, U10.1 (A0), U11.1 (A0)
/MUX_CS1: J6.37, U10.2 (A1), U11.2 (A1)
/MUX_CS2: J6.40, U10.3 (A2), U11.3 (A2)
/P5V_HAT: J6.2, J6.4, Q1.2 (S), Q2.5 (E)
/RXD0: J4.3, J6.10
/SCL0: J6.28
/SCL1: J6.5; also elsewhere on the board
/SCL_5V: TP1.1, U4.6 (SCL); also elsewhere on the board
/SDA0: J6.27
/SDA1: J6.3; also elsewhere on the board
/SDA_5V: TP3.1, U4.5 (SDA); also elsewhere on the board
/SPI_CLK: J6.23; also elsewhere on the board
/SPI_CLK2_5V: TP5.1; also elsewhere on the board
/SPI_CS0: J6.24, U10.4 (E1)
/SPI_CS0_A: TP4.1, U10.15 (O0); also elsewhere on the board
/SPI_CS0_B: U10.14 (O1); also elsewhere on the board
/SPI_CS0_C: U10.13 (O2); also elsewhere on the board
/SPI_CS0_D: U10.12 (O3); also elsewhere on the board
/SPI_CS0_E: U10.11 (O4); also elsewhere on the board
/SPI_CS0_F: U10.10 (O5); also elsewhere on the board
/SPI_CS0_H: U10.7 (O7); also elsewhere on the board
/SPI_CS1: J6.26, U11.4 (E1)
/SPI_CS1_A: TP2.1, U11.15 (O0); also elsewhere on the board
/SPI_CS1_B: U11.14 (O1); also elsewhere on the board
/SPI_CS1_C: U11.13 (O2); also elsewhere on the board
/SPI_CS1_D: U11.12 (O3); also elsewhere on the board
/SPI_CS1_E: U11.11 (O4); also elsewhere on the board
/SPI_CS1_F: TP11.1, U11.10 (O5); also elsewhere on the board
/SPI_CS1_H: U11.7 (O7)
/SPI_MISO: J6.21; also elsewhere on the board
/SPI_MOSI: J6.19; also elsewhere on the board
/SPI_MOSI2_5V: TP6.1; also elsewhere on the board
/TXD0: J4.2, J6.8
GND: C7.1, C20.1, C21.1, J1.3, J1.4, J1.5, J1.6, J1.7, J1.8, J4.1, J6.6, J6.9, J6.14, J6.20, J6.25, J6.30, J6.34, J6.39, R5.2, R6.2, TP9.1, U4.4 (VSS), U4.7 (~WC), U10.5 (E2), U10.8 (GND), U11.5 (E2), U11.8 (GND); also elsewhere on the board
unnamed: Q1.1 (G), Q2.4 (C), R5.1
unnamed: Q2.1 (C), Q2.2 (B), Q2.3 (B), R6.1

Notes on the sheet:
5V Powered HAT Protection
Slot A
External Input
Slot F
Level Shifting
Slot D
This is the recommended 5V rail protection for a HAT with power going to the Pi.
Serial Console Interface
Chip Select w/ Level Shift
Eurorack Power Connector
40-Pin HAT Connector
Output Select
Use PinSocket soldered from back of Pi; Pinout is then mirrored to match PinSocket
Slot C
Slot B
Mounting Holes
SPI Chip Select Multiplexed via GPIO; use HCT part
Slot E

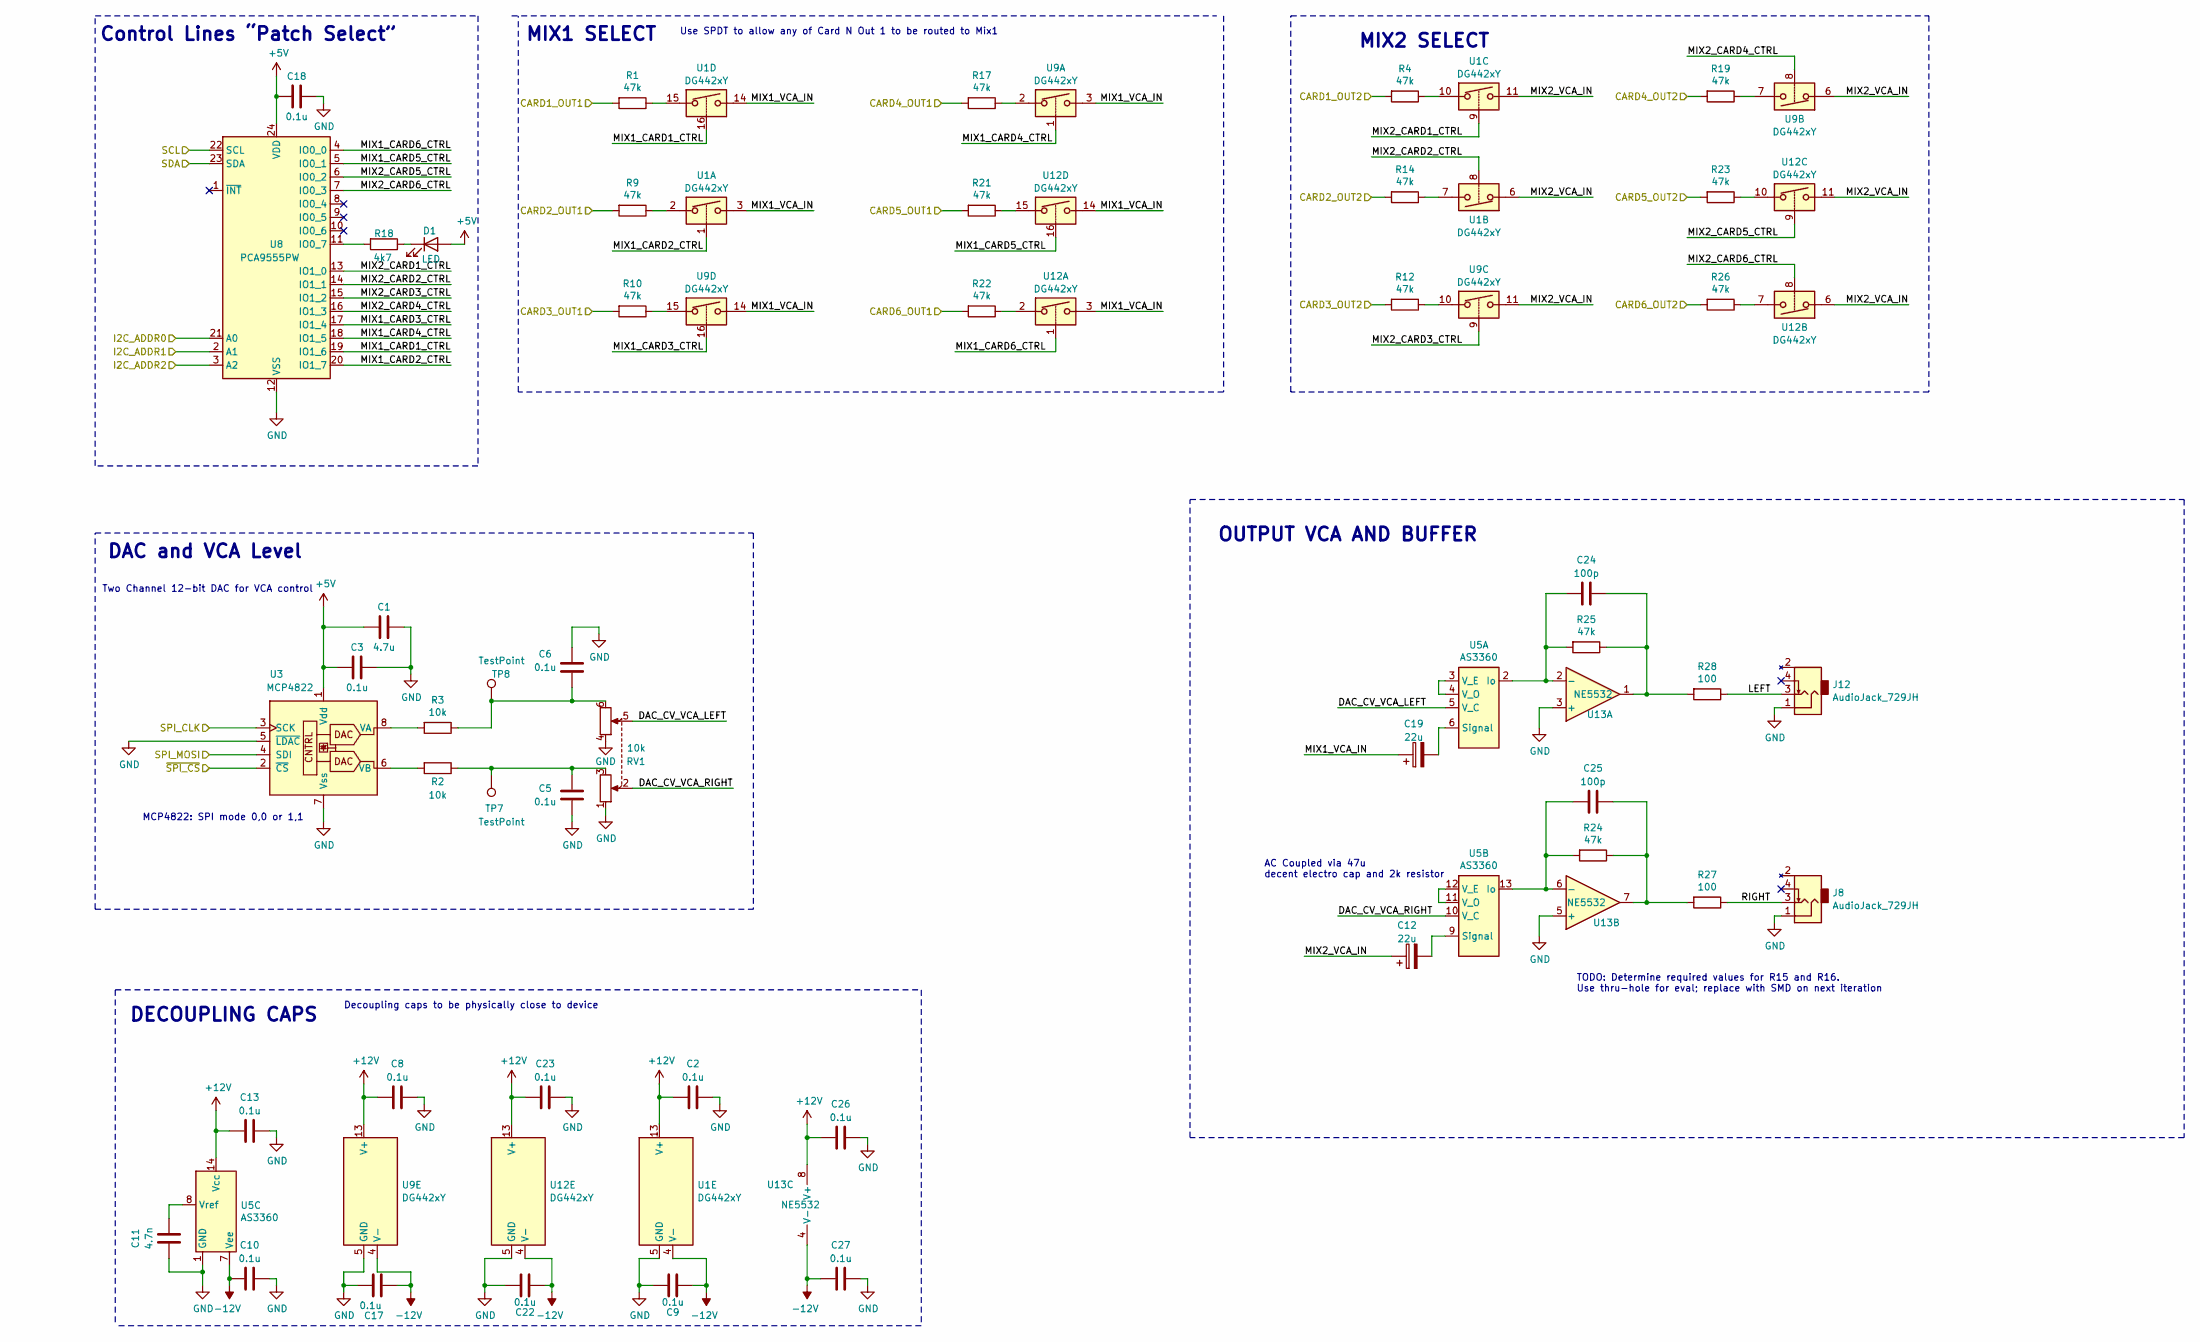
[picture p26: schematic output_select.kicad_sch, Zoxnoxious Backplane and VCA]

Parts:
C1: 4.7u; C_0805_2012Metric; LCSC C1779
C2, C3, C5, C6, C8, C9, C10, C13, C17, C18, C22, C23, C26, C27: 0.1u; C_0603_1608Metric; LCSC C14663
C11: 4.7n; C_0603_1608Metric; LCSC C53987
C12, C19: 22u; CP_Radial_D6.3mm_P2.50mm; Digikey 493-10780-1-ND
C24, C25: 100p; C_0603_1608Metric; LCSC C14858
D1: LED; LED_0603_1608Metric; LCSC C2286
J8, J12: AudioJack_729JH; Jack_3.5mm_729JH-R_Horizontal
R1, R4, R9, R10, R12, R14, R17, R19, R21, R22, R23, R24, R25, R26: 47k; R_0603_1608Metric; LCSC C25819
R2, R3: 10k; R_0603_1608Metric; LCSC C25804
R18: 4k7; R_0603_1608Metric; LCSC C23162
R27, R28: 100; R_0603_1608Metric; LCSC C22775
RV1: 10k; TRIM_PTN092-H10115K1B; Digikey PTN092-H10115K1A
TP7, TP8: TestPoint; TestPoint_Pad_2.0x2.0mm; Digikey 952-2664-2-ND
U1, U9, U12: DG442xY; SOIC-16_3.9x9.9mm_P1.27mm; LCSC C2673321
U3: MCP4822; SOIC-8_3.9x4.9mm_P1.27mm; LCSC C16040
U5: AS3360; SOIC-14_3.9x8.7mm_P1.27mm
U8: PCA9555PW; TSSOP-24_4.4x7.8mm_P0.65mm; LCSC C83265
U13: NE5532; SOIC-8_3.9x4.9mm_P1.27mm; LCSC C7426

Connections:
+5V: C1.2, C3.2, C18.2, D1.2 (A), U3.1 (Vdd), U8.2 (A1), U8.3 (A2), U8.21 (A0), U8.24 (VDD); also elsewhere on the board
+12V: C2.1, C8.1, C13.1, C23.1, C26.1, U1.13 (V+), U5.14 (Vcc), U9.13 (V+), U12.13 (V+), U13.8 (V+); also elsewhere on the board
-12V: C9.2, C10.1, C17.2, C22.2, C27.1, U1.4 (V-), U5.7 (Vee), U9.4 (V-), U12.4 (V-), U13.4 (V-); also elsewhere on the board
/CARD1_OUT1: R1.2; also elsewhere on the board
/CARD1_OUT2: R4.2; also elsewhere on the board
/CARD2_OUT1: R9.2; also elsewhere on the board
/CARD2_OUT2: R14.2; also elsewhere on the board
/CARD3_OUT1: R10.2; also elsewhere on the board
/CARD3_OUT2: R12.2; also elsewhere on the board
/CARD4_OUT1: R17.2; also elsewhere on the board
/CARD4_OUT2: R19.2; also elsewhere on the board
/CARD5_OUT1: R21.2; also elsewhere on the board
/CARD5_OUT2: R23.2; also elsewhere on the board
/CARD6_OUT1: R22.2; also elsewhere on the board
/CARD6_OUT2: R26.2; also elsewhere on the board
/SCL_5V: U8.22 (SCL); also elsewhere on the board
/SDA_5V: U8.23 (SDA); also elsewhere on the board
/SPI_CLK2_5V: U3.3 (SCK); also elsewhere on the board
/SPI_CS0_H: U3.2 (~CS); also elsewhere on the board
/SPI_MOSI2_5V: U3.4 (SDI); also elsewhere on the board
/Sheet624DD88D/DAC_CV_VCA_LEFT: RV1.5, U5.5 (V_C)
/Sheet624DD88D/DAC_CV_VCA_RIGHT: RV1.2, U5.10 (V_C)
/Sheet624DD88D/LEFT: J12.3, R28.1
/Sheet624DD88D/MIX1_CARD1_CTRL: U1.16, U8.19 (IO1_6)
/Sheet624DD88D/MIX1_CARD2_CTRL: U1.1, U8.20 (IO1_7)
/Sheet624DD88D/MIX1_CARD3_CTRL: U8.17 (IO1_4), U9.16
/Sheet624DD88D/MIX1_CARD4_CTRL: U8.18 (IO1_5), U9.1
/Sheet624DD88D/MIX1_CARD5_CTRL: U8.5 (IO0_1), U12.16
/Sheet624DD88D/MIX1_CARD6_CTRL: U8.4 (IO0_0), U12.1
/Sheet624DD88D/MIX1_VCA_IN: C19.1, U1.3, U1.14, U9.3, U9.14, U12.3, U12.14
/Sheet624DD88D/MIX2_CARD1_CTRL: U1.9, U8.13 (IO1_0)
/Sheet624DD88D/MIX2_CARD2_CTRL: U1.8, U8.14 (IO1_1)
/Sheet624DD88D/MIX2_CARD3_CTRL: U8.15 (IO1_2), U9.9
/Sheet624DD88D/MIX2_CARD4_CTRL: U8.16 (IO1_3), U9.8
/Sheet624DD88D/MIX2_CARD5_CTRL: U8.6 (IO0_2), U12.9
/Sheet624DD88D/MIX2_CARD6_CTRL: U8.7 (IO0_3), U12.8
/Sheet624DD88D/MIX2_VCA_IN: C12.1, U1.6, U1.11, U9.6, U9.11, U12.6, U12.11
/Sheet624DD88D/RIGHT: J8.3, R27.1
GND: C1.1, C2.2, C3.1, C5.1, C6.2, C8.2, C9.1, C10.2, C11.1, C13.2, C17.1, C18.1, C22.1, C23.2, C26.2, C27.2, J8.1, J12.1, RV1.1, RV1.4, U1.5 (GND), U3.5 (~LDAC), U3.7 (Vss), U5.1 (GND), U8.12 (VSS), U9.5 (GND), U12.5 (GND), U13.3 (+), U13.5 (+); also elsewhere on the board
unnamed: C5.2, R2.1, RV1.3, TP7.1
unnamed: C6.1, R3.1, RV1.6, TP8.1
unnamed: C24.2, R25.1, R28.2, U13.1
unnamed: C25.2, R24.1, R27.2, U13.7
unnamed: D1.1 (K), R18.1
unnamed: R1.1, U1.15
unnamed: R4.1, U1.10
unnamed: R9.1, U1.2
unnamed: R10.1, U9.15
unnamed: R12.1, U9.10
unnamed: R14.1, U1.7
unnamed: R17.1, U9.2
unnamed: R19.1, U9.7
unnamed: R21.1, U12.15
unnamed: R22.1, U12.2
unnamed: R23.1, U12.10
unnamed: R26.1, U12.7
unnamed: R3.2, U3.8 (VA)
unnamed: R2.2, U3.6 (VB)
unnamed: C19.2, U5.6 (Signal)
unnamed: U5.3 (V_E), U5.4 (V_O)
unnamed: C12.2, U5.9 (Signal)
unnamed: U5.11 (V_O), U5.12 (V_E)
unnamed: C11.2, U5.8 (Vref)
unnamed: R18.2, U8.11 (IO0_7)
unnamed: C24.1, R25.2, U5.2 (Io), U13.2 (-)
unnamed: C25.1, R24.2, U5.13 (Io), U13.6 (-)

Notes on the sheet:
Two Channel 12-bit DAC for VCA control
DECOUPLING CAPS
TODO: Determine required values for R15 and R16. Use thru-hole for eval; replace with SMD on next iteration
Decoupling caps to be physically close to device
DAC and VCA Level
Use SPDT to allow any of Card N Out 1 to be routed to Mix1
MIX2 SELECT
OUTPUT VCA AND BUFFER
AC Coupled via 47u decent electro cap and 2k resistor
MCP4822: SPI mode 0,0 or 1,1
MIX1 SELECT
Control Lines “Patch Select”

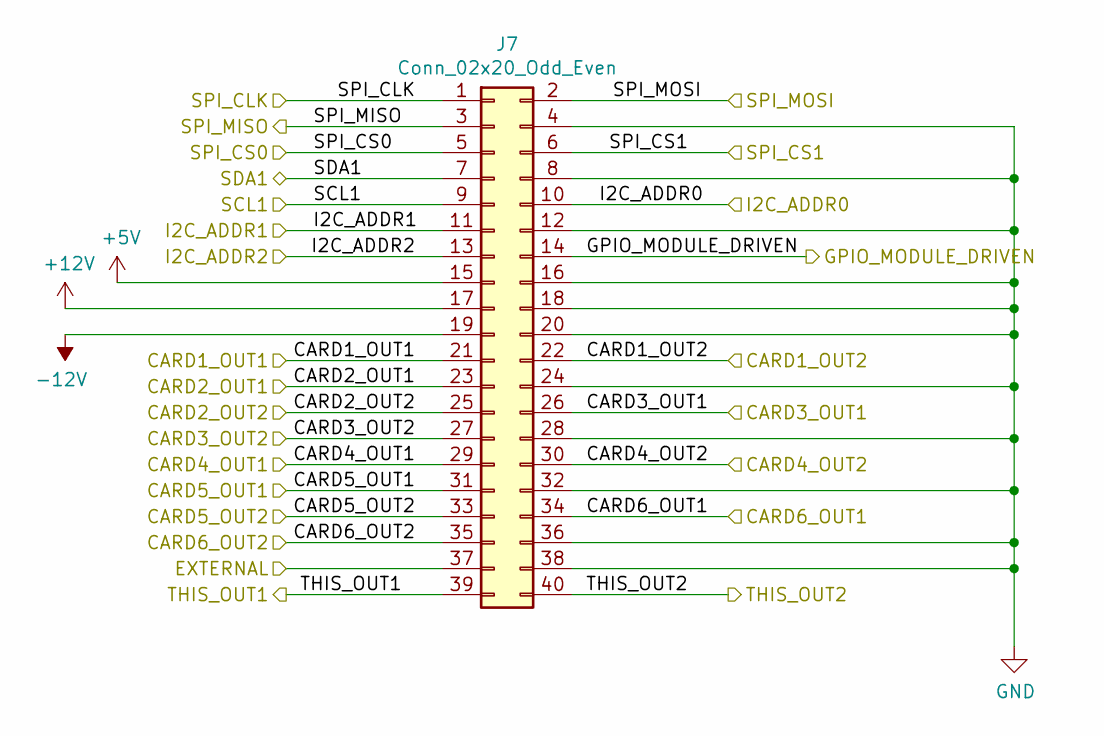
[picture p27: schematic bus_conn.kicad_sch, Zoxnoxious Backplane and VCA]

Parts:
J7: Conn_02x20_Odd_Even; PinSocket_2x20_P2.54mm_SullinsPolarized; Digikey S9200-ND

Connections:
+5V: J7.10, J7.11, J7.15; also elsewhere on the board
+12V: J7.17; also elsewhere on the board
-12V: J7.19; also elsewhere on the board
/CARD1_OUT1: J7.21; also elsewhere on the board
/CARD1_OUT2: J7.22; also elsewhere on the board
/CARD2_OUT1: J7.23; also elsewhere on the board
/CARD2_OUT2: J7.25; also elsewhere on the board
/CARD3_OUT1: J7.26; also elsewhere on the board
/CARD3_OUT2: J7.27; also elsewhere on the board
/CARD4_OUT1: J7.29, J7.39; also elsewhere on the board
/CARD4_OUT2: J7.30, J7.40; also elsewhere on the board
/CARD5_OUT1: J7.31; also elsewhere on the board
/CARD5_OUT2: J7.33; also elsewhere on the board
/CARD6_OUT1: J7.34; also elsewhere on the board
/CARD6_OUT2: J7.35; also elsewhere on the board
/EXTERNAL_AUDIO: J7.37; also elsewhere on the board
/MODULE_D_5V: J7.14; also elsewhere on the board
/SCL_5V: J7.9; also elsewhere on the board
/SDA_5V: J7.7; also elsewhere on the board
/SPI_CLK1_5V: J7.1; also elsewhere on the board
/SPI_CS0_D: J7.5; also elsewhere on the board
/SPI_CS1_D: J7.6; also elsewhere on the board
/SPI_MISO_5V: J7.3; also elsewhere on the board
/SPI_MOSI1_5V: J7.2; also elsewhere on the board
GND: J7.4, J7.8, J7.12, J7.13, J7.16, J7.18, J7.20, J7.24, J7.28, J7.32, J7.36, J7.38; also elsewhere on the board

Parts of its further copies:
J2, J3, J5, J10, J11: Conn_02x20_Odd_Even; PinSocket_2x20_P2.54mm_SullinsPolarized; Digikey S9200-ND

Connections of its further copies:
+5V: J2.10, J2.15, J3.15, J5.11, J5.15, J10.13, J10.15, J11.10, J11.13, J11.15; also elsewhere on the board
+12V: J2.17, J3.17, J5.17, J10.17, J11.17; also elsewhere on the board
-12V: J2.19, J3.19, J5.19, J10.19, J11.19; also elsewhere on the board
/CARD1_OUT1: J2.21, J3.21, J3.39, J5.21, J10.21, J11.21; also elsewhere on the board
/CARD1_OUT2: J2.22, J3.22, J3.40, J5.22, J10.22, J11.22; also elsewhere on the board
/CARD2_OUT1: J2.23, J2.39, J3.23, J5.23, J10.23, J11.23; also elsewhere on the board
/CARD2_OUT2: J2.25, J2.40, J3.25, J5.25, J10.25, J11.25; also elsewhere on the board
/CARD3_OUT1: J2.26, J3.26, J5.26, J5.39, J10.26, J11.26; also elsewhere on the board
/CARD3_OUT2: J2.27, J3.27, J5.27, J5.40, J10.27, J11.27; also elsewhere on the board
/CARD4_OUT1: J2.29, J3.29, J5.29, J10.29, J11.29; also elsewhere on the board
/CARD4_OUT2: J2.30, J3.30, J5.30, J10.30, J11.30; also elsewhere on the board
/CARD5_OUT1: J2.31, J3.31, J5.31, J10.31, J10.39, J11.31; also elsewhere on the board
/CARD5_OUT2: J2.33, J3.33, J5.33, J10.33, J10.40, J11.33; also elsewhere on the board
/CARD6_OUT1: J2.34, J3.34, J5.34, J10.34, J11.34, J11.39; also elsewhere on the board
/CARD6_OUT2: J2.35, J3.35, J5.35, J10.35, J11.35, J11.40; also elsewhere on the board
/EXTERNAL_AUDIO: J2.37, J3.37, J5.37, J10.37, J11.37; also elsewhere on the board
/MODULE_A_5V: J3.14; also elsewhere on the board
/MODULE_B_5V: J2.14; also elsewhere on the board
/MODULE_C_5V: J5.14; also elsewhere on the board
/MODULE_E_5V: J10.14; also elsewhere on the board
/MODULE_F_5V: J11.14; also elsewhere on the board
/SCL_5V: J2.9, J3.9, J5.9, J10.9, J11.9; also elsewhere on the board
/SDA_5V: J2.7, J3.7, J5.7, J10.7, J11.7; also elsewhere on the board
/SPI_CLK1_5V: J2.1, J5.1; also elsewhere on the board
/SPI_CLK2_5V: J3.1; also elsewhere on the board
/SPI_CLK3_5V: J10.1, J11.1; also elsewhere on the board
/SPI_CS0_A: J3.5; also elsewhere on the board
/SPI_CS0_B: J2.5; also elsewhere on the board
/SPI_CS0_C: J5.5; also elsewhere on the board
/SPI_CS0_E: J10.5; also elsewhere on the board
/SPI_CS0_F: J11.5; also elsewhere on the board
/SPI_CS1_A: J3.6; also elsewhere on the board
/SPI_CS1_B: J2.6; also elsewhere on the board
/SPI_CS1_C: J5.6; also elsewhere on the board
/SPI_CS1_E: J10.6; also elsewhere on the board
/SPI_CS1_F: J11.6; also elsewhere on the board
/SPI_MISO_5V: J2.3, J3.3, J5.3, J10.3, J11.3; also elsewhere on the board
/SPI_MOSI1_5V: J2.2, J5.2; also elsewhere on the board
/SPI_MOSI2_5V: J3.2; also elsewhere on the board
/SPI_MOSI3_5V: J10.2, J11.2; also elsewhere on the board
GND: J2.4, J2.8, J2.11, J2.12, J2.13, J2.16, J2.18, J2.20, J2.24, J2.28, J2.32, J2.36, J2.38, J3.4, J3.8, J3.10, J3.11, J3.12, J3.13, J3.16, J3.18, J3.20, J3.24, J3.28, J3.32, J3.36, J3.38, J5.4, J5.8, J5.10, J5.12, J5.13, J5.16, J5.18, J5.20, J5.24, J5.28, J5.32, J5.36, J5.38, J10.4, J10.8, J10.10, J10.11, J10.12, J10.16, J10.18, J10.20, J10.24, J10.28, J10.32, J10.36, J10.38, J11.4, J11.8, J11.11, J11.12, J11.16, J11.18, J11.20, J11.24, J11.28, J11.32, J11.36, J11.38; also elsewhere on the board

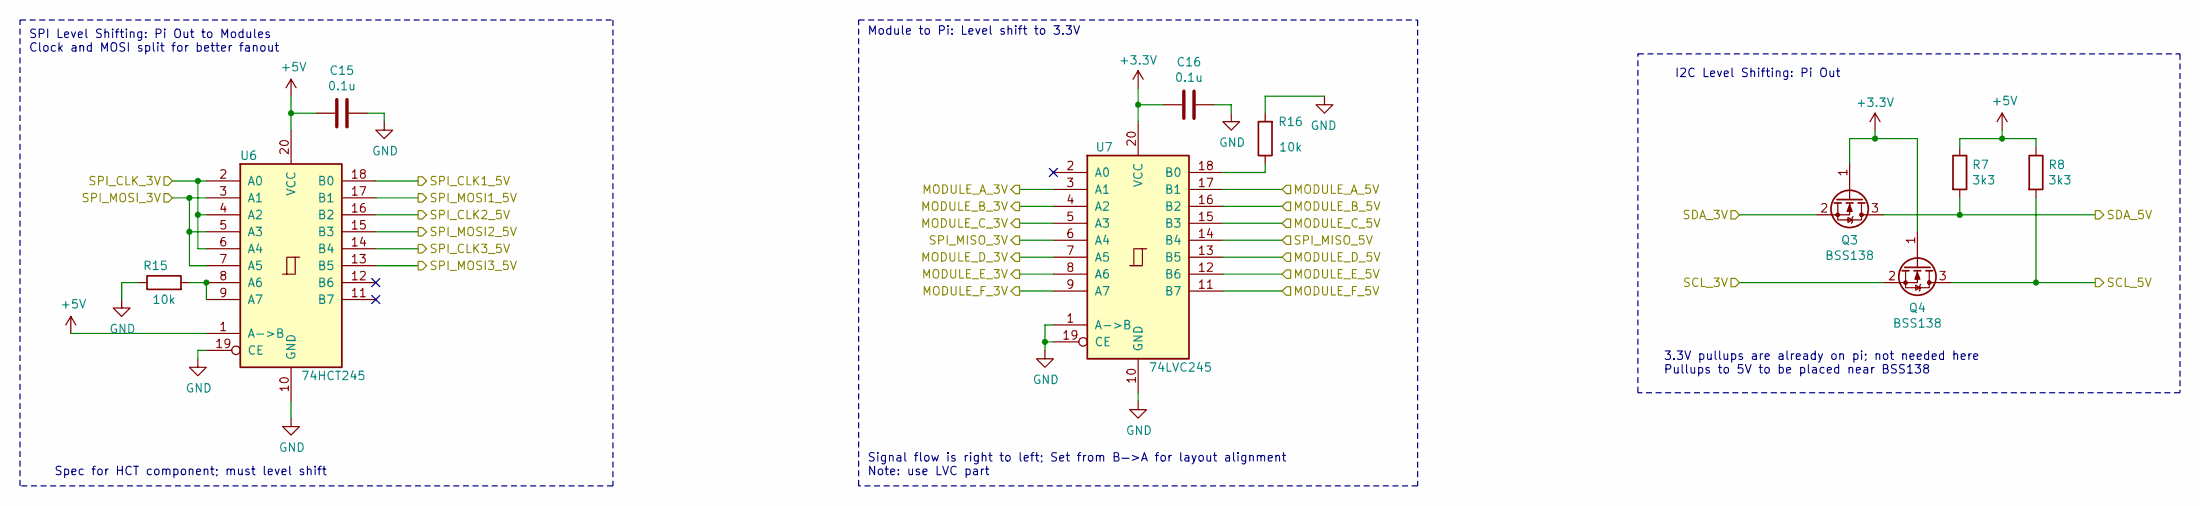
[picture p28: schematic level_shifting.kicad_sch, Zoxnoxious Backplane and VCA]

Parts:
C15, C16: 0.1u; C_0603_1608Metric; LCSC C14663
Q3, Q4: BSS138; SOT-23; LCSC C82045
R7, R8: 3k3; R_0603_1608Metric; LCSC C22978
R15, R16: 10k; R_0603_1608Metric; LCSC C25804
U6: 74HCT245; TSSOP-20_4.4x6.5mm_P0.65mm; LCSC C5980
U7: 74LVC245; TSSOP-20_4.4x6.5mm_P0.65mm; LCSC C6082

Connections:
+3.3V: C16.2, Q3.1 (G), Q4.1 (G), U7.20 (VCC); also elsewhere on the board
+5V: C15.2, R7.1, R8.1, U6.1 (A->B), U6.20 (VCC); also elsewhere on the board
/MODULE_A_3V: U7.3 (A1); also elsewhere on the board
/MODULE_A_5V: U7.17 (B1); also elsewhere on the board
/MODULE_B_3V: U7.4 (A2); also elsewhere on the board
/MODULE_B_5V: U7.16 (B2); also elsewhere on the board
/MODULE_C_3V: U7.5 (A3); also elsewhere on the board
/MODULE_C_5V: U7.15 (B3); also elsewhere on the board
/MODULE_D_3V: U7.7 (A5); also elsewhere on the board
/MODULE_D_5V: U7.13 (B5); also elsewhere on the board
/MODULE_E_3V: U7.8 (A6); also elsewhere on the board
/MODULE_E_5V: U7.12 (B6); also elsewhere on the board
/MODULE_F_3V: U7.9 (A7); also elsewhere on the board
/MODULE_F_5V: U7.11 (B7); also elsewhere on the board
/SCL1: Q4.2 (S); also elsewhere on the board
/SCL_5V: Q4.3 (D), R8.2; also elsewhere on the board
/SDA1: Q3.2 (S); also elsewhere on the board
/SDA_5V: Q3.3 (D), R7.2; also elsewhere on the board
/SPI_CLK: U6.2 (A0), U6.4 (A2), U6.6 (A4); also elsewhere on the board
/SPI_CLK1_5V: U6.18 (B0); also elsewhere on the board
/SPI_CLK2_5V: U6.16 (B2); also elsewhere on the board
/SPI_CLK3_5V: U6.14 (B4); also elsewhere on the board
/SPI_MISO: U7.6 (A4); also elsewhere on the board
/SPI_MISO_5V: U7.14 (B4); also elsewhere on the board
/SPI_MOSI: U6.3 (A1), U6.5 (A3), U6.7 (A5); also elsewhere on the board
/SPI_MOSI1_5V: U6.17 (B1); also elsewhere on the board
/SPI_MOSI2_5V: U6.15 (B3); also elsewhere on the board
/SPI_MOSI3_5V: U6.13 (B5); also elsewhere on the board
GND: C15.1, C16.1, R15.1, R16.2, U6.10 (GND), U6.19 (CE), U7.1 (A->B), U7.10 (GND), U7.19 (CE); also elsewhere on the board
unnamed: R15.2, U6.8 (A6), U6.9 (A7)
unnamed: R16.1, U7.18 (B0)

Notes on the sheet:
SPI Level Shifting: Pi Out to Modules Clock and MOSI split for better fanout
I2C Level Shifting: Pi Out
Module to Pi: Level shift to 3.3V
Spec for HCT component; must level shift
3.3V pullups are already on pi; not needed here Pullups to 5V to be placed near BSS138
Signal flow is right to left; Set from B—>A for layout alignment Note: use LVC part

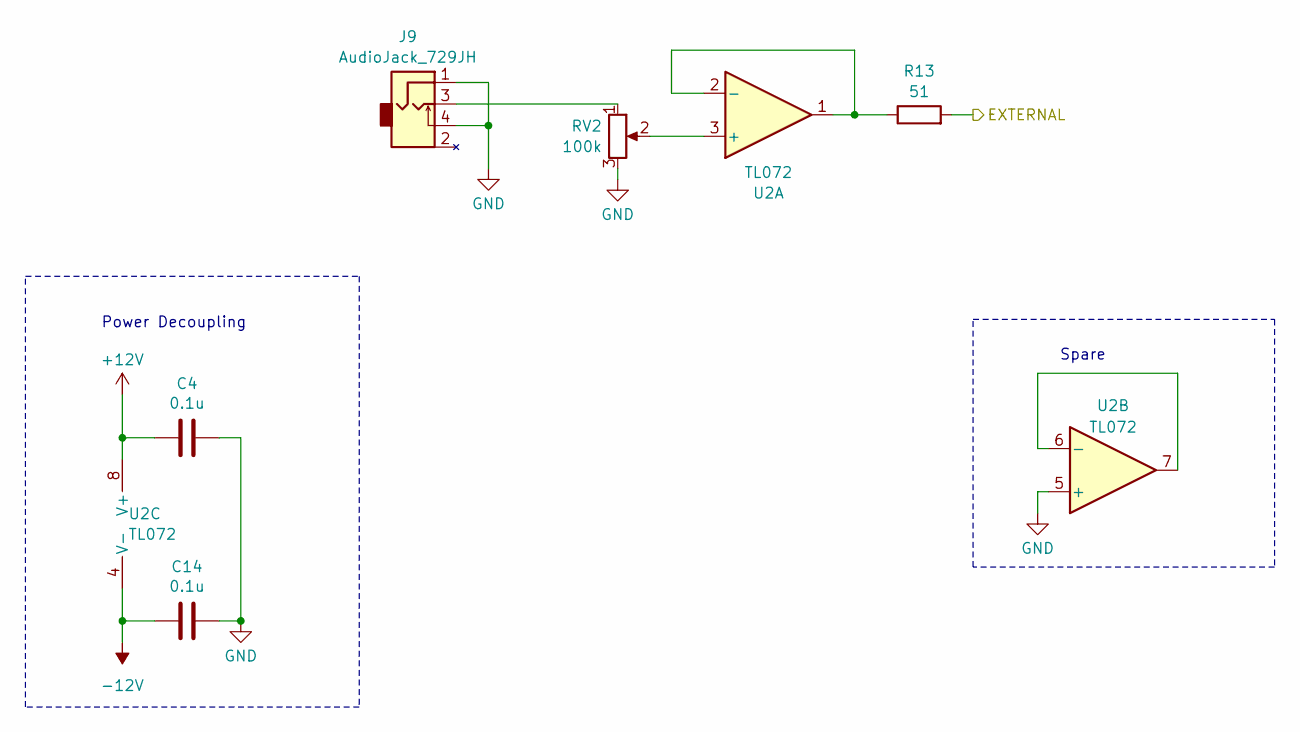
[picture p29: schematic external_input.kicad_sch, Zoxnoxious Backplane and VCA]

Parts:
C4, C14: 0.1u; C_0603_1608Metric; LCSC C14663
J9: AudioJack_729JH; Jack_3.5mm_729JH-R_Horizontal
R13: 51; R_0603_1608Metric; LCSC C23197
RV2: 100k; TRIM_PTN091-H10115K1B; Digikey PTN091-H100115K1A
U2: TL072; SOIC-8_3.9x4.9mm_P1.27mm; LCSC C6961

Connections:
+12V: C4.2, U2.8 (V+); also elsewhere on the board
-12V: C14.2, U2.4 (V-); also elsewhere on the board
/EXTERNAL_AUDIO: R13.2; also elsewhere on the board
GND: C4.1, C14.1, J9.1, J9.4, RV2.3, U2.5 (+); also elsewhere on the board
unnamed: J9.3, RV2.1
unnamed: RV2.2, U2.3 (+)
unnamed: R13.1, U2.1, U2.2 (-)
unnamed: U2.6 (-), U2.7

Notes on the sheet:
Spare
Power Decoupling

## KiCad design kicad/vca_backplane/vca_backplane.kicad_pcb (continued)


Board: 4 copper layers, 133.8 x 102.9 mm, 100 parts (0 on the bottom side), 118 nets.

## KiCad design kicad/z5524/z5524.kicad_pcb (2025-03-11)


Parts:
C10, C30, C61, C78: 1u; C_0603_1608Metric; LCSC C15849
C17, C67: 2u2; C_0603_1608Metric; LCSC C23630
C29, C41, C42, C56, C76, C77: 0.1u; C_0603_1608Metric; LCSC C14663
C43, C48: 100p; C_0603_1608Metric; LCSC C14858
C59, C63: 1u; CP_EIA-3216-10_Kemet-I; Mouser 80-T491A105K016
D2: LED; LED_0603_1608Metric; LCSC C2286
D10: 1N4148WS; D_SOD-323; LCSC C2128
J1: Conn_01x01; PinHeader_1x01_P2.54mm_Vertical
J2: Conn_02x20_Odd_Even; PinHeader_2x20_P2.54mm_Horizontal
J3: Conn_01x02; PinHeader_1x02_P2.54mm_Vertical
Q2: MMBT3904; SOT-23; LCSC C20526
R21: 2k; R_0603_1608Metric; LCSC C22975
R46: 240; R_0805_2012Metric; LCSC C17572
R47: 1k; R_0603_1608Metric; LCSC C21190
R62: 4k7; R_0603_1608Metric; LCSC C23162
R64: 20k; R_0603_1608Metric; LCSC C4184
R66, R76: 51; R_0603_1608Metric; LCSC C23197
R75: 24k; R_0603_1608Metric; LCSC C23352
R105: 680; R_0603_1608Metric; LCSC C23228
R107: 10k; R_0603_1608Metric; LCSC C25804
R109: 100k; R_0603_1608Metric; LCSC C25803
R111: 5k1; R_0603_1608Metric; LCSC C23186
TP7, TP11: TestPoint; TestPoint_Pad_1.5x1.5mm
U3: LM4040B25FTA; SOT-23; LCSC C460725
U8: TL074; TSSOP-14_4.4x5mm_P0.65mm; LCSC C96507
U9: LM337L_TO92; TO-92_Inline_Wide
U11: DG442DY-T1-E3; SOIC-16_3.9x9.9mm_P1.27mm; LCSC C2673321
U12: PCA9555D; TSSOP-24_4.4x7.8mm_P0.65mm; LCSC C83265
U13: TL072; SO-8_3.9x4.9mm_P1.27mm; LCSC C6961
U16: 78L05G-AB3-R; SOT-89-3; LCSC C71136
U19: LM4040AIM3-4.1; SOT-23; LCSC C126807
U20: M24C02-WMN; SOIC-8_3.9x4.9mm_P1.27mm; LCSC C7562

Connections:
+5V: C41.2, C77.2, D2.2 (A), J2.15, R21.1, R105.1, R107.2, R111.1, U12.24 (VDD), U20.8 (VCC); also elsewhere on the board
+5VA: C30.1, U16.1 (VO); also elsewhere on the board
+12V: C42.1, C61.1, C76.1, J2.17, U11.13 (V+), U13.8 (V+), U16.3 (VI); also elsewhere on the board
-6V: C59.2, R46.1, U9.2 (VO); also elsewhere on the board
-12V: C29.1, C56.1, C63.2, J2.19, U9.3 (VI), U11.4 (V-), U13.4 (V-); also elsewhere on the board
/AS3394/VCA_OUTPUT: C43.1, R64.1, U13.2 (-); also elsewhere on the board
/AS3394_VCA: C43.2, R64.2, R76.1, R109.2, U13.1
/AS3394_VCO: C17.2; also elsewhere on the board
/FM2130_MOD_CTRL: U12.16 (IO1_3); also elsewhere on the board
/GPIO_MODULE_DRIVEN: J2.14, Q2.3 (C), R107.1
/HARDSYNC_2130_CTRL: U12.14 (IO1_1); also elsewhere on the board
/I2C_ADDR0: J2.10, U12.21 (A0), U20.1 (E0)
/I2C_ADDR1: J2.11, U12.2 (A1), U20.2 (E1)
/I2C_ADDR2: J2.13, U12.3 (A2), U20.3 (E2)
/LED_CTRL: R62.2, U12.11 (IO0_7)
/Mod_VCA/Source2: C17.1; also elsewhere on the board
/PWM2130_MOD_CTRL: U12.13 (IO1_0); also elsewhere on the board
/PWM3394_MOD_CTRL: U12.8 (IO0_4); also elsewhere on the board
/SCL1: J2.9, U12.22 (SCL), U20.6 (SCL)
/SDA1: J2.7, U12.23 (SDA), U20.5 (SDA)
/SOFTSYNC_2130_CTRL: U12.15 (IO1_2); also elsewhere on the board
/SPI_CLK: J2.1; also elsewhere on the board
/SPI_CS0: J2.5; also elsewhere on the board
/SPI_CS1: J2.6; also elsewhere on the board
/SPI_MOSI: J2.2; also elsewhere on the board
/SSI2130/MIX_OUT: C48.1, R75.1, U8.13 (-); also elsewhere on the board
/SSI2130_VCO: C48.2, R66.1, R75.2, TP7.1, U8.14; also elsewhere on the board
/THIS_OUT1: J2.39, R76.2
/THIS_OUT2: J2.40, R66.2
/VCF3394_MOD_CTRL: U12.9 (IO0_5); also elsewhere on the board
/VCO3394_EXP_MOD_CTRL: U12.17 (IO1_4); also elsewhere on the board
/VREF_2.5: C10.1, C78.1, R21.2, U3.1 (K); also elsewhere on the board
/VREF_4.096: C67.2, R105.2, U19.1 (K); also elsewhere on the board
/WAVESELECT_1: U12.19 (IO1_6); also elsewhere on the board
/WAVESELECT_2: U12.20 (IO1_7); also elsewhere on the board
/WAVESELECT_MOD_CTRL: U12.18 (IO1_5); also elsewhere on the board
GND: C10.2, C29.2, C30.2, C41.1, C42.2, C56.2, C59.1, C61.2, C63.1, C67.1, C76.2, C77.1, C78.2, D10.2 (A), J1.1, J2.4, J2.8, J2.12, J2.16, J2.18, J2.20, J2.24, J2.28, J2.32, J2.36, J2.38, J3.2, Q2.2 (E), R47.2, U3.2 (A), U8.12 (+), U11.5 (GND), U12.12 (VSS), U13.3 (+), U13.5 (+), U16.2 (GND), U19.2 (A), U20.4 (VSS); also elsewhere on the board
unnamed: D2.1 (K), R62.1
unnamed: D10.1 (K), Q2.1 (B), R109.1, TP11.1
unnamed: J3.1, R111.2, U20.7 (~WC)
unnamed: R46.2, R47.1, U9.1 (ADJ)
unnamed: U13.6 (-), U13.7

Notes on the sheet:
Power Decoupling & Voltage References
For current thru LM4040 of: 1000uA to 75uA Given VREF_4.096 load: 7.4k: 583 < Rs < 1458; Prefer "B" part
DAC 3394
Tantalum
Digital output for tuning
2x20 connection interface
Load: -19mA
SSI2130
VREF_2.5 load: 2k3 (13k || 2k8) 1250 < Rs < 2155 choose something close to 2k for current 1000uA : 70uA LCSC part prefer "B" part
GPIO for switch control I2C address 0100{addr2,addr1,addr0}
AS3364
Unused
AS3394
GND Test Point
Board ID in EEPROM I2C address 1010{addr2,addr1,addr0} Write enable via jumper
Interface: Zoxnoxious bus interface. Digital on one side, power in the middle, analog on the other. This card will drive THIS_OUT1 and THIS_OUT2 and GPIO_MODULE_DRIVEN. The other lines are tapped into for various functionality.
Output levels: 3.8V p-p for sawtooth at full gain LPF: 66 khz
DAC 2130
Load: 20mA


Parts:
C6, C8, C9: 1u; C_0603_1608Metric; LCSC C15849
C11, C12, C13, C27: 0.1u; C_0603_1608Metric; LCSC C14663
C14: 4u7; C_0603_1608Metric; LCSC C19666
C15: 4n7; C_0603_1608Metric; LCSC C53987
C18, C23: 6n8; C_0603_1608Metric; LCSC C1631
C37: 220n; C_0603_1608Metric; LCSC C21120
R4, R10, R15: 1k; R_0603_1608Metric; LCSC C21190
R14, R16, R17: 49k9; R_0603_1608Metric; LCSC C23184
R18, R25: 20k; R_0603_1608Metric; LCSC C4184
R19, R22: 10k; R_0603_1608Metric; LCSC C25804
R27, R29: 82k; R_0603_1608Metric; LCSC C23254
R37, R41: 18k; R_0603_1608Metric; LCSC C25810
R56: 15k; R_0603_1608Metric; LCSC C22809
R58: 2k; R_0603_1608Metric; LCSC C22975
R59: 680; R_0603_1608Metric; LCSC C23228
U4: AD5328; TSSOP-16_4.4x5mm_P0.65mm; LCSC C29162
U5: TL072; SO-8_3.9x4.9mm_P1.27mm; LCSC C6961

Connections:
+5V: C13.1, C14.1, U4.3 (VDD); also elsewhere on the board
+12V: C27.1, U5.8 (V+); also elsewhere on the board
-12V: C12.1, U5.4 (V-); also elsewhere on the board
/AS3394_MOD_CV: C18.1, R27.1, R37.1; also elsewhere on the board
/AS3394_SINE_CV: C23.1, R29.1, R41.1; also elsewhere on the board
/DAC 2130/AS3394_SINE_CV_DAC: R41.2, U4.10 (VOUT_E)
/DAC 2130/AS3394_VCO_CV_DAC: R37.2, U4.11 (VOUT_F)
/DAC 2130/EXP_PITCH_2130: R56.1; also elsewhere on the board
/DAC 2130/EXP_PITCH_DAC: R59.2, U4.6 (VOUT_C)
/DAC 2130/LINEAR_2130: C15.2, R25.1, U5.1; also elsewhere on the board
/DAC 2130/LINEAR_DAC: R19.2, U4.5 (VOUT_B)
/DAC 2130/PULSE_MIX_2130: R17.1; also elsewhere on the board
/DAC 2130/PULSE_MIX_DAC: R15.2, U4.12 (VOUT_G)
/DAC 2130/PWM_2130: C11.1, R58.1; also elsewhere on the board
/DAC 2130/PWM_DAC: R58.2, U4.7 (VOUT_D)
/DAC 2130/SAW_MIX_2130: R14.1; also elsewhere on the board
/DAC 2130/SAW_MIX_DAC: R4.2, U4.13 (VOUT_H)
/DAC 2130/TRI_MIX_2130: R16.1; also elsewhere on the board
/DAC 2130/TRI_MIX_DAC: R10.2, U4.4 (VOUT_A)
/SPI_CLK: U4.16 (SCLK); also elsewhere on the board
/SPI_CS1: U4.2 (~SYNC); also elsewhere on the board
/SPI_MOSI: U4.15 (DIN); also elsewhere on the board
/VREF_2.5: R18.1, U4.8 (VREF_ABCD), U4.9 (VREF_EFGH); also elsewhere on the board
GND: C6.2, C8.2, C9.2, C11.2, C12.2, C13.2, C14.2, C18.2, C23.2, C27.2, C37.2, R22.1, R27.2, R29.2, U4.1 (~LDAC), U4.14 (GND); also elsewhere on the board
unnamed: C6.1, R4.1, R14.2
unnamed: C8.1, R15.1, R17.2
unnamed: C9.1, R10.1, R16.2
unnamed: C37.1, R56.2, R59.1
unnamed: R18.2, R22.2, U5.3 (+)
unnamed: C15.1, R19.1, R25.2, U5.2 (-)

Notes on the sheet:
PWM: 795 Hz cutoff freq note output impedance for next stage
Linear Gain -2.0 VRef gain: +1.0 Output: Linear_2130 inverts Linear_DAC to +2.5 : -2.5 LPF @ 1700 Hz Cutoff high to allow for higher modulation frequency
Mix DAC lines: ~159 Hz cutoff frequency. Follow with current input control resistors
These lowpass RC numbers are off; they're a bit low. Only took into account source side R in most calcs. I'm not going to recalc them though; they're close enough.
CV for AS3364 VCAs with max level 2.08V (or 1.93V typ) Lowpass @ 1585 Hz
VCO Pitch: From 2.5V source, a 20 uA/octave source for 8 octaves gives 15625 for R. Divide this to a low impedance LPF section with a ~1063 Hz filter. No R value needed on SSI2130 sheet.
Sheet load: Vref_2.5: 45k || 45k || 30k ==> 13k
DAC: 2.5V Reference Voltage Outputs at 1X gain from AD5328. Vref impedance 45k for 1X gain


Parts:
C19, C24, C47: 33p; C_0603_1608Metric; LCSC C1663
C21, C51, C54, C57: 0.1u; C_0603_1608Metric; LCSC C14663
C22: 4n7; C_0603_1608Metric; LCSC C53987
R28, R30, R35, R42, R63, R71, R72: 47k; R_0603_1608Metric; LCSC C25819
R40: 100; R_0603_1608Metric; LCSC C22775
U6: AS3364; SOIC-16_3.9x9.9mm_P1.27mm
U8: TL074; TSSOP-14_4.4x5mm_P0.65mm; LCSC C96507

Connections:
+12V: C21.1, C54.1, U6.16 (Vcc), U8.4 (V+); also elsewhere on the board
-12V: C51.1, C57.1, U6.9 (Vee), U8.11 (V-); also elsewhere on the board
/AS3394_MOD: C24.2, R28.1, U8.1; also elsewhere on the board
/AS3394_MOD_CV: U6.6 (Vc); also elsewhere on the board
/AS3394_SINE: R42.1; also elsewhere on the board
/AS3394_SINE_CV: U6.3 (Vc); also elsewhere on the board
/AS3394_SINE_MOD: C19.2, R30.1, U8.7; also elsewhere on the board
/Mod_VCA/Source2: R35.1; also elsewhere on the board
/SSI2130_MOD: C47.2, R71.1, U8.8; also elsewhere on the board
/SSI2130_MOD_CV: U6.14 (Vc); also elsewhere on the board
/SSI2130_VCO: R72.1; also elsewhere on the board
GND: C21.2, C22.2, C51.2, C54.2, C57.2, R63.2, U6.8 (GND), U6.11 (Vc), U8.3 (+), U8.5 (+), U8.10 (+); also elsewhere on the board
unnamed: C22.1, R40.1
unnamed: R40.2, U6.1 (Vref)
unnamed: R42.2, U6.2 (Iin)
unnamed: C19.1, R30.2, U6.4 (Iout), U8.6 (-)
unnamed: R35.2, U6.7 (Iin)
unnamed: C24.1, R28.2, U6.5 (Iout), U8.2 (-)
unnamed: R63.1, U6.10 (Iin)
unnamed: R72.2, U6.15 (Iin)
unnamed: C47.1, R71.2, U6.13 (Iout), U8.9 (-)

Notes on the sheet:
Unused VCA. Sacrilege.
Datasheet: 5nF
Decoupling to be close to pins


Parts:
C1, C4, C5, C16, C20, C26, C35, C40: 0.1u; C_0603_1608Metric; LCSC C14663
C2, C3, C25: 100p; C_0603_1608Metric; LCSC C14858
C7: 3n9; C_0805_2012Metric; LCSC C541576
C31: 2u2; C_0603_1608Metric; LCSC C23630
C33: 4u7; CP_Radial_D4.0mm_P2.00mm; Digikey 1189-4115-ND
C34, C38, C39: 10n; C_0603_1608Metric; LCSC C57112
D1: 1N5819WS; D_SOD-323; LCSC C191023
Q1: 2N7002K; SOT-23; LCSC C8545
R1, R7: 100k; R_0603_1608Metric; LCSC C25803
R2: 499k; R_0603_1608Metric; LCSC C375514
R3, R33, R34, R36, R38: 20k; R_0603_1608Metric; LCSC C4184
R5: 22k; R_0603_1608Metric; LCSC C31850
R6: 8k2; R_0603_1608Metric; LCSC C25981
R8: 49k9; R_0603_1608Metric; LCSC C23184
R11, R13, R20, R23, R24, R31, R61: 10k; R_0603_1608Metric; LCSC C25804
R12: 1k; R_0603_1608Metric; LCSC C21190
R26, R39: 2k4; R_0603_1608Metric; LCSC C22940
R32: 100; R_0603_1608Metric; LCSC C22775
R43: 4k32; R_0603_1608Metric; LCSC C23158
R44, R51, R52: 4k7; R_0603_1608Metric; LCSC C23162
R48: 267k; R_0603_1608Metric; LCSC C22963
R50: 270; R_0603_1608Metric; LCSC C22966
R53: 15k; R_0603_1608Metric; LCSC C22809
RV1, RV2: 5k; Potentiometer_Bourns_3296W_Vertical
TP1, TP2, TP4, TP5, TP6: TestPoint; TestPoint_Pad_1.5x1.5mm
U1, U5: TL072; SO-8_3.9x4.9mm_P1.27mm; LCSC C6961
U2: SSI2130_no_pad; QFN-32-1EP_4x4mm_P0.4mm_EP2.65x2.65mm_Handsolder_NoPad
U7: LM311; TSSOP-8_4.4x3mm_P0.65mm; LCSC C2876875
U10: DG442DY-T1-E3; SOIC-16_3.9x9.9mm_P1.27mm; LCSC C2673321

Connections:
+5VA: C35.1, R13.2, U2.27 (V+); also elsewhere on the board
+12V: C1.1, C4.1, C40.1, U1.8 (V+), U7.8 (V+), U10.13 (V+); also elsewhere on the board
-6V: C5.2, U2.8 (V-); also elsewhere on the board
-12V: C16.1, C20.2, C26.2, U1.4 (V-), U7.4 (V-), U10.4 (V-); also elsewhere on the board
/AS3394_MOD: C31.1, U10.6; also elsewhere on the board
/AS3394_SINE: TP5.1, U2.24 (SINE_OUT); also elsewhere on the board
/AS3394_SINE_MOD: R39.1; also elsewhere on the board
/AS3394_VCO: C33.1; also elsewhere on the board
/DAC 2130/EXP_PITCH_2130: R7.2, R11.2, R48.1, U2.7 (EXP_FREQ); also elsewhere on the board
/DAC 2130/LINEAR_2130: R31.1, TP4.1; also elsewhere on the board
/DAC 2130/PULSE_MIX_2130: U2.11 (PULSE_MIX); also elsewhere on the board
/DAC 2130/PWM_2130: R6.1; also elsewhere on the board
/DAC 2130/SAW_MIX_2130: U2.10 (SAW_MIX); also elsewhere on the board
/DAC 2130/TRI_MIX_2130: U2.9 (TRI_MIX); also elsewhere on the board
/FM2130_MOD_CTRL: U10.8; also elsewhere on the board
/HARDSYNC_2130_CTRL: U10.16; also elsewhere on the board
/HARD_SYNC_SOURCE: U10.14; also elsewhere on the board
/PWM2130_MOD_CTRL: U10.1; also elsewhere on the board
/SOFTSYNC_2130_CTRL: U10.9; also elsewhere on the board
/SOFT_SYNC_SOURCE: C38.1; also elsewhere on the board
/SSI2130/FM_INPUT: R2.2, U2.21 (LIN_FREQ)
/SSI2130/FM_VOLTAGE: C3.2, R2.1, R3.2, TP1.1, U1.7
/SSI2130/MIX_OUT: U2.25 (MIX_OUT); also elsewhere on the board
/SSI2130/PWM_IN: D1.1 (K), R12.1, U2.32 (PWM_IN+)
/SSI2130/TIME_REVERSE: C2.2, Q1.1 (G), R13.1, TP2.1, U2.18 (TIME_REVERSE), U7.7
/SSI2130/TRI_OUT: U2.1 (TRI_OUT), U2.31 (PWM_IN-)
/VREF_2.5: R7.1, R23.2, R38.1, RV1.2, RV1.3, RV2.1, U2.23 (VREF); also elsewhere on the board
GND: C1.2, C4.2, C5.1, C7.2, C16.2, C20.1, C26.1, C34.1, C35.2, C40.2, D1.2 (A), Q1.2 (S), R8.1, R20.1, R32.2, R43.2, R44.1, R52.1, R61.2, RV2.3, U1.3 (+), U2.15 (DGND), U2.16 (AGND), U2.20 (HFT_BASE), U7.1 (GND), U10.5 (GND); also elsewhere on the board
unnamed: C2.1, R1.2
unnamed: C31.2, R53.1
unnamed: C33.2, R51.1
unnamed: C34.2, R50.2
unnamed: C38.2, TP6.1, U10.10
unnamed: C39.1, U10.15
unnamed: Q1.3 (D), R34.2, U1.5 (+)
unnamed: R5.2, RV1.1
unnamed: R11.1, RV2.2
unnamed: R12.2, R24.1, U5.7
unnamed: R26.1, U10.7
unnamed: R53.2, U10.3
unnamed: C25.1, R26.2, R31.2, R36.1, R38.2, R39.2, U1.2 (-)
unnamed: C3.1, R3.1, R33.2, U1.6 (-)
unnamed: R50.1, U2.26 (BW_COMP)
unnamed: R5.1, U2.22 (EXP_SCALE)
unnamed: C39.2, R61.1, U2.17 (HARD_SYNC)
unnamed: R43.1, R48.2, U2.6 (HF_TRACK)
unnamed: U2.19 (SOFT_SYNC), U10.11
unnamed: C7.1, U2.14 (TCAP)
unnamed: R8.2, U2.12 (AUX1_MIX), U2.13 (AUX2_MIX)
unnamed: R44.2, R51.2, U2.2 (SINE_IN+)
unnamed: R52.2, U2.3 (SINE_IN-)
unnamed: R20.2, R23.1, U5.5 (+)
unnamed: R6.2, R24.2, U5.6 (-), U10.2
unnamed: R1.1, R32.1, U7.2 (+)
unnamed: C25.2, R33.1, R34.1, R36.2, U1.1, U7.3 (-)

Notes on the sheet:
What needs a switch and what doesn't? Linear Level can be set to 0V via DAC EXTERNAL_SINE controlled by VCA alone, no switch MOD_IN VCA has multiple destinations so a switch is in order
PWM modulation: DAC line in at 10k RC (DAC page) + this 10k Mod signal: assume 3.2V p-p for max DAC PWM 0.0 -0.3 : 0.89 1.25 -0.2 : +1.5 2.5 0.3 : 2.1
Sheet Load: Vref 2.5: 25k (100uA per SSI2130 datasheet) || 20k || 20k || 5k || 100k ==> 2k8 LM7805: 3.75mA + 0.5mA LM337: -2.90mA
2130 Core Oscillator Controls
2130 datasheet TZFM circuit
NP0 or equiv
Output -- 2130 mixer controls. The input tri, saw, and pulse are current inputs and expected to be conditioned as such leading into this page.
Tri-to-Sine converter: Decoupled from the rest of the 2130 Using it with the 3394 VCO Input range +/-2.5V

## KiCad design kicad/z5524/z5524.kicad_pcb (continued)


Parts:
C44, C50, C53: 33n; C_0805_2012Metric; Digikey 445-7523-1-ND
C45: 4u7; CP_Radial_D4.0mm_P2.00mm; Digikey 1189-4115-ND
C46, C62, C64, C66: 0.1u; C_0603_1608Metric; LCSC C14663
C55: 560p; C_0603_1608Metric; LCSC C458906
C60: 2n; C_1206_3216Metric; Digikey C1206X202FBGAC7800
D3, D4, D5, D6: 1N4148WS; D_SOD-323; LCSC C2128
D8: 1N5819WS; D_SOD-323; LCSC C191023
R54, R85: 20k; R_0603_1608Metric; LCSC C4184
R55, R74: 75k; R_0603_1608Metric; LCSC C23242
R60: 33k; R_0603_1608Metric; LCSC C4216
R65, R78, R79, R80: 1k; R_0603_1608Metric; LCSC C21190
R81: 510; R_0603_1608Metric; LCSC C23193
R82: 68k; R_0603_1608Metric; LCSC C23231
R86, R89: 39k; R_0603_1608Metric; LCSC C23153
R110: 240k; R_0603_1608Metric; LCSC C4197
TP3, TP8: TestPoint; TestPoint_Pad_1.5x1.5mm
U11: DG442DY-T1-E3; SOIC-16_3.9x9.9mm_P1.27mm; LCSC C2673321
U14: TL074; TSSOP-14_4.4x5mm_P0.65mm; LCSC C96507
U15: AS3394; SOIC-24W_7.5x15.4mm_P1.27mm

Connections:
+5VA: C46.2, D8.1 (K), U15.24 (V+); also elsewhere on the board
+12V: C66.1, U14.4 (V+); also elsewhere on the board
-6V: C64.2, R86.1, R110.1, U15.3 (V-); also elsewhere on the board
-12V: C62.1, U14.11 (V-); also elsewhere on the board
/AS3394/3394_EXT_IN: R65.2, R74.2, U15.14 (VCA2_Input)
/AS3394/FINAL_GAIN_CV: U15.22 (FinalGain_CV); also elsewhere on the board
/AS3394/MIX_CV: U15.13 (Mix_Bal); also elsewhere on the board
/AS3394/MOD_AMOUNT_CV: U15.6 (Mod_Amt); also elsewhere on the board
/AS3394/PWM_SUM: U15.8 (PWM_CV); also elsewhere on the board
/AS3394/RES_CV: U15.15 (Filt_Res); also elsewhere on the board
/AS3394/SAWTOOTH_3394: R80.1, U15.9 (Sawtooth_Out)
/AS3394/VCA_OUTPUT: U15.23 (VCA5_Out); also elsewhere on the board
/AS3394/VCF_SUM: U15.20 (VCF_CV); also elsewhere on the board
/AS3394/VCO_3394: R81.2, U14.10 (+), U15.10 (Wave_Out), U15.11 (VCA1_Input)
/AS3394/VCO_SUM: U15.2 (VCO_CV); also elsewhere on the board
/AS3394/WAVESELECT: D8.2 (A), R78.2, TP8.1, U15.7 (Wave_Select)
/AS3394_VCO: R82.1, TP3.1, U14.8; also elsewhere on the board
/HARD_SYNC_SOURCE: U15.5 (D-TrigOut); also elsewhere on the board
/SOFT_SYNC_SOURCE: R89.2, U14.7; also elsewhere on the board
/SSI2130_MOD: R54.1; also elsewhere on the board
/SSI2130_VCO: R74.1; also elsewhere on the board
/WAVESELECT_1: R60.1; also elsewhere on the board
/WAVESELECT_2: R55.1; also elsewhere on the board
/WAVESELECT_MOD_CTRL: U11.16; also elsewhere on the board
GND: C44.2, C45.2, C46.1, C50.2, C53.2, C55.2, C60.2, C62.2, C64.1, C66.2, D3.2 (A), D5.1 (K), R65.1, R79.1, R81.1, U14.3 (+), U14.5 (+), U15.12 (GND); also elsewhere on the board
unnamed: D3.1 (K), D4.2 (A)
unnamed: C45.1, D4.1 (K), D6.2 (A), U15.21 (Cs)
unnamed: D5.2 (A), D6.1 (K)
unnamed: R54.2, U11.15
unnamed: R78.1, R85.2, U14.1
unnamed: R55.2, R60.2, R85.1, R86.2, U11.14, U14.2 (-)
unnamed: R80.2, R89.1, U14.6 (-)
unnamed: R79.2, R82.2, U14.9 (-)
unnamed: C53.1, U15.16 (C1)
unnamed: C50.1, U15.17 (C2)
unnamed: C44.1, U15.18 (C3)
unnamed: C55.1, U15.19 (C4)
unnamed: C60.1, U15.4 (Ct)
unnamed: R110.2, U15.1 (Iref)

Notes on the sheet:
Wave Select via GPIO pins. With the 2130 used for modulation. MinMod and MaxMod with +/-3V (6V p-p) GPIO at +5V logic level: WaveSelect2 WaveSelect1 Out MinMod MaxMod 0 0 3.3V 1.5V 5.1V 0 1 0.3V 0.2V 3.8V 1 0 2.0V -1.5V 2.1V 1 1 -1.0V -2.8V 0.8V
NP0 or better
Saw: +/-1.76V
Using e a 68k R82 and re-eval VCO Output levels: expected levels; differ from observed levels at 63x gain Waveshape Expected Observed w/ 62k Saw +/- 2.84V +/- 1.64V Tri +/- 3.15V -1.8 : +1.32V Saw+Tri -5.67 +2.84 -2.8 : +1.76V Pulse +/- 1.9V
Filter caps: NP0/C0G or better
500 per datasheet


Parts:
C28, C32: 2u2; C_0603_1608Metric; LCSC C23630
C36: 220n; C_0603_1608Metric; LCSC C21120
C49, C65, C69, C70, C71, C73, C75: 0.1u; C_0603_1608Metric; LCSC C14663
C52, C58, C68: 22n; C_0603_1608Metric; LCSC C21122
C72: 4u7; C_0603_1608Metric; LCSC C19666
C74: 33n; C_0603_1608Metric; LCSC C21117
D7: 1N5819WS; D_SOD-323; LCSC C191023
R45, R91, R97: 30k; R_0603_1608Metric; LCSC C22984
R49, R100: 22k; R_0603_1608Metric; LCSC C31850
R57: 47k; R_0603_1608Metric; LCSC C25819
R67, R69, R70, R77, R88, R92, R96: 10k; R_0603_1608Metric; LCSC C25804
R68, R87: 5k1; R_0603_1608Metric; LCSC C23186
R83, R103: 1k; R_0603_1608Metric; LCSC C21190
R84, R95: 18k; R_0603_1608Metric; LCSC C25810
R90, R98: 20k; R_0603_1608Metric; LCSC C4184
R93: 2k; R_0603_1608Metric; LCSC C22975
R94, R101: 33k; R_0603_1608Metric; LCSC C4216
R99: 3k; R_0603_1608Metric; LCSC C4211
R102: 15k; R_0603_1608Metric; LCSC C22809
R104: 24k; R_0603_1608Metric; LCSC C23352
R106: 68k; R_0603_1608Metric; LCSC C23231
TP9, TP10: TestPoint; TestPoint_Pad_1.5x1.5mm
U11: DG442DY-T1-E3; SOIC-16_3.9x9.9mm_P1.27mm; LCSC C2673321
U14, U17: TL074; TSSOP-14_4.4x5mm_P0.65mm; LCSC C96507
U18: AD5328; TSSOP-16_4.4x5mm_P0.65mm; LCSC C29162

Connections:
+5V: C65.1, C72.1, U18.3 (VDD); also elsewhere on the board
+5VA: D7.1 (K); also elsewhere on the board
+12V: C69.2, U17.4 (V+); also elsewhere on the board
-12V: C73.2, U17.11 (V-); also elsewhere on the board
/AS3394/FINAL_GAIN_CV: C49.1, R69.2; also elsewhere on the board
/AS3394/MIX_CV: C70.2, R92.2, U17.1; also elsewhere on the board
/AS3394/MOD_AMOUNT_CV: C68.1, R87.2; also elsewhere on the board
/AS3394/PWM_SUM: R77.1, U14.14; also elsewhere on the board
/AS3394/RES_CV: C58.1, R68.2; also elsewhere on the board
/AS3394/VCF_SUM: R101.2, TP9.1, U17.14; also elsewhere on the board
/AS3394/VCO_SUM: D7.2 (A), R83.2; also elsewhere on the board
/DAC 3394/FINAL_GAIN_DAC_CV: R69.1, U18.6 (VOUT_C)
/DAC 3394/MIX_DAC_CV: R96.1, U18.4 (VOUT_A)
/DAC 3394/MOD_AMT_DAC_CV: R87.1, U18.7 (VOUT_D)
/DAC 3394/PWM_DAC_CV: R93.1, U18.5 (VOUT_B)
/DAC 3394/RES_DAC_CV: R68.1, U18.10 (VOUT_E)
/DAC 3394/SSI2130_MOD_DAC_CV: R67.1, U18.11 (VOUT_F)
/DAC 3394/VCF_DAC_CV: R103.2, U18.13 (VOUT_H)
/DAC 3394/VCO_DAC_CV: R99.1, U18.12 (VOUT_G)
/PWM3394_MOD_CTRL: U11.8; also elsewhere on the board
/SPI_CLK: U18.16 (SCLK); also elsewhere on the board
/SPI_CS0: U18.2 (~SYNC); also elsewhere on the board
/SPI_MOSI: U18.15 (DIN); also elsewhere on the board
/SSI2130_MOD: C28.1, C32.1, C36.1; also elsewhere on the board
/SSI2130_MOD_CV: C52.2, R67.2, R70.2; also elsewhere on the board
/VCF3394_MOD_CTRL: U11.9; also elsewhere on the board
/VCO3394_EXP_MOD_CTRL: U11.1; also elsewhere on the board
/VREF_4.096: R90.1, R91.1, R100.1, R106.1, U18.8 (VREF_ABCD), U18.9 (VREF_EFGH); also elsewhere on the board
GND: C49.2, C52.1, C58.2, C65.2, C68.2, C69.1, C71.1, C72.2, C73.1, C74.2, C75.2, R70.1, R88.2, R95.1, R98.1, R104.1, U17.10 (+), U18.1 (~LDAC), U18.14 (GND); also elsewhere on the board
unnamed: C28.2, R45.1
unnamed: C32.2, R49.1
unnamed: C36.2, R57.1
unnamed: C71.2, R84.1, R93.2
unnamed: C74.1, R99.2, R102.1
unnamed: C75.1, R94.1, R103.1
unnamed: R45.2, U11.2
unnamed: R49.2, U11.6
unnamed: R57.2, U11.10
unnamed: R83.1, R97.2, TP10.1, U17.7
unnamed: R88.1, R100.2, U14.12 (+)
unnamed: R77.2, R84.2, U11.7, U14.13 (-)
unnamed: R96.2, R98.2, U17.3 (+)
unnamed: C70.1, R90.2, R92.1, U17.2 (-)
unnamed: R91.2, R95.2, U17.5 (+)
unnamed: R97.1, R102.2, U11.3, U17.6 (-)
unnamed: U17.8, U17.9 (-)
unnamed: R104.2, R106.2, U17.12 (+)
unnamed: R94.2, R101.1, U11.11, U17.13 (-)

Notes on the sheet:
PWM Amount: datasheet is 0 : +2V for range For DAC values this circuit gives 1.92V : -0.13 V and yes, that's reverse where high DAC values give low width. Reverse it in software. The 22k value is used instead of a 20k to ensure a negative value for zero pulse. LPF @ 800 Hz
VCO: LPF @ 1.6 kHz via RC filter
VCF: +2.1V : -1.9V Gain inverting: 0.97 Gain non-inverting: 0.51 This should give ~10 octaves from +20kHz to 23Hz LPF @ 1591 Hz. Modulation resistor value: value shoudl give a wide mod range. The modulator is AC coupled, the R value gives a very wide mod range
Resonance Amount: 0 -- 4.1V LPF @ 1.4 kHz
Unused
Sheet Load: Vref 4.096: 45k || 20k || 92k || 48k || 32k ==> 7.4k
Mixer Balance: -2V -- +2V Gain inverting: 0.5 Gain non-inverting: 1.0 LPF @ 159 Hz
Modulation Amount: 0 - 4.1V LPF @ 1.4 kHz
Filtering note: AD5328 datasheet DC output impedance: 0.5 ohm AS3394 input impedance: control inputs "high impedance", < 0.5 nA input current
Final Gain: 0 - 4.1V Given it's an audio VCA this uses a lower cutoff: LPF @ 159 Hz
DAC: 4.096V Reference Voltage B grade spec'd, C, D grades of LM4040 are good 'nuff Programming: set to 1X gain, so DAC lines are 0 - 4.096V VREF load: 45k
CV to AS3364 VCA: Max gain at 2.08V (1.93 typ) LPF @ 1400 Hz
Decoupling caps close to pins
Gain inverting: 1.667 (DAC: 0 : -6.82V) Gain non-inverting: 1.0 (Vref: +4.096V) VCO_SUM_3394: DAC range +4.096 : -2.73 Modulation p-p can bring this >5V so add input protection


Board: 4 copper layers, 80.0 x 80.0 mm, 233 parts (0 on the bottom side), 164 nets.

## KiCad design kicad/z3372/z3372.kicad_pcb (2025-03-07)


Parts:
C10, C29, C31, C33, C35, C36, C37, C39: 0.1u; C_0603_1608Metric; LCSC C14663
C45: 1u; C_0805_2012Metric; LCSC C28323
D2: LED; LED_0603_1608Metric; LCSC C2286
H1, H2, H3, H4: MountingHole; MountingHole_3.2mm_M3
J1: Conn_01x01; PinHeader_1x01_P2.54mm_Vertical
J2: Conn_02x20_Odd_Even; PinHeader_2x20_P2.54mm_Horizontal
J3: Conn_01x02; PinHeader_1x02_P2.54mm_Vertical
Q3: MMBT3904; SOT-23; LCSC C20526
R18, R48: 51; R_0603_1608Metric; LCSC C23197
R19, R46, R47: 100k; R_0603_1608Metric; LCSC C25803
R45: 10k; R_0603_1608Metric; LCSC C25804
R53, R55, R56: 4k7; R_0603_1608Metric; LCSC C23162
TP10: TestPoint; TestPoint_Pad_2.0x2.0mm
U7, U10: MUX508; SOIC-16_3.9x9.9mm_P1.27mm; LCSC C2673104
U8: TL072; SOIC-8_3.9x4.9mm_P1.27mm; LCSC C6961
U11: CAT9555YI-T2; TSSOP-24_4.4x7.8mm_P0.65mm; LCSC C83265
U13: M24C02-WMN; SOIC-8_3.9x4.9mm_P1.27mm; LCSC C7562
U14: LM4040AIM3-2.5; SOT-23; LCSC C460725
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

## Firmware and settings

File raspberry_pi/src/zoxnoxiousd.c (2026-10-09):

/* Copyright 2023 Kyle Farrell
 *
 * Licensed under the Apache License, Version 2.0 (the "License"); you
 * may not use this file except in compliance with the License.  You may
 * obtain a copy of the License at
 *
 *  http://www.apache.org/licenses/LICENSE-2.0
 *
 * Unless required by applicable law or agreed to in writing, software
 * distributed under the License is distributed on an "AS IS" BASIS,
 * WITHOUT WARRANTIES OR CONDITIONS OF ANY KIND, either express or implied.
 * See the License for the specific language governing permissions and
 * limitations under the License.
 */

/* main file for zoxnoxiousd server application.  Handle basic setup of components,
 * init, get things going.
 * run it something like this with LD_LIBRARY_PATH set to /usr/local/zoxnoxiousd/lib
 * sudo env LD_LIBRARY_PATH=$LD_LIBRARY_PATH chrt -f 40 ./zoxnoxiousd -i /home/kaf/git/zoxnoxious/raspberry_pi/etc/zoxnoxiousd.cfg
 */

#include <alsa/asoundlib.h>
#include <errno.h>
#include <getopt.h>
#include <inttypes.h>
#include <limits.h>
#include <pigpio.h>
#include <poll.h>
#include <signal.h>
#include <stdio.h>
#include <stdint.h>
#include <stdlib.h>
#include <string.h>
#include <sys/mman.h>
#include <sys/time.h>
#include <sys/types.h>
#include <sys/timerfd.h>
#include <sys/wait.h>
#include <time.h>
#include <unistd.h>
#include <zlog.h>

#include "zoxnoxiousd.h"
#include "tune_mgr.h"
#include "card_manager.h"
#include "zalsa.h"
#include "zcard_plugin.h"


// stats for deadline events: track when a deadline was completely missed.
// these are only counted during valid real-time operations.
struct deadline_stats {
  uint64_t on_time_events;
  uint64_t missed_events;
  uint64_t total_missed_deadlines;
  uint64_t max_missed_deadlines;
};

// track period timing.  Distribution here shows how much jitter in scheduling.
#define PERIOD_HIST_ERROR_US 20
#define PERIOD_HIST_BINS (PERIOD_HIST_ERROR_US * 2 + 1)
struct timer_period_stats {
  uint64_t count;
  uint64_t sum_us;

  uint32_t min_us;
  uint32_t max_us;

  uint64_t below_range;
  uint64_t histogram[PERIOD_HIST_BINS];
  uint64_t above_range;
};


#define DISCOVERY_REPORT_SIZE_BYTES 28

#define MAX_SPI_WRITE_STATS 96
struct duration_stats {
  _Atomic uint32_t count;
  _Atomic uint64_t sum_us;
  _Atomic uint32_t min_us;
  _Atomic uint32_t max_us;
};
static struct duration_stats spi_active_time_by_spi_writes[MAX_SPI_WRITE_STATS] = { [0 ... MAX_SPI_WRITE_STATS - 1] = (struct duration_stats) { 0, 0, UINT32_MAX, 0} };
static struct duration_stats slack_time_by_spi_writes[MAX_SPI_WRITE_STATS] = { [0 ... MAX_SPI_WRITE_STATS - 1] = (struct duration_stats) { 0, 0, UINT32_MAX, 0} };
static struct duration_stats alsa_read_time_by_spi_writes[MAX_SPI_WRITE_STATS] = { [0 ... MAX_SPI_WRITE_STATS - 1] = (struct duration_stats) { 0, 0, UINT32_MAX, 0} };

// midi thread polls with a timeout to check for thread termination condition
#define MIDI_TIMEOUT_MS 10

/* globals-  mainly so they can be accessed by signal handler  */
static struct card_manager *card_mgr = NULL;
static struct alsa_pcm_state *pcm_state = NULL;
static snd_rawmidi_t *midi_in = NULL;
static snd_rawmidi_t *midi_out = NULL;
static pthread_mutex_t midi_out_mutex = PTHREAD_MUTEX_INITIALIZER;

static _Atomic int alsa_thread_run = 1;

static _Atomic int system_tune_requested = 0;
static _Atomic int system_tune_in_progress = 0;
static _Atomic int midi_request_shutdown = 0;
static _Atomic int midi_request_restart = 0;


// Signal handling: handlers just set flags and return
static volatile sig_atomic_t sig_cleanup_received = 0;
static volatile sig_atomic_t sig_dump_stats_received = 0;


// static functions
static void help();
static void sig_cleanup_and_exit(int signum);
static void sig_dump_stats(int signum);
static int open_midi_device(config_t *cfg);
static void* read_pcm_and_call_plugins(void *);
static void* midi_in_to_plugins(void *);
static void generate_discovery_report(uint8_t discovery_report_sysex[]);
static int z_midi_write(uint8_t *buffer, int buffer_size);
static int get_midi_input_fd();
static int start_pcm(struct alsa_pcm_state *pcm, int *err_var, const char *name);
static void add_duration_stat(struct duration_stats *stats, uint32_t new_timing);
static void report_duration_stats();
static void add_timer_period_stat(struct timer_period_stats *stats,
                                  uint32_t period_us, uint32_t nominal_period_us);
static void report_timer_period_stats(const struct timer_period_stats *stats, uint32_t nominal_period_us);
static void report_expiration_timing_stats(const struct deadline_stats *deadline_stats);


int main(int argc, char **argv, char **envp) {
  config_t *cfg;
  char *midi_device_name = NULL;
  char config_filename[128] = { '\0' };
  char *opt_string = "hi:v";
  pthread_t alsa_pcm_to_plugin_thread;
  pthread_t midi_in_plugin_thread;
  sigset_t signal_set;
  struct sigaction signal_action_cleanup, signal_action_stats;


  /* bookkeeping stuff before getting to the important stuff:
   * + libconf opened, available
   * + zlog enabled, logging
   * + pigpio init, can start talking to hardware
   * + load card plugins
   * + midi opened
   * + alsa init
   */


  struct option long_option[] = {
    {"help", no_argument, NULL, 'h'},
    {"config", required_argument, NULL, 'i'},
    {"verbose", required_argument, NULL, 'v'},
    {NULL, 0, NULL, 0},
  };


  // parse command line
  while (1) {
    int c;
    if ((c = getopt_long(argc, argv, opt_string, long_option, NULL)) < 0) {
      break;
    }
    switch (c) {
    case 'h':
      help();
      return 1;
    case 'i':
      strncpy(config_filename, optarg, sizeof(config_filename) - 1);
      config_filename[127] = '\0';
      break;
    default:
      printf("unknown option\n");
      help();
      return -1;
    }
  }


  // TODO: hardcoded directory
  if (zlog_init("/home/kaf/git/zoxnoxious/raspberry_pi/etc/log.cfg")) {
    printf("zlog_init failed");
    return -1;
  }

  zlog_c = zlog_get_category("zoxnoxious");
  if (!zlog_c) {
    printf("get zlog cat failed\n");
    zlog_fini();
    return -1;
  }


  if (config_filename[0] != '\0') {
    INFO("using config %s\n", config_filename);
  }
  else if (getenv(ZOXNOXIOUS_DIR_ENV_VAR_NAME) != NULL) {
    snprintf(config_filename, 128, "%s%s%s",
             getenv(ZOXNOXIOUS_DIR_ENV_VAR_NAME), CONFIG_DIRNAME, CONFIG_FILENAME);
  }
  else {
    snprintf(config_filename, 128, "%s%s%s",
             DEFAULT_ZOXNOXIOUS_DIRECTORY, CONFIG_DIRNAME, CONFIG_FILENAME);
  }

  printf("params:\n"
         "  config filename: %s\n"
         "  midi_device: %s\n",
         config_filename,
         midi_device_name ? midi_device_name : "(null)");


  cfg = (config_t*)malloc(sizeof(config_t));
  config_init(cfg);

  if (config_read_file(cfg, config_filename) == CONFIG_FALSE) {
    ERROR("config read failed to read file %s: %s (%d)", config_filename, config_error_text(cfg), config_error_type(cfg));
    return -1;
  }


  // SPI, pigpio start
#ifndef MOCK_DATA
  gpioCfgClock(4, 1, 1);
  if (gpioInitialise() < 0) {
    ERROR("gpioInitialise failed, bye!");
    return -1;
  }
  else {
    INFO("gpioInitialise complete");
  }
#endif

  // init alsa pcm devices
  pcm_state = alsa_open_device(cfg, 0);
  if (pcm_state == NULL) {
    ERROR("fail to open PCM device");
    abort();
  }

  INFO("pcm initialized for %s", pcm_state->device_name);

  // init alsa midi device
  if (open_midi_device(cfg) != 0) {
    ERROR("fail to open MIDI device");
    abort();
  }

  
  // detect installed cards- get the card manager going
  int num_hw_channels = pcm_state->channels;
  card_mgr = init_card_manager(cfg);
  discover_cards(card_mgr);
  load_card_plugins(card_mgr);
  assign_update_order(card_mgr);
  assign_hw_audio_channels(card_mgr, &num_hw_channels, 1);

  struct zhost *zhost;
  if ( (zhost = zhost_create()) == NULL) {
    FATAL("zhost_create failed");
    abort();
  }

  // init all the plugin cards
  for (int card_num = 0; card_num < card_mgr->num_cards; ++card_num) {
    // alias
    struct plugin_card *this_card = card_mgr->card_update_order[card_num];
    // the index isn't the slot num-- but we can look it up on the card
    INFO("init card slot %d", card_mgr->cards[card_num].slot);
    this_card->plugin_object =
      (this_card->init_zcard)(zhost, card_mgr->cards[card_num].slot);
    if (this_card->plugin_object == NULL) {
      WARN("plugin card slot %d returned NULL for init", card_mgr->cards[card_num].slot);
    }
  }


  // lock memory to prevent swapping.  Must run as root for this to work (pigpio already has this requirement).
  // This may be of dubious value: the amount of memory available is pretty huge and swap isn't ever used.
  if (mlockall(MCL_CURRENT | MCL_FUTURE) == -1) {
    char error[256];
    strerror_r(errno, error, 256);
    ERROR("mlockall failed: %s. Continuing without memory locking.", error);
  }
  else {
    INFO("Successfully locked memory into main memory");
  }


  sigemptyset(&signal_set);
  sigaddset(&signal_set, SIGUSR1);
  sigaddset(&signal_set, SIGHUP);
  sigaddset(&signal_set, SIGINT);
  sigaddset(&signal_set, SIGTERM);
  pthread_sigmask(SIG_BLOCK, &signal_set, NULL);


  // cpu tune request for all cards:
  // this isn't done at startup so one can tweak trimmers before autotuning.
  // future: give user option via frontend to use linear or corrected tables.
  //autotune_all_cards(card_mgr);

  // start threads
  if ( pthread_create(&alsa_pcm_to_plugin_thread, NULL, read_pcm_and_call_plugins, NULL) ) {
    ERROR("failed to start thread for read_pcm_and_call_plugins");
    abort();
  }

  if ( pthread_create(&midi_in_plugin_thread, NULL, midi_in_to_plugins, NULL) ) {
    ERROR("failed to start thread for midi_in_to_plugins");
    abort();
  }


  // setup signal handling
  signal_action_cleanup.sa_handler = sig_cleanup_and_exit;
  sigaction(SIGHUP, &signal_action_cleanup, NULL);
  sigaction(SIGINT, &signal_action_cleanup, NULL);
  sigaction(SIGTERM, &signal_action_cleanup, NULL);

  signal_action_stats.sa_handler = sig_dump_stats;
  sigaction(SIGUSR1, &signal_action_stats, NULL);

  // main loop thread: check if we need to respond to signals, sleep, loop
  while (alsa_thread_run) {
    if (sig_cleanup_received) {
      INFO("Signal received, initiating shutdown...");
      alsa_thread_run = 0; // Signal worker threads to exit

      if (munlockall() == -1) {
        char error[256];
        strerror_r(errno, error, 256);
        ERROR("munlockall failed in main loop: %s", error);
      } else {
        INFO("Memory unlocked in main loop.");
      }
      sig_cleanup_received = 0; // reset - best practice
      break;
    }

    if (sig_dump_stats_received) {
      sig_dump_stats_received = 0;
      report_duration_stats();
    }

    sleep(1);
  }


  int retval;
  pthread_join(alsa_pcm_to_plugin_thread, (void**)&retval);
  pthread_join(midi_in_plugin_thread, (void**)&retval);

  // safest time to dump stats after threads have joined
  report_duration_stats();

  // close pcm handles
  alsa_pcm_close(pcm_state);

  if (midi_in) {
    snd_rawmidi_close(midi_in);
  }
  if (midi_out) {
    snd_rawmidi_drain(midi_out);
    snd_rawmidi_close(midi_out);
  }

  // card mgr closes all plugins
  if (card_mgr) {
    free_card_manager(card_mgr);
  }

  gpioTerminate();


  // Unlock memory before exiting
  if (munlockall() == -1) {
    char error[256];
    strerror_r(errno, error, 256);
    ERROR("munlockall failed: %s", error);
  } else {
    INFO("Successfully unlocked memory");
  }

  // fall through to exit
  zlog_fini();
  config_destroy(cfg);
  free(cfg);

  // are we here 'cause we were asked to shutdown or restart?
  if (midi_request_shutdown) {
    execl("/sbin/poweroff", "--poweroff", (char*)NULL);
    perror("execl failed, system not shutdown");
  }
  else if (midi_request_restart) {
    execl("/sbin/reboot", "--reboot", (char*)NULL);
    perror("execl failed, system not restarted");
  }

  return 0;
}




static void help() {
  printf("Usage: zoxnoxiousd <options>\n"
         "  -i <config_file>\n");
}



void sig_cleanup_and_exit(int signum) {
  sig_cleanup_received = 1;
}
static void sig_dump_stats(int signum) {
  sig_dump_stats_received = 1;
}


static int open_midi_device(config_t *cfg) {
  const char *midi_device_name;
  config_setting_t *midi_device_setting = config_lookup(cfg, MIDI_DEVICE_KEY);

  if (midi_device_setting == NULL) {
    ERROR("cfg: no midi config value found for " MIDI_DEVICE_KEY);
    return 1;
  }

  midi_device_name = config_setting_get_string(midi_device_setting);

  if (midi_device_name == NULL) {
    ERROR("cfg: device name null for key " MIDI_DEVICE_KEY);
    return 1;
  }


  if (snd_rawmidi_open(&midi_in, &midi_out, midi_device_name, SND_RAWMIDI_NONBLOCK) != 0) {
    ERROR("failed to open midi device %s", midi_device_name);
    return 1;
  }

  INFO("successfully opened midi device %s", midi_device_name);
  return 0;
}


// start timer
// start alsa stream
// forever:
// do {
//   call each plugin on stream 1
//   sleep til timer fires
//   advance alsa cursor
// } while (running flag)

static void* read_pcm_and_call_plugins(void *arg) {
  int timerfd_sample_clock = -1;
  int frames_to_advance;

  // do a couple things:
  // compute timer dynamically... but this was initially designed
  // for 4khz.  And two PCM streams.  Now it's 8khz and a single PCM stream.
  // Maintaining the code for two PCM streams for the time being.
  // Which assumes both streams are on the same clock.
  struct itimerspec itimerspec_sample_clock = {
    .it_interval.tv_sec = 0,
    .it_interval.tv_nsec = 1000000000 / pcm_state->sampling_rate,
    .it_value.tv_sec = 0,
    .it_value.tv_nsec = 1000000000 / pcm_state->sampling_rate,
  };
  const uint32_t nominal_period_us = itimerspec_sample_clock.it_interval.tv_nsec / 1000;

  struct timer_period_stats period_stats = {
    .count = 0,
    .sum_us = 0,
    .min_us = UINT32_MAX,
    .max_us = 0,
  };
  struct deadline_stats deadline_stats = { 0 };


  if ( (timerfd_sample_clock = timerfd_create(CLOCK_MONOTONIC, 0)) == -1) {
    char error[256];
    strerror_r(errno, error, 256);
    ERROR("failed to create sample clock timer: %s", error);
  }

  INFO("starting timer %ld usec for sampling rate %d hz",
       itimerspec_sample_clock.it_interval.tv_nsec / 1000,
       pcm_state->sampling_rate);
  // logging from here forward may be tricky / time sensitive

  int err_pcm0 = -EAGAIN;
  while (alsa_thread_run && err_pcm0 == -EAGAIN) {
    if (start_pcm(pcm_state, &err_pcm0, "pcm0")) {
      break;
    }

    if (err_pcm0 == -EAGAIN) {
      usleep(1000); // 1 millisecond, don't get greedy and keep it too busy
    }
  }

  if (err_pcm0) {
    alsa_thread_run = 0;
  }

  // PCM stream should be good now

  if ( (timerfd_settime(timerfd_sample_clock, 0, &itimerspec_sample_clock, 0) ) == -1) {
    char error[256];
    strerror_r(errno, error, 256);
    ERROR("failed to start timer: %s", error);
  }

  // ignore first timing sample
  int valid_timing_sample = 0;
  uint32_t card_processing_start_us = gpioTick();
  uint32_t wait_start_us;
  uint32_t timer_read_return_us;
  uint32_t prev_timer_read_return_us = 0;
  int have_prev_timer_read_return = 0;

  // Business Section
  while (alsa_thread_run) {
    int spi_writes = 0;

    if (!err_pcm0) {
      for (int card_num = 0; card_num < card_mgr->num_cards; ++card_num) {
        // alias for the deeply nested structure to the plugin card / readability
        struct plugin_card *plugin_card = card_mgr->card_update_order[card_num];
        int channel_offset = plugin_card->channel_offset;

        // the samples relevant for this card are at the channel offset on the approp pcm device
        const int16_t *samples = alsa_pcm_cursor_sample(pcm_state, channel_offset);

        // then call the card's plugin with the samples via function pointer
        // track the total number of spi writes done by the voice cards
        spi_writes += (plugin_card->process_samples)(plugin_card->plugin_object, samples);
      }

      if (spi_writes > MAX_SPI_WRITE_STATS - 1) {
        spi_writes = MAX_SPI_WRITE_STATS - 1;
      }
      else if (spi_writes < 0) {
        spi_writes = 0;
      }
    }

    // card processing done, start the clock on waiting
    wait_start_us = gpioTick();

    // delay (slack time) until the next timer interval
    ssize_t ret;
    uint64_t expirations = 0;
    do {
      ret = read(timerfd_sample_clock, &expirations, sizeof(expirations));
    } while (ret < 0 && errno == EINTR);

    timer_read_return_us = gpioTick();

    if (ret != sizeof(expirations) || expirations == 0) {
      // timer read failed unexpectedly.  Advance one frame to keep
      // the stream moving, but don't include this cycle in timing stats.
      frames_to_advance = 1;
      valid_timing_sample = 0;
    }
    else {
      frames_to_advance = expirations > INT_MAX ? INT_MAX : (int)expirations;
    }


    // get new set of frames or advance sample pointers
    err_pcm0 = alsa_pcm_advance_cursor(pcm_state, frames_to_advance);
    if (err_pcm0 && err_pcm0 != -EAGAIN) {
      INFO("pcm0: alsa_pcm_advance_cursor: %d", err_pcm0);
    }

    uint32_t next_card_processing_start_us = gpioTick();

    // check for a tune request.  Tuning is offline: system will not
    // be responsive during the autotune.
    if (system_tune_requested) {
      system_tune_in_progress = 1;
      autotune_all_cards(card_mgr);
      system_tune_in_progress = 0;
      system_tune_requested = 0;
      valid_timing_sample = 0;
      have_prev_timer_read_return = 0;
    }
    else {
      if (valid_timing_sample) {
        add_duration_stat(&spi_active_time_by_spi_writes[spi_writes], wait_start_us - card_processing_start_us);
        add_duration_stat(&slack_time_by_spi_writes[spi_writes], timer_read_return_us - wait_start_us);
        add_duration_stat(&alsa_read_time_by_spi_writes[spi_writes], next_card_processing_start_us - timer_read_return_us);

        if (expirations == 1) {
          deadline_stats.on_time_events++;

          // histogram of should only store consecutive valid timer
          // reads for which exactly one expiration occurred in both cycles
          if (have_prev_timer_read_return) {
            uint32_t period_us = timer_read_return_us - prev_timer_read_return_us;
            add_timer_period_stat(&period_stats, period_us, nominal_period_us);
          }

          prev_timer_read_return_us = timer_read_return_us;
          have_prev_timer_read_return = 1;
        }
        else {
          uint64_t num_missed_deadlines = expirations - 1;
          deadline_stats.missed_events++;
          deadline_stats.total_missed_deadlines += num_missed_deadlines;
          if (deadline_stats.max_missed_deadlines < num_missed_deadlines) {
            deadline_stats.max_missed_deadlines = num_missed_deadlines;
          }
          have_prev_timer_read_return = 0;
        }
      }
      else {
        valid_timing_sample = 1;
      }
    }

    card_processing_start_us = next_card_processing_start_us;
  }

  if (timerfd_sample_clock != -1) {
    close(timerfd_sample_clock);
  }

  report_timer_period_stats(&period_stats, nominal_period_us);
  report_expiration_timing_stats(&deadline_stats);
  INFO("Exiting PCM Audio thread.");
  return NULL;
}



// Stuff for midi_in_to_plugins.  Parse the midi stream and determine what to send to the cards.

// this is all the first nibble stuff- 0xFx stuff is more complex, but it's to be ignored
enum midi_status_byte {
  MIDI_STATUS_NOT_SET = 0x00,
  MIDI_NOTE_OFF = 0x80,
  MIDI_NOTE_ON = 0x90,
  MIDI_KEY_PRESSURE = 0xA0,
  MIDI_CONTROLLER_CHANGE = 0xB0,
  MIDI_PROGRAM_CHANGE = 0xC0,
  MIDI_CHANNEL_PRESSURE = 0xD0,
  MIDI_PITCH_BEND = 0xE0,
  MIDI_SYSEX_START = 0xF0,
  MIDI_TUNE_REQUEST = 0xF6,
  MIDI_SYSEX_END = 0xF7
};

enum sysex_message_type {
  TYPE_UNSET = 0,
  DISCOVERY_RESPONSE = 0x01,
  DISCOVERY_REQUEST = 0x02,
  SHUTDOWN_REQUEST = 0x03,
  RESTART_REQUEST = 0x04,
  VALID_MANUFACTURER_ID = 0x7D
};

struct midi_state {
  enum midi_status_byte status;
  uint8_t channel;
  enum sysex_message_type sysex_message_type;
  int sysex_buffer_size;
  uint8_t sysex_buffer[32];
};

// Discovered card number maps to MIDI channel number.  Not actual slot number.


/* get_midi_input_fd gets the midi file descriptor such that it can be polled for input
 * Return <0 on error.
 */
static int get_midi_input_fd() {
  int midi_fd = -1;
  int num_descriptors = snd_rawmidi_poll_descriptors_count(midi_in);

  if (num_descriptors <= 0) {
    ERROR("Error: No poll descriptors available for MIDI input.");
    return -1;
  }

  // initialization only- I'll allow for calloc here
  struct pollfd *pfds = calloc(num_descriptors, sizeof(struct pollfd));
  if (!pfds) {
    ERROR("Error allocating memory for MIDI poll descriptors");
    return -1; // Indicate error
  }

  if (snd_rawmidi_poll_descriptors(midi_in, pfds, num_descriptors) > 0) {
    // Assuming only one readable descriptor for MIDI input
    for (int i = 0; i < num_descriptors; ++i) {
      if (pfds[i].events & POLLIN) {
        midi_fd = pfds[i].fd;
        break;
      }
    }
    if (midi_fd == -1) {
      ERROR("Error: Could not find a readable MIDI input descriptor");
    }
  }
  else {
    ERROR("Error: Failed to get MIDI poll descriptors: %s", snd_strerror(snd_rawmidi_poll_descriptors(midi_in, pfds, num_descriptors)));
  }

  free(pfds);
  return midi_fd;
}
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

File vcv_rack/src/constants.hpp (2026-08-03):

#pragma once
#include <string>
#include "plugin.hpp"

namespace zox {
  
// maximum number of channels on a USB Audio interface
static constexpr int8_t maxAudioChannels = 72;
static constexpr int8_t maxAudioDevices = 1;
static constexpr int maxVoiceCards = 6;

static constexpr int8_t invalidSlot = -1;
static constexpr int8_t invalidOutputDeviceId = -1;
static constexpr int8_t invalidCvChannelOffset = -1;
static constexpr int8_t invalidMidiChannel = -1;
static constexpr uint8_t invalidCardId = 0;
static constexpr int invalidPrimaryDepth = -1;

static const std::string invalidCardOutputName = "----";

static constexpr uint8_t midiProgramChangeStatus = 0xC;

// for pole mixing modules
static constexpr float POLEMIX_VOLTAGE_SCALE = 10.0f / 8.f;

// this doesn't have a really good home other than here
inline void setMidiProgramChangeMessage(rack::midi::Message& midiOutMessage, int8_t midiChannel, int8_t program) {
  midiOutMessage.setSize(2);
  midiOutMessage.setChannel(midiChannel);
  midiOutMessage.setStatus(midiProgramChangeStatus);
  midiOutMessage.setNote(program);
}


}

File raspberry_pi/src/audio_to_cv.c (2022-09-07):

/* 
 * audio_to_cv
 * Compile:
 * gcc -Wall -o audio_to_cv audio_to_cv.c -lasound -lpigpio
 * Run:
 * sudo audio_to_cv -d hw:CARD=UAC2Gadget,DEV=0 -m hw:1,0
 *
 * a Makefile and additional functionality will be useful.
 * Right now this just listens for incoming audio and maps the first
 * six channels to board-specific DAC channels via SPI along with
 * mapping midi program changes to I2C commands.
 *
 *  Portions may be copyright (c) by Jaroslav Kysela <perex@perex.cz>
 *  lifted from aplay.c
 */

#include <alsa/asoundlib.h>
#include <getopt.h>
#include <pigpio.h>
#include <signal.h>
#include <stdint.h>
#include <stdio.h>
#include <sys/ioctl.h>
#include <sys/time.h>
#include <sys/timerfd.h>
#include <unistd.h>




struct alsa_pcm_state {
  snd_pcm_t *pcm_handle;
  unsigned int sampling_rate;
  snd_pcm_sframes_t period_size;  // Size to request on read()
  snd_pcm_uframes_t buffer_size;  // size of ALSA buffer (in frames)
  snd_pcm_format_t format;        // audiobuf format
  unsigned int channels;          // number of channels
  int first_period;               // boolean cleared after first frame processed, set after xrun

  int timerfd_sample_clock;
  struct itimerspec itimerspec_sample_clock;
  int timer_running;

  int16_t previous_sample[32];
};

struct midi_state {
  int next_byte_is_program; // horrid midi stream parser for now, only id program changes
};

struct i2c_gpio_state {
  uint8_t output_state[2];
};



// map the incoming PCM channel to a DAC channel.  The DAC has 6 of 8
// channels wired up as follows, some no connects in the middle.  Map
// these to provide a contiguous interface to the PCM channels.
// 0 freq CV
// 1 Hard Sync level
// 2 no connect
// 3 PWM
// 4 Triangle VCA amount
// 5 Osc Ext VCA amount
// 6 no connect
// 7 Linear FM
static const int pcm_channel_to_dac_channel_map[] = { 0, 1, 3, 4, 5, 7 };

static int alsa_init(struct alsa_pcm_state *pcm_state, char *device);
static int alsa_pcm_read_spi_write(struct alsa_pcm_state *pcm_state, int spi_handle);
static int alsa_pcm_ensure_ready(struct alsa_pcm_state *pcm_state);
static void help();
static int xrun_recovery(struct alsa_pcm_state *pcm_state, int err); 

static void alsa_midi_in_to_i2c(int i2c_handle, struct i2c_gpio_state *gpio_state, snd_rawmidi_t *midi_in, struct midi_state *midi_state);
static void set_midi_program(int i2c_handle, struct i2c_gpio_state *gpio_state, uint8_t program);


// global 'cause these handles are needed for signal handling
static struct alsa_pcm_state pcm_state = { 0 };
static snd_rawmidi_t *midi_in = NULL;
static int spi_handle = 0;
static int i2c_handle = 0;
static volatile sig_atomic_t in_aborting = 0;

// ok use globals here.  civility be damned.
static int xrun_recovery_count = 0;
static int frames_dropped = 0;
static int verbose = 0;

static void signal_handler(int sig) {
  if (in_aborting) {
    return;
  }

  in_aborting = 1;
  if (pcm_state.pcm_handle) {
    snd_pcm_abort(pcm_state.pcm_handle);
    snd_pcm_close(pcm_state.pcm_handle);
  }

  printf("close pcm\n");

  if (midi_in) {
    snd_rawmidi_close(midi_in);
    midi_in  = NULL;
  }

  printf("close midi\n");

  if (spi_handle) {
    spiClose(spi_handle);
  }

  if (i2c_handle) {
    i2cClose(i2c_handle);
  }

  printf("closed i2c\n");

  gpioTerminate();

  if (pcm_state.timerfd_sample_clock) {
    close(pcm_state.timerfd_sample_clock);
  }

  if (sig == SIGABRT) {
    /* do not call snd_pcm_close() and abort immediately */
    pcm_state.pcm_handle = NULL;
    exit(EXIT_FAILURE);
  }

  printf("frames dropped: %d; xrun_recovery_count: %d\n",
         frames_dropped, xrun_recovery_count);
  signal(sig, SIG_DFL);
  exit(1);
}



int main (int argc, char *argv[]) {
  struct midi_state midi_state = { 0 };
  char *midi_device = "hw:1,0";
  int err;
  char *device = "plughw:0,0";
  const int spi_rate = 20000000;
  struct i2c_gpio_state gpio_state = { .output_state = { 0x00, 0x20 } };

  struct option long_option[] = {
    {"help", no_argument, NULL, 'h'},
    {"device", required_argument, NULL, 'd'},
    {"rate", required_argument, NULL, 'r'},
    {"channels", required_argument, NULL, 'c'},
    {"buffer", required_argument, NULL, 'b'},
    {"period", required_argument, NULL, 'p'},
    {"mididevice", required_argument, NULL, 'm'},
    {"verbose", required_argument, NULL, 'v'},
    {NULL, 0, NULL, 0},
  };

  char *opt_string = "hd:r:c:b:p:m:v";

  pcm_state = (struct alsa_pcm_state const) {
    .sampling_rate = 4000,
    .period_size = 32,
    .buffer_size = 64,
    .format = SND_PCM_FORMAT_S16_LE,
    .channels = 8,
    .first_period = 1,
    .timerfd_sample_clock = timerfd_create(CLOCK_MONOTONIC, 0),
    .itimerspec_sample_clock =
      {
        .it_interval.tv_sec = 0,
        .it_interval.tv_nsec = 1000000000 / 4000,
        .it_value.tv_sec = 0,
        .it_value.tv_nsec = 1000000000 / 4000
      },
    .timer_running = 0,
    .previous_sample = { 0 }
  };


  while (1) {
    int c;
    if ((c = getopt_long(argc, argv, opt_string, long_option, NULL)) < 0)
      break;
    switch (c) {
    case 'h':
      help();
      return 1;
    case 'd':
      device = strdup(optarg);
      break;
    case 'r':
      pcm_state.sampling_rate = atoi(optarg);
      pcm_state.sampling_rate = pcm_state.sampling_rate < 4000 ? 4000 : pcm_state.sampling_rate;
      pcm_state.sampling_rate = pcm_state.sampling_rate > 196000 ? 196000 : pcm_state.sampling_rate;
      break;
    case 'c':
      pcm_state.channels = atoi(optarg);
      pcm_state.channels = pcm_state.channels < 1 ? 1 : pcm_state.channels;
      pcm_state.channels = pcm_state.channels > 1024 ? 1024 : pcm_state.channels;
      break;
    case 'b':
      pcm_state.buffer_size = atoi(optarg);
      pcm_state.buffer_size = pcm_state.buffer_size < 2 ? 2 : pcm_state.buffer_size;
      pcm_state.buffer_size = pcm_state.buffer_size > 1024 ? 1024 : pcm_state.buffer_size;
      break;
    case 'p':
      pcm_state.period_size = atoi(optarg);
      pcm_state.period_size = pcm_state.period_size < 2 ? 2 : pcm_state.period_size;
      pcm_state.period_size = pcm_state.period_size > 2048 ? 2048 : pcm_state.period_size;
      break;
    case 'm':
      midi_device = strdup(optarg);
      break;
    case 'v':
      verbose = 1;
      break;
    }
  }


  signal(SIGHUP, signal_handler);
  signal(SIGINT, signal_handler);
  signal(SIGTERM, signal_handler);
  signal(SIGABRT, signal_handler);


  printf("device: %s mididevice: %s\n", device, midi_device);


  // ALSA AUDIO AND MIDI INITIALIZE - create handles
  err = alsa_init(&pcm_state, device);
  if (err != 0) {
    fprintf(stderr, "alsa init failed\n");
    exit(err);
  }

  err = snd_rawmidi_open(&midi_in, NULL, midi_device, SND_RAWMIDI_NONBLOCK);
  if (err != 0) {
    fprintf(stderr, "alsa midi open failed\n");
    exit(err);
  }


  // END ALSA INIT
  // PIGPIO INIT
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

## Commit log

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2022-05-13 Adding the "v0.2" version of the board. Despite it's many faults it is manufactured and is what sits on the testbench today.
    [as3340-BOM.csv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]
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2022-05-18 fixed annoying signed int right shift bug fix program change bug
    [audio_to_cv.c]
2022-05-20 lights added for clipping; fix linear voltage parameter
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2022-05-21 rename directory- be more concrete on what it is
    [as3340-BOM.csv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]
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2022-06-08 rework output stage
    [as3340.kicad_pcb, cem3340.sch, output_mix.sch]
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2022-08-05 fix library dependency
    [output_select.sch, vca_backplane.kicad_pcb]
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2022-08-07 add missing components after library fix
    [vca_backplane.kicad_pcb]
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2022-08-23 really fix the kicad lib
    [output_select.sch]
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2022-08-25 fix some poor routing
    [output_select.kicad_sch, vca_backplane.kicad_pcb, vca_backplane.kicad_sch]
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2022-08-29 kicad library fix...again
    [as3340.kicad_sch, cem3340.kicad_sch, dac.kicad_sch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]
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2022-09-08 fixes for BOM
    [as3340.kicad_sch, cem3340.kicad_sch, dac.kicad_sch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]
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2022-09-22 vcv: move audio/midi from 3340to patchingmatrix. kicad: add missing footprint
    [AudioMidi.hpp]
2022-09-29 working on the param knob and level inputs to clip led- not working just yet
2022-10-10 fix a big- expander code is getting complicated with string handling
    [Zoxnoxious3340.cpp]
2022-10-11 fix midi messages for 3340 board; add names to audio out
    [Zoxnoxious3340.cpp]
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2022-10-23 stabilize a bit
    [zoxnoxiousd.cfg]
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2022-11-02 move samples pointer by num expirations for error handling of timer
    [zoxnoxiousd.c]
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2022-11-02 fix frame bug
2022-11-03 signal handling a bit better (still ugly); try to write real SPI data
    [zoxnoxiousd.cfg]
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2022-11-22 change DAC Freq CV to 0-6.5V; add lowpass caps on DAC lines; fix SOT-23 pinout
    [as3340.kicad_pcb, as3340.kicad_sch, cem3340.kicad_sch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]
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2022-11-27 create kicad template and start an as3372 project
    [as3372.kicad_pcb, as3372.kicad_sch, dac.kicad_sch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]
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2022-12-06 midi out from pi corrected
    [card_manager.c, zoxnoxiousd.c]
2022-12-07 fix AudioOut sending bad midi channels. Add save/restore of audio and midi devices
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2022-12-11 bug fix- figured out why slots 1,3,4 did not work. MSB is a thing
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2022-12-23 fix opamp orientation
    [filter_as3372.kicad_sch]
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2023-01-06 having a tough time routing full filter with modes
    [as3372.kicad_pcb, as3372.kicad_sch, filter_as3372.kicad_sch]
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2023-01-10 add white noise enable/powerdown
    [as3372.kicad_pcb, as3372.kicad_sch, dac.kicad_sch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]
2023-01-11 AS3372 cut to production. Another review would be good but wanted to get it in before Chinese New Year
    [as3372-BOM.csv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]
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2023-01-28 fix LEDs; add noise input level jack
2023-01-28 fix midi message to i2c mapping 3372
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2023-04-11 output levels changed and other fixes
    [as3340.kicad_sch, cem3340.kicad_sch, output_mix.kicad_sch]
2023-04-18 changed output scaling; CV freq range; removed comp output
    [as3340.kicad_pcb, as3340.kicad_sch, cem3340.kicad_sch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]
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2023-05-11 most of 3394 drafted, working on 2130 dac lines
    [as3394.kicad_sch, dac_2130.kicad_sch, dac_3394.kicad_sch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]
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2023-05-25 add missing sheets
    [mod_vca.kicad_sch, ssi2130.kicad_sch]
2023-05-25 calc Vref resistors and fix a couple errors
    [dac_2130.kicad_sch, dac_3394.kicad_sch, ssi2130.kicad_sch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]
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2023-06-04 routing coming together...in a bit of a mess
    [dac_2130.kicad_sch, ssi2130.kicad_sch, z5524.kicad_pcb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]
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2023-06-08 silkscreen updates, offgrid resolved
    [as3394.kicad_sch, dac_2130.kicad_sch, dac_3394.kicad_sch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]
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2023-06-10 update LCSC Part numbers, some modification to account for parts
    [as3394.kicad_sch, dac_2130.kicad_sch, dac_3394.kicad_sch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]
2023-06-11 add a few more test points, silkscreen updates, odds and ends
    [as3394.kicad_sch, z5524.kicad_pcb, z5524.kicad_sch]
2023-06-11 fix symbol library
    [as3394.kicad_sch, dac_2130.kicad_sch, dac_3394.kicad_sch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]
2023-06-13 update footprint for polarized caps, misc touch ups
    [ssi2130.kicad_sch, z5524.kicad_pcb, z5524.kicad_sch]
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2023-06-16 swap R value for FM input, about final touches before RTM
    [dac_3394.kicad_sch, ssi2130.kicad_sch, z5524.kicad_pcb]
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2023-07-12 revert z3372 back to spi channel 0
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2023-08-01 bugfix SPI chip select for z5524
    [zoxnoxiousd.cfg]
2023-08-25 fix: (1) VCO range CV 3394 (2) VCF range 3394 CV (3) mix input 2130 (4) FM MOSFET orientation 2130
    [dac_2130.kicad_sch, dac_3394.kicad_sch, ssi2130.kicad_sch]
2023-08-26 fix waveselect issue with a summing opamp. Rework potentiometer face headings
    [as3394.kicad_sch, dac_3394.kicad_sch, ssi2130.kicad_sch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]
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2023-08-29 minor rework
    [as3394.kicad_sch, dac_3394.kicad_sch, ssi2130.kicad_sch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]
2023-08-30 fix BOM for current JLC catalog
    [z5524.kicad_pcb, z5524.kicad_sch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]
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2023-08-31 trying to move ROM up a mm or two
    [z5524-BOM.csv, z5524.kicad_pcb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]
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2023-09-07 usbaudio update for the Raspberry Pi side of things
    [zoxnoxiousd.cfg]
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2023-09-18 trying slew rate limit on single transistor noise VCA Z3372 board
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2023-10-05 z3340 measures freq- looks correct
    [autotune.c]
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2023-10-16 init DAC previous_samples to non-valid value, force updates on first samples. Fix 5524 tri/on/off
2023-10-23 clamp PWM on 5524 by 3% each way. Short term hack.
2023-10-24 scale pwm on 5524 a bit better. short term solution
2023-10-25 fix range on z3340 autotune; add z5524 tune setup; include delay in manager after set; split 5524 tune from main processing
    [autotune.c]
2023-10-25 rename files, fix compiler warning
    [tune_mgr.c, zoxnoxiousd.c]
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2023-10-25 recording of tune data for z5524; next is the correction table
    [tune_mgr.c]
2023-10-26 fix some autotune bugs: MIDI messages will queue, DAC state invalidated, I2C restored
    [zoxnoxiousd.c]
2023-10-26 finally: frontend user can reboot or shutdown the pi via MIDI command
    [zoxnoxiousd.c]
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2023-11-24 updated 3394 --> 2130 FM to much deeper. Started addressing PWM range for increased modulation
    [as3394.kicad_sch, dac_2130.kicad_sch, ssi2130.kicad_sch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]
2023-11-29 fix 2130 exp pitch input and save an opamp
    [as3394.kicad_sch, dac_2130.kicad_sch, dac_3394.kicad_sch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]
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2023-12-06 schematic updates- cv values from dac and input protections between VCOs
    [as3394.kicad_sch, dac_2130.kicad_sch, dac_3394.kicad_sch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]
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2023-12-11 dist ref cap to two 1u instead of single; some more silkscreen cleanup
    [as3394.kicad_sch, dac_2130.kicad_sch, dac_3394.kicad_sch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]
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2023-12-28 update Rack module for v0.3 PWM being inverted
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2024-03-23 fix comment
    [config.txt]
2024-06-06 working through 3340 changes. Added sync circuits, DAC scaling changes, 16:1 multiplexor
    [as3340.kicad_pcb, as3340.kicad_sch, cem3340.kicad_sch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]
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2024-06-16 placement about as good as it'll get, time to try and route this thing
    [as3340.kicad_pcb, as3340.kicad_sch, output_mix.kicad_sch]
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2024-06-30 fix board IDs
2024-06-30 fix 3340 IDs
    [zoxnoxiousd.cfg]
2024-06-30 swap channels: sync and osc
    [Zoxnoxious3340.cpp]
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2024-09-19 update pdf schematic with v0.4 for Z3372. Update all title blocks in Z3372. V0.4 done.
    [dac.kicad_sch, filter_as3372.kicad_sch, z3372.kicad_pcb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]
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2024-10-03 updated routing and prep for z5524 revision rev. Power routing going from polygons to direct
    [as3394.kicad_sch, dac_2130.kicad_sch, dac_3394.kicad_sch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]
2024-10-04 fix soft sync. tweak routing
    [as3394.kicad_sch, z5524.kicad_pcb]
2024-10-04 update title block, resolve silkscreen overlap
    [as3394.kicad_sch, dac_2130.kicad_sch, dac_3394.kicad_sch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]
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2024-10-24 fix spi mode stuff that was used for caching
2024-10-24 remove magic numbers and use constants. This quick hack won't work on the z5524 where the 2nd vco and vcf is tuned. But it's a start
    [tune_mgr.c]
2024-11-04 some initial rantings on the poledancer schematic. Lots of work to do to figure out resonance and 2190 integration
    [dac_2140.kicad_sch, dac_2190.kicad_sch, filter_ssi2140.kicad_sch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]
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2024-11-08 think I got rez phase correct now. Still working on exp input circuit
    [filter_ssi2140.kicad_sch]
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2024-11-15 change direction on which pole to use with VCA. Trying it out
    [filter_ssi2140.kicad_sch]
2024-11-16 ditch moving the VCA cell to last position, keep it in position 2. More VCA mode offered that way. Other change is adding all JLCPCB components to fields
    [dac_2140.kicad_sch, dac_2190.kicad_sch, filter_ssi2140.kicad_sch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]
2024-11-17 figured a few things out after breadboarding 2190. Bigger R values for signals.
    [filter_ssi2140.kicad_sch, poledancer.kicad_pcb, poledancer.kicad_sch]
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2024-11-21 checkpoint before changing some direction on this. The resonance compensation is completely bonkers wrong. Need to address that.
    [filter_ssi2140.kicad_sch]
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2024-11-25 swap some instances around for better routing
    [dac_2190.kicad_sch, filter_ssi2140.kicad_sch, poledancer.kicad_pcb]
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2024-12-10 some basic stuff for pole dancer vcv rack module. Also complete the Raspberry Pi driver with empty autotune functions
    [zoxnoxiousd.cfg]
2024-12-13 add button lights to Rack and fix RPi Pole Dancer driver
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2024-12-18 fix label error between pole2/pole4 in DAC channels in schematic. no layout change.
    [dac_2190.kicad_sch, poledancer.kicad_pcb]
2024-12-18 update Rack & Pi drivers for pole4/pole2 swap
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2024-12-30 correct comment about rez comp in schematic
    [filter_ssi2140.kicad_sch]
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2025-02-03 updates for v0.5. Fix range for autotune. Noise level improved. Modulation range increased.
    [dac.kicad_sch, filter_as3372.kicad_sch, z3372.kicad_pcb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]
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2025-02-06 checkpoint for z3340 v0.9. Fixed lm4040 resistor, exp modulation level; removed polygons from routing
    [dac.kicad_sch, output_mix.kicad_sch, vco3340.kicad_sch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]
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2025-02-11 changed linear mod amount for z3340, from tame to wild now. Updated poledancer 2140, better DAC RC filter (higher freq) for 2190.
    [dac_2190.kicad_sch, filter_ssi2140.kicad_sch, vco3340.kicad_sch]
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2025-03-07 updated gerber files for pole dancer and updated tooling holes for all designs
    [poledancer-B_Cu.gbr, poledancer-B_Mask.gbr, poledancer-B_Silkscreen.gbr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]
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2025-04-01 zoxnoxiousd pi app: Up SPI rate to 30Mhz (though my scope shows it at 50Mhz). Add mlockall() to ensure pages locked in main memory. Change buffer sizes to account for 8kHz sampling rate. That's right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
    [zoxnoxiousd.cfg]
2025-04-01 change midi timeout to 10ms (was 10 _seconds_!). Fix SPI towards 28MHz to be in-spec for AD5328.
    [zoxnoxiousd.c]
2025-04-03 alsa no longer blocks on pcm stream unavailable. Allow zoxnoxiousd to cleanly exit even if no audio device. w00t
    [zoxnoxiousd.c]
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2025-04-22 schematic for backplane v0.3: change Pi GPIOs for SPI; switch output jacks; add external input
    [bus_conn.kicad_sch, level_shifting.kicad_sch, output_select.kicad_sch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]
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2025-05-11 tightening up placement
    [level_shifting.kicad_sch, vca_backplane.kicad_pcb, vca_backplane.kicad_sch]
2025-05-19 add external input sheet. Basic routing on backplane done- needs cleaning up
    [external_input.kicad_sch, level_shifting.kicad_sch, output_select.kicad_sch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]
2025-05-20 cleanup in progress- looking to change how the SPI lines are buffered
    [vca_backplane.kicad_pcb]
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2025-11-19 move some stuff around for some minor changes. The 2203 WR looks fine based on Capcom's Commando schematics
    [z2203.kicad_pcb, z2203.kicad_sch]
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2025-12-30 calloc args were reversed...and that worked for how long?
    [card_manager.c]
2026-01-06 vca calibration read from I2C and create correction tables
    [card_manager.c]
2026-01-06 replace printf with zlog info/warn/error messages
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2026-01-15 correctly free VCA DAC calibration memory
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2026-01-18 allow startup when cards EEPROM is uninitialized, skipping that card
    [card_manager.c]
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2026-02-08 attach lights working. Formatting across files/indentation fixed.
    [Zoxnoxious3340.cpp]
2026-02-09 change participant based on fixed number of slots and how they are used
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2026-02-17 cleanup: midi sysex messages were fixed so made them static
    [AudioMidi.hpp, Zoxnoxious3340.cpp]
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2026-02-18 add status light for AudioIO; delete buttonParamMidiProgram since it is no longer needed
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2026-02-25 add slot number to participant properties. Fix bug in 3340 selector / num cards
    [Zoxnoxious3340.cpp, common.hpp]
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2026-03-06 calling this good for now basic functionality for 3340. tackle some multithreading issues next
    [Zoxnoxious3340.cpp]
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2026-03-16 nasty index bug where a skipped slot screws things up
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2026-04-30 fix normalled behavior to actual VCA like. Com Status --> Module Link
    [Zoxnoxious3340.cpp, common.hpp]
2026-05-01 fix sync buttons that were swapped. And COM STATUS --> MODULE LINK
    [Zoxnoxious3340.cpp]
2026-05-02 hacked the textfield display for a substring. It isn't the right way to do it. Fixed geometry in AudioIO
    [zcomponentlib.hpp]
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2026-05-14 fix incorrect slots reported in patch usage LEDs
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2026-05-23 strengthen a couple lines in the workbench display
2026-06-10 fix slug on presets; fix font handle caching bug
    [TurnsCountingKnob.hpp, zcomponentlib.hpp]
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2026-06-20 start playing with weights -- and it's completely wrong right now
    [Zoxnoxious3340.cpp]
2026-06-20 tighten edge weights; GraphPort now OUT1 and OUT2; z3340 does weights
    [Zoxnoxious3340.cpp]
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2026-07-03 add external to visualizer. Introduce a findSlot() method because index on storage is not actually by slot. This needs to be fixed. Also need to fix how OUT GraphPorts are specified- it's rewritten b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
    [Zoxnoxious3340.cpp]
2026-07-04 tighten vertical on display buttons
2026-07-17 cleanup makefile on rasp pi side. Fixup Pi gadget mode script. Tighten the routing a bit in VCV Rack.
2026-08-03 makefile correctly target newer audio_io board; usb gadgets created with new UAC2 config; zoxnoxious config updated to reflect new device names
    [zoxnoxiousd.cfg]
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2026-08-19 card drivers now report SPI writes per call; start moving around zoxnoxiousd timers for better profiling
    [zoxnoxiousd.cfg]
2026-08-22 correctly handle pi drivers cache of values <0
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2026-09-07 fix print formatting
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2026-10-03 massive rework of the ALSA layer to be non-blocking. Remove unnecessary waits from the ALSA codepaths. Change the zoxnoxiousd to the new interface. Minor: add close the midi filehandles.
    [zoxnoxiousd.c]
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
